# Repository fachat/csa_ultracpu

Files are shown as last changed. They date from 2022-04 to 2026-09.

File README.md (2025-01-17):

# Ultra-CPU

Note: this is a part of a larger set of repositories, with [upet_family](https://github.com/fachat/upet_family) as the main repository.

This is the CPU board for a re-incarnation of the Commodore PET or other computer(s) from the later 1970s.

It is build on a Eurocard board and has only parts that can still be obtained new in 2024.
It uses the [CS/A bus interface](http://www.6502.org/users/andre/csa/index.html) to use other I/O boards.

As the memory mapping is programmable using the FPGA on the board, multiple types of computers can
potentially re-created. I started with my favourite one, the Commodore PET.

The reason this board is called Ultra-CPU is because it can potentially be used to recreate not only the Commodore PET.
The downside compared to the Micro-PET is, that it needs a separate I/O board to re-create a Commodore PET.
This can be found [here on my CS/A page](http://www.6502.org/users/andre/csa/petio/index.html).

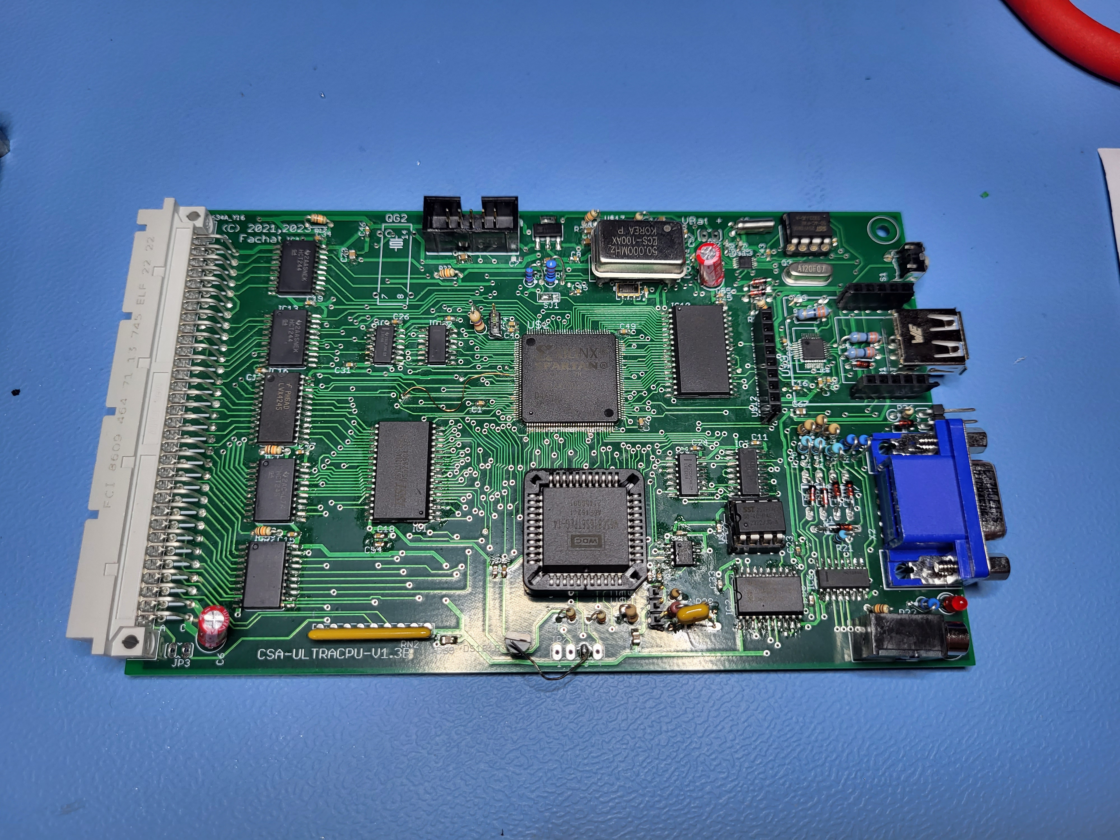
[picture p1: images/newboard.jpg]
The board


## Features

The board is built with a number of features:

- Commodore 3032 / 4032 / 8032 / 8296 with options menu to select at boot
  - Boot-menu to select different PET versions to run (BASIC 1, 2, 4)
  - 40 col character display
  - 80 col character display
- Improved system design:
  - 512k video RAM, plus 512k fast RAM, accessible using banks on the W65816 CPU
  - boot from an SPI Flash ROM
  - up to 17.5 MHz mode (via configuration register)
  - Write protection for the PET ROMs once copied to RAM
  - lower 32k RAM mappable from all of the 512k fast RAM
- Improved Video output:
  - VGA color video output (RGBI in 768x576 mode)
  - based on 720x576@60Hz VGA video timing (i.e. including borders at 40/80 columns)
  - modifyable character set
  - 40/80 column display switchable
  - 25/50 rows display switch
  - multiple video pages mappable to $8000 video mem address
  - Mulitple colour modes (Colour-PET, C128 VDC-compatible, Multicolour)
  - Colour Hires (VDC-compatible, Multicolour)
  - 16 colours out of a colour palette of 64 colours displayed simultaneously.
- DAC audio output
  - DMA engine to play audio samples on stereo sound output
- Built-in extra hardware:
  - USB host mode interface (for keyboard / mouse)
  - Real-Time-Clock (battery-buffered)
  - Ethernet/Wifi (via Breakout board)
  - SD-Card (via Breakout board)
- CS/A bus interface
  - multiple options to use bus devices, e.g. in I/O window
  - Together with [Ultra-Bus](https://github.com/fachat/csa_ultrabus) backplane Apple-II and RC2014 devices can be used

## Overview

The system architecture is actually rather simple, as you can see in the following graphics.

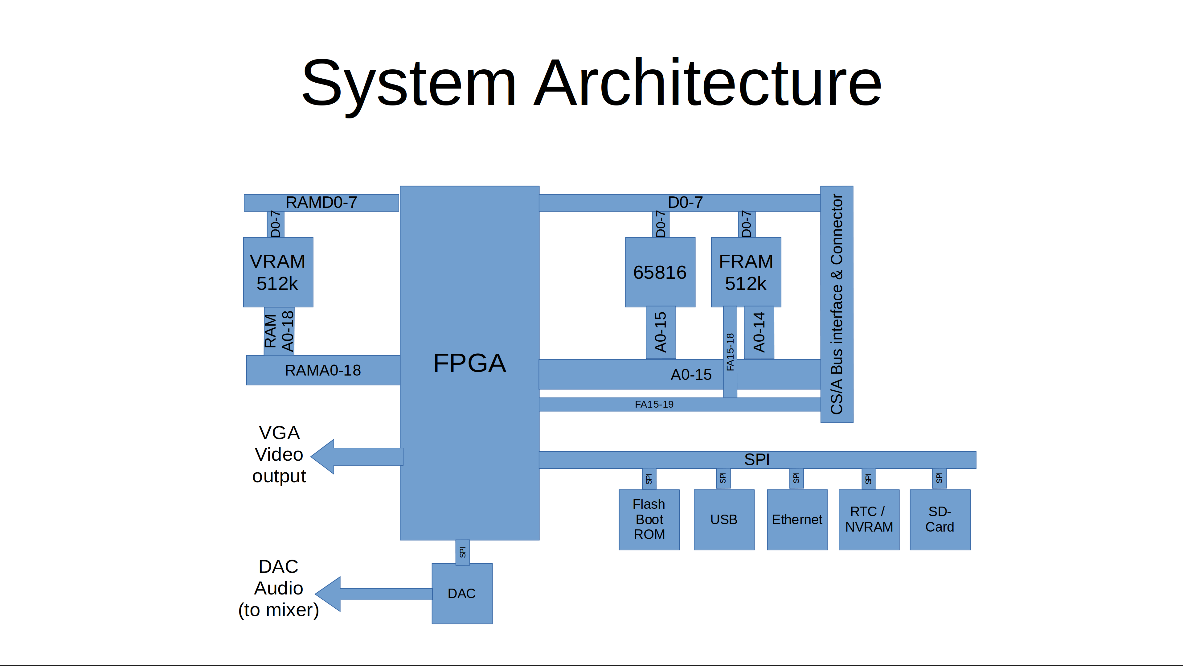
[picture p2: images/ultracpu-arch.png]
Ultra-CPU System Architecture


The main functionality is "hidden" inside the FPGA. It does:

1. clock generation and management
2. memory mapping
3. video generation.
4. SPI interface and boot

On the CPU side of the FPGA it is actually a rather almost normal 65816 computer, 
with the exception that the bank register (that catches and stores the address lines 
A16-23 from the CPU's data bus) is in the FPGA, and that there is no ROM. The ROM has been
replaced with some code in the FPGA that copies the initial program to the CPU accessible
RAM, taking it from the Flash Boot ROM via SPI. This actually simplifies the design,
as 

1. parallel ROMs are getting harder to come by and
2. they are typically not as fast as is needed, and
3. with the SPI boot they don't occupy valuable CPU address space.

The video generation is done using time-sharing access to the video RAM.
The VGA output is 720x576 at 50Hz. So there is a pixel clock of 27MHz.

The system runs at 13.5MHz, so a byte of pixel output (i.e. eight pixels) has four
memory accesses to VRAM. Two of them are reserved for video access, one for fetching the
character data (e.g. at $08xxx in the PET), and the second one to fetch the "character ROM"
data, i.e. the pixel data for a character. This is also stored in VRAM, and is being loaded
there from the Flash Boot ROM by the initial boot loader.

The FPGA reads the character data, stores it to fetch the character pixel data, and streams
that out using its internal video shift register.

For more detailled descriptions of the features and how to use them, pls see the 
[FPGA repository](https://github.com/fachat/upet_fpga),
as described in the next section.

## Version History

- [Revision 2.1A](https://github.com/fachat/csa_ultracpu/tree/r2.1a): Version using a Spartan 6 FPGA
- [Revision 1.3C](https://github.com/fachat/csa_ultracpu/tree/r1.3c): first working version using a Spartan 3E FPGA
- [Revision 1.2B](https://github.com/fachat/csa_ultracpu/tree/csa_ultracpu_1.2b): Version with CPLD and external colour generation.

## Known Issues

The following issues have been identified:

* Audio quality

Below are the fixes for these. Note, these are NOT yet in the BOM.

### Audio quality

The DAC audio output is not linear with the given schematics. This can be fixed by

* removing R30 and R32
* replace C3 and C10 with a 22uF  electrolytic cap. Orient minus pole to the output connector

## Building

Here are three subdirectories:

- [Board](Board/) That contains the board schematics and layout
- [Demo](Demo/) Some demo programs
- [tests](tests/) Some test programs

- [FPGA code](https://github.com/fachat/upet_fpga) This separate repository contains the VHDL code to program the FPGA logic chip used, and describes the configuration options - including the SPI and DAC usage and the Video feature and register description.
- [ROM](https://github.com/fachat/upet_roms) This separate repository contains the ROM contents to boot

### Board

To build the board, you have to find a provider that builds PCBs from Eagle .brd files.
Additionally, gerber files and a full Bill-of-material are provided in the Board subdirectory.

### FPGA

The FPGA is a Xilinx Spartan 6 programmable logic chip. It runs on 3.3V, 
so the bus interface has to convert between 3.3V and 5V. Compared to previous versions and the Micro-PET, also
the RAM and CPU on this board run on 3.3V now.
The FPGA logic here is programmed in VHDL.

The FPGA programming is actually stored in an SPI Flash Prom, so makes re-creating it even easier compared to 
the previous versions that used a CPLD - the CPLD required a separate programmer, now a (serial) Flash programmer suffices.

### ROM

The ROM image can be built using gcc, xa65, and make. Use your favourite EPROM programmer to burn it into the SPI Flash chip.

The ROM contains images of all required ROM images for BASIC 1, 2, and 4, and corresponding editor ROMs, including
some that have been extended with wedges and colour-PET functionality.

The updated editor ROMs are from [Steve's Editor ROM project](http://www.6502.org/users/sjgray/projects/editrom/index.html) and can handle C64 keyboards, has a DOS wedge included, and resets into the Micro-PET boot menu.

For more details see the [ROM repository](https://github.com/fachat/upet_roms)

## Gallery

### The system

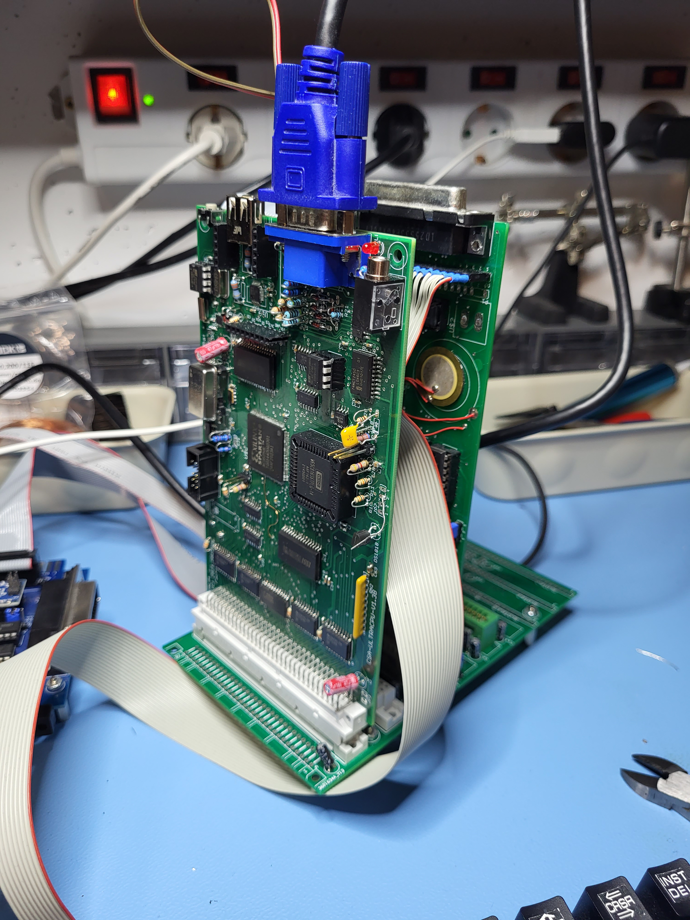
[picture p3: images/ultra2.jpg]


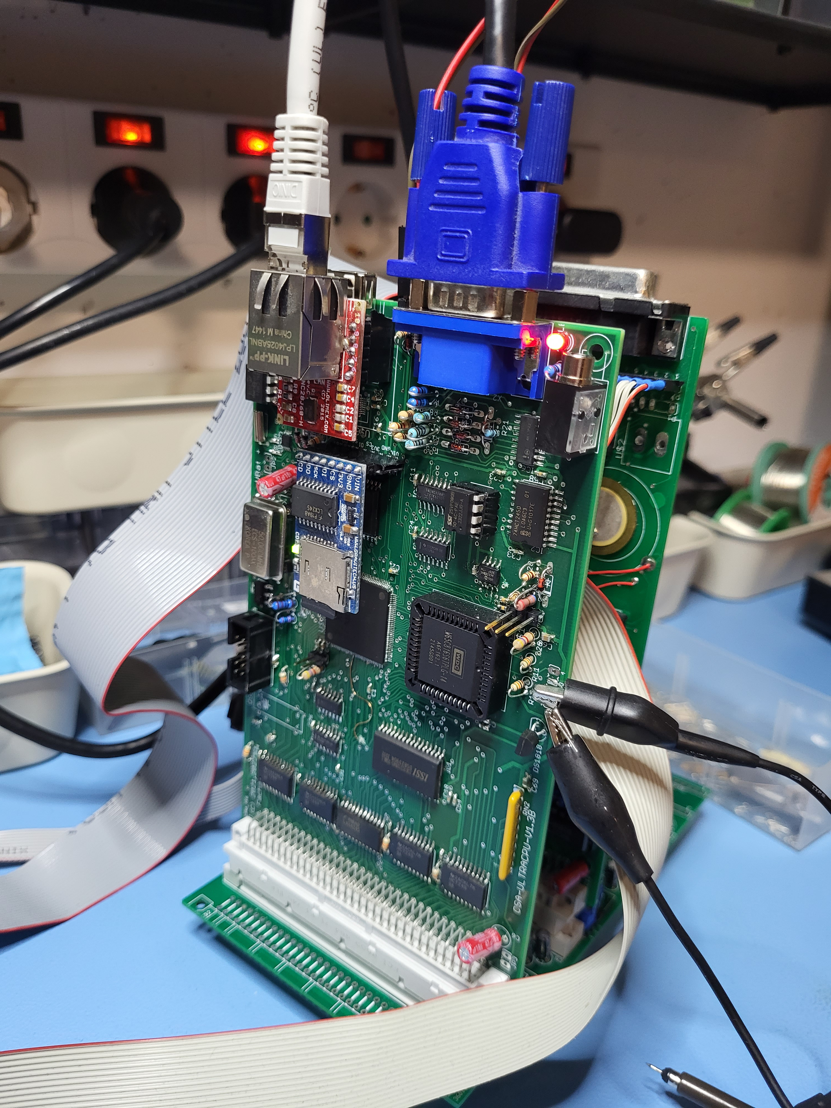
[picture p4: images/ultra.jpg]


### Graphics feature overview

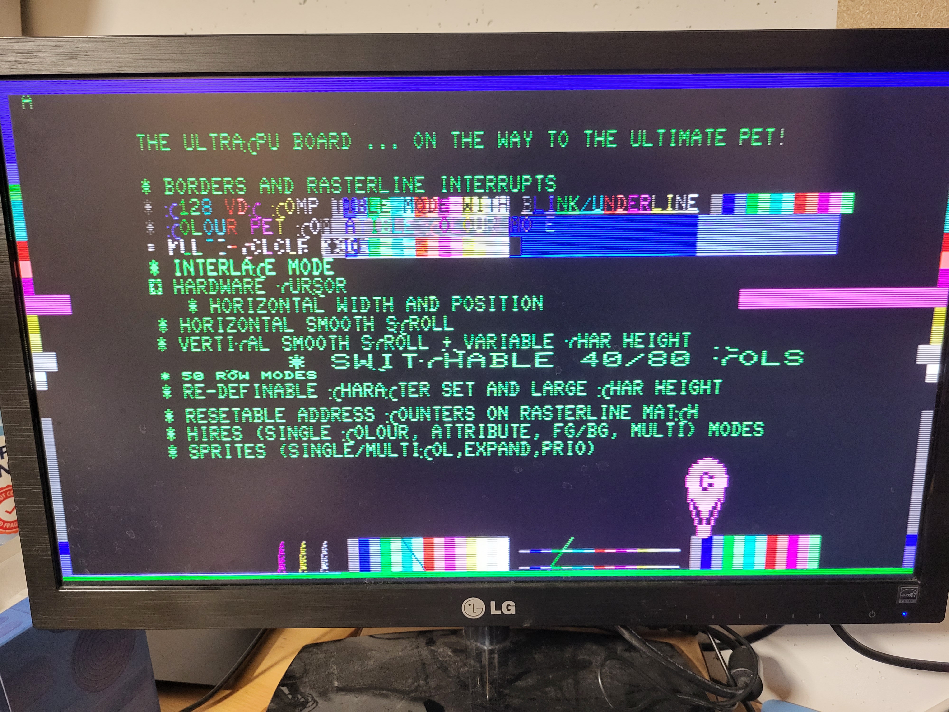
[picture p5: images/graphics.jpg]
Graphics feature overview


Note that this version is without the (optional) "Brown Fix" that is included in version 1.0B of the board.

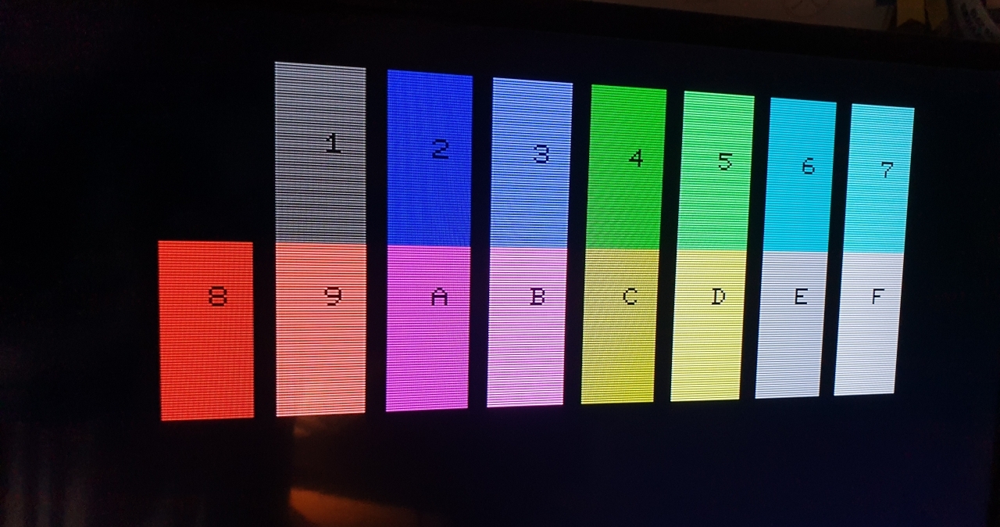
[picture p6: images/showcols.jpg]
Colour palette


### Board

The board

### Boot menu and OS boot screen

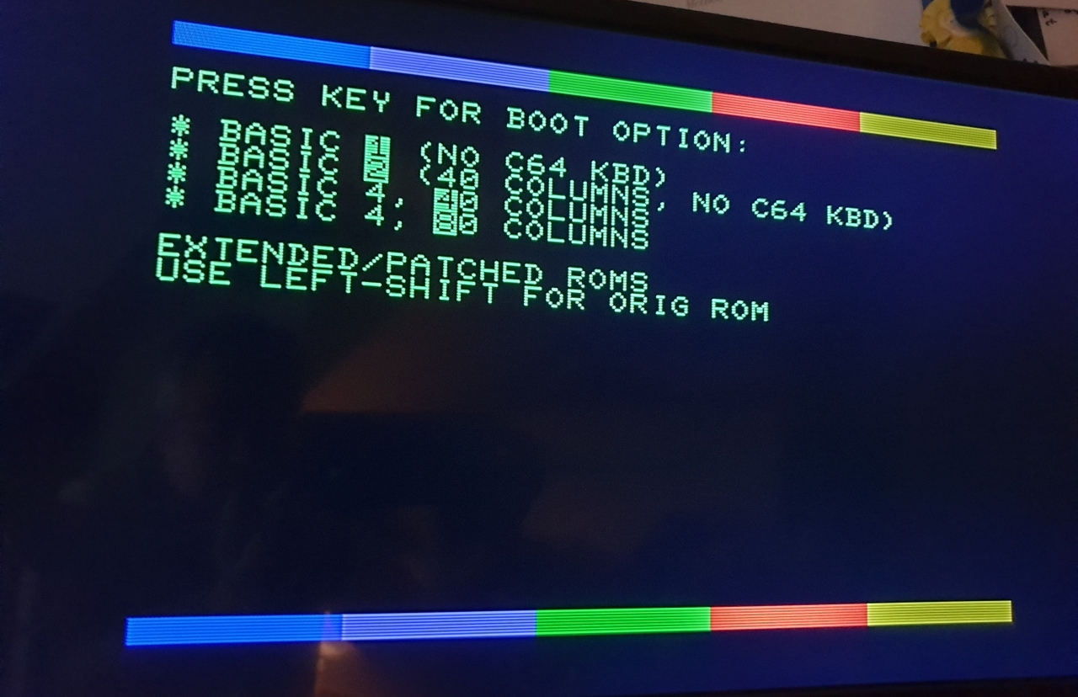
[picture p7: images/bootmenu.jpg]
Boot menu


OS Boot screen

### V1.2 system views

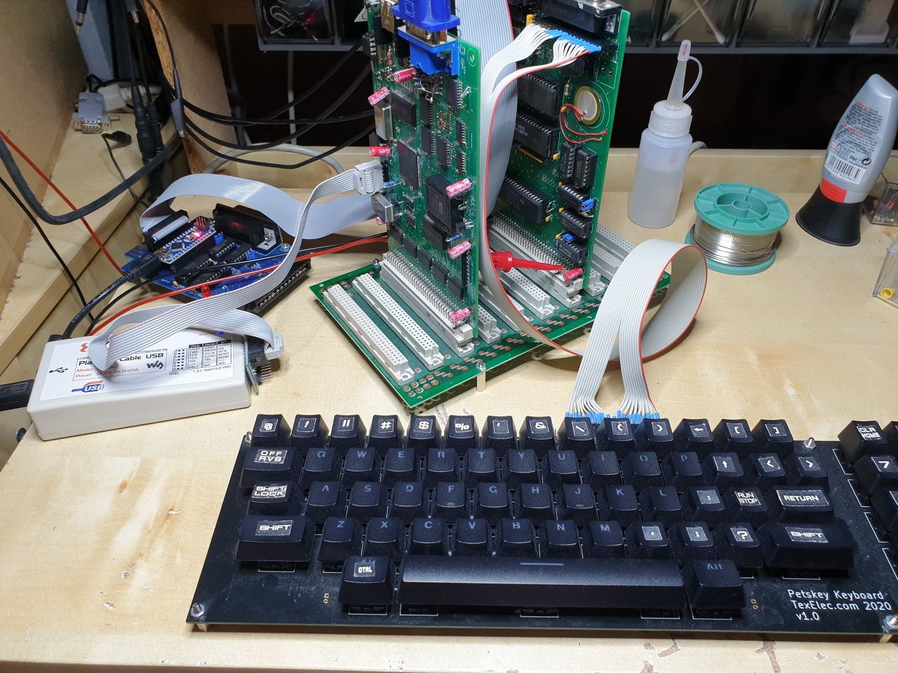
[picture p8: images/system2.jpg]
A full system with nano488 disk and keyboard


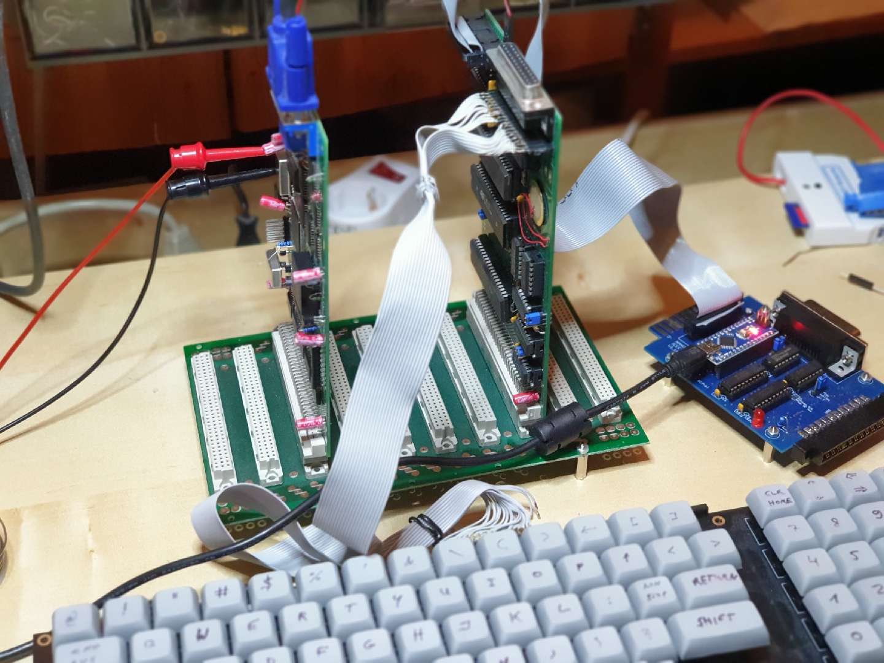
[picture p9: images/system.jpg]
Another view of a full system with nano488 disk and keyboard


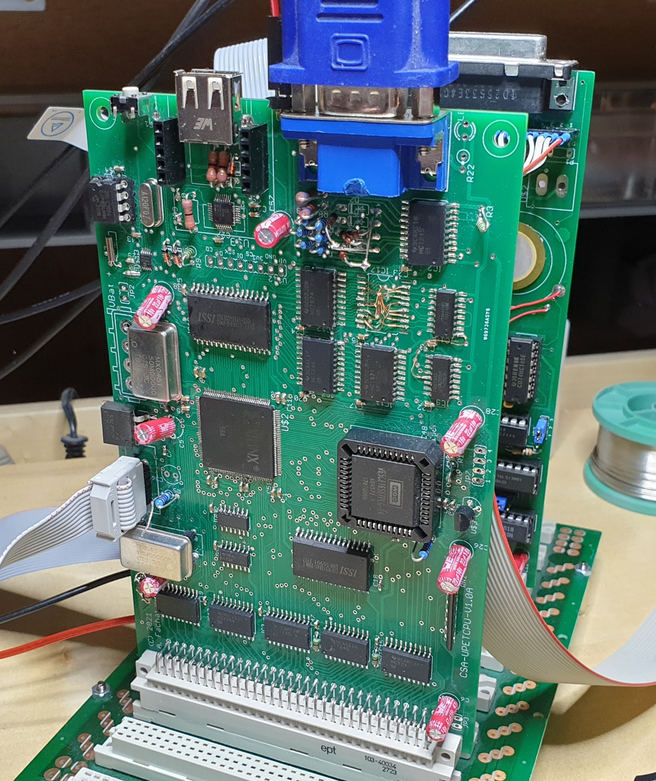
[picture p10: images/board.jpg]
Picture of an (V1.2) Ultra-CPU board


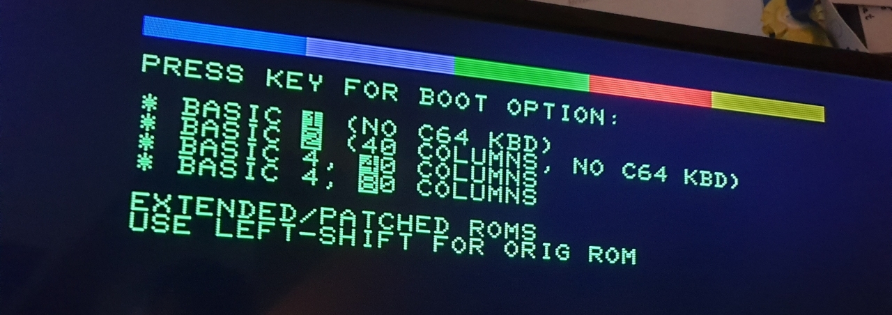
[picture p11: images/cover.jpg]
Picture of an (V1.2) Ultra-CPU board with PETIO board


### Debugging during development

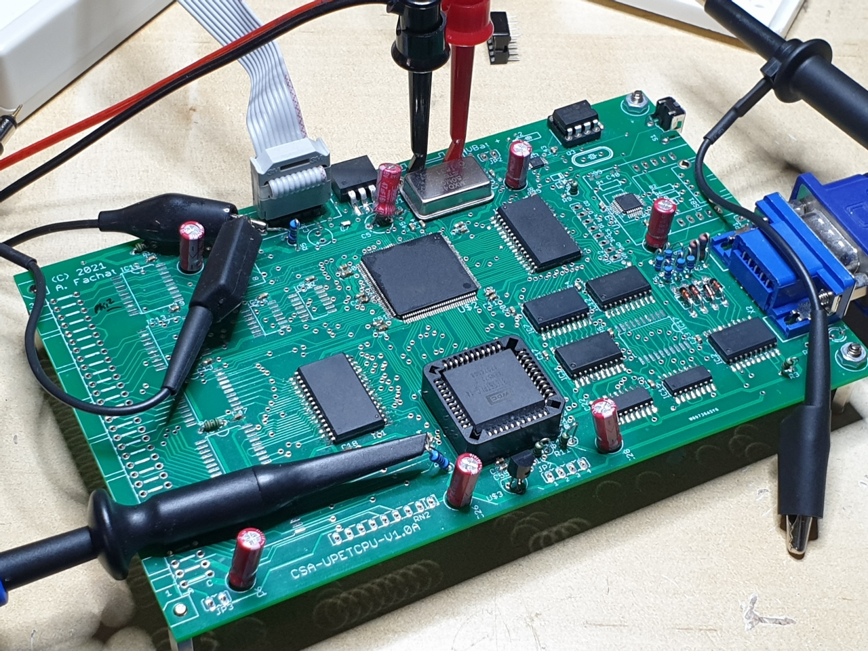
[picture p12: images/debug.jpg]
debug


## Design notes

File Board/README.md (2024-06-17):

# Board

The board is a two-layer Eurocard, i.e. 160mm x 100mm.

## Schematics & Layout

The schematics and layout have been created with Cadsoft Eagle.
So, here you can find the 

- [csa_ultracpu.sch](csa_ultracpu.sch) and
- [csa_ultracpu.brd](csa_ultracpu.brd) files

But, you can still have a look at the schematics and layout using the
PNG images created

- [csa_ultracpu_v2.0b-sch-1.png](csa_ultracpu_v2.0b-sch-1.png) Part 1 - CS/A Bus interface
- [csa_ultracpu_v2.0b-sch-2.png](csa_ultracpu_v2.0b-sch-2.png) Part 2 - CPLD, CPU, Fast RAM
- [csa_ultracpu_v2.0b-sch-3.png](csa_ultracpu_v2.0b-sch-3.png) Part 3 - Power
- [csa_ultracpu_v2.0b-sch-4.png](csa_ultracpu_v2.0b-sch-4.png) Part 4 - Video and Audio output
- [csa_ultracpu_v2.0b-sch-5.png](csa_ultracpu_v2.0b-sch-5.png) Part 5 - SPI devices (Eth, USB, RTCC, ...)
- [csa_ultracpu_v2.0b-sch-6.png](csa_ultracpu_v2.0b-sch-6.png) Part 6 - Video RAM, data fetch and shift register

- [csa_ultracpu_v2.0b-layout.png](csa_ultracpu_v2.0b-layout.png) layout of the chips
- [csa_ultracpu_v2.0b-brd.png](csa_ultracpu_v2.0b-brd.png) layout of the traces

## Bill of Material

The main chips are:

- 1x W65816S CPU
- 1x x Spartan 6 FPGA
- 2x 8x512k parallel SRAM with 25ns access time
- Several ICs for Video generation
- several ICs for the bus interface
- 1x DS1813 RESET controller

- 70 MHZ crystal oscillator
- 16 MHZ crystal oscillator (bus clock - may be optional)

- Voltage regulators

- bypass caps

- 1x LM2937-3.3V SOT
- div. resistors/caps to generate 3.3V output

More details can be found in the [Eagle parts list](csa_ultracpu.csv).

A full [BOM](csa_ultracpu_BOM.xlsx) with parts numbers from Mouser is now provided as well.

## Changelog

### V2.0B

This moves from the Spartan 3 to a Spartan 6, increases clock speed to 70 MHz for a 
higher resolutoin video output, and more.

### V1.3C

This is a technology change of the programmable logic from the CPLD to an FPGA.
The FPGA has the same footprint, but much more space for logic inside. 
This allowed to integrate proper colour support, bitmaps, sprites, and many more
graphics features. A DAC allows outputting digital sound. 

### V1.0B

This fixes couple of things I found in V1.0A:

- The order of the color/intensity signals was the wrong way around
- The A/B and G inputs of IC15 had been accidently swapped
- An optional second color buffer has been removed as timing was good enough for it not be needed
- An optional "brown fix" has been added.
- On the board, two bypass caps were placed under the CPU socket
- On the board, the JP1 connector has been turned 180 degrees to confirm existing boards

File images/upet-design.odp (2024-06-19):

## System Architecture

FA15-18

A0-15

D0-7

SPI

SPI

SPI

SPI

SPI

SPI

D0-7

RAM
A0-18

D0-7

CS/A Bus interface & Connector

A0-14

VRAM

512k

RAMD0-7

FPGA

D0-7

65816

FRAM

512k

RAMA0-18

VGA

Video

output

DAC

Audio

(to mixer)

A0-15

FA15-19

SPI

Flash
Boot
ROM

USB

Ethernet

RTC /
NVRAM

SD-
Card

DAC

## Memory Map (boot)

ipl

ipl

CPU address space (lower 1M)

64k
bank0

Banks 0 … 7

Banks 8 … 15

64k
bank0

64k 8296

Ext. bank

Banks 2 … 7

64k video
bank

Banks 9 … 15

512k FRAM

Physical address space

The CPLD can only write (the IPL code from Flash) to VRAM, so the initial

Mapping maps VRAM to banks 0-7 of the CPU

512k VRAM

## Memory Map

CPU address space (lower 1M)

0-32k

32-
64k

Banks 1 … 15

Any of 16

32k blocks

In FRAM

4k
V

Bank 0, or

8296 mem expansion

In bank 1

Any of four 2k positions in video bank

8k
Chr

rom

8k
Chr

64k
bank0

64k 8296

Ext. bank

Banks 2 … 7

64k video
bank

Banks 9 … 15

512k FRAM

Physical address space

512k VRAM

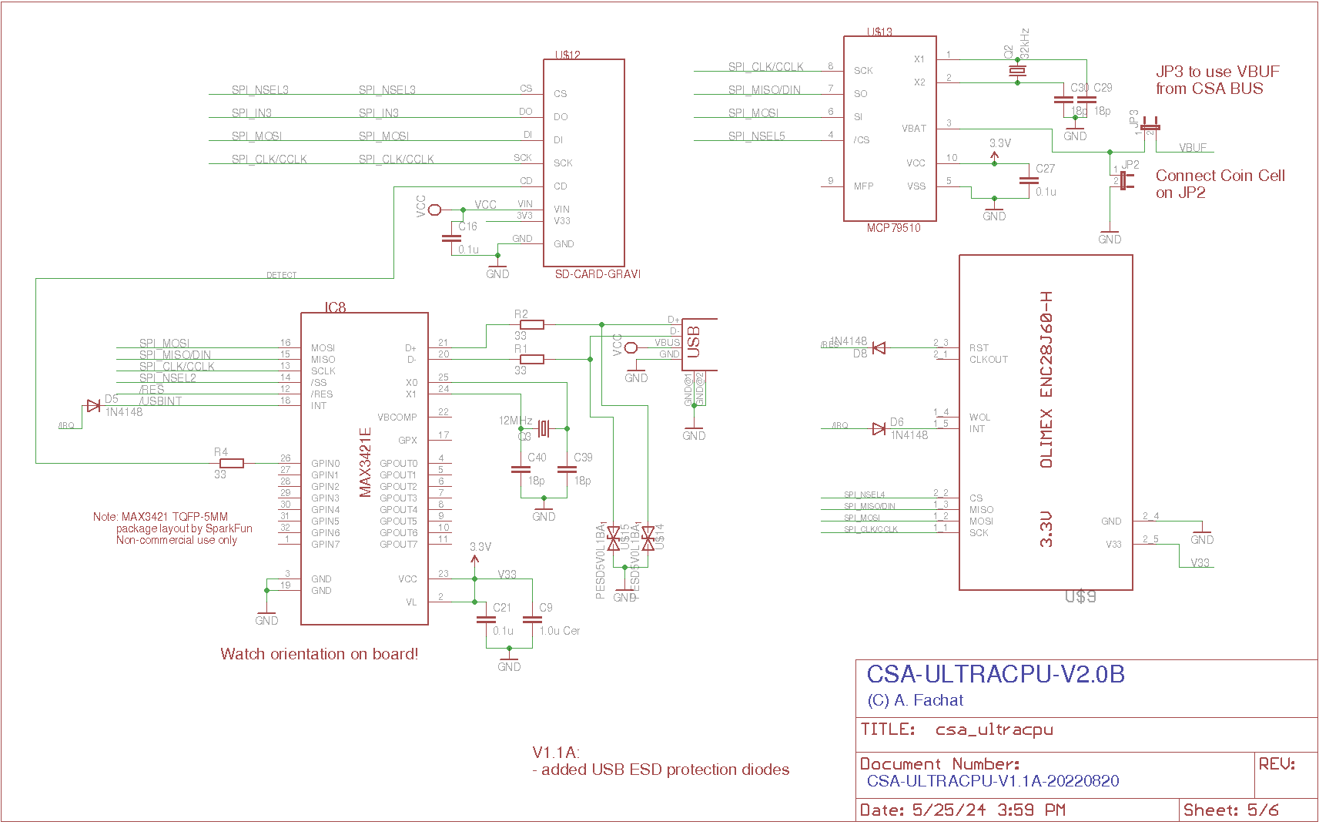
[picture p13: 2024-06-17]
Board/csa_ultracpu-v2.0b-sch-5.png

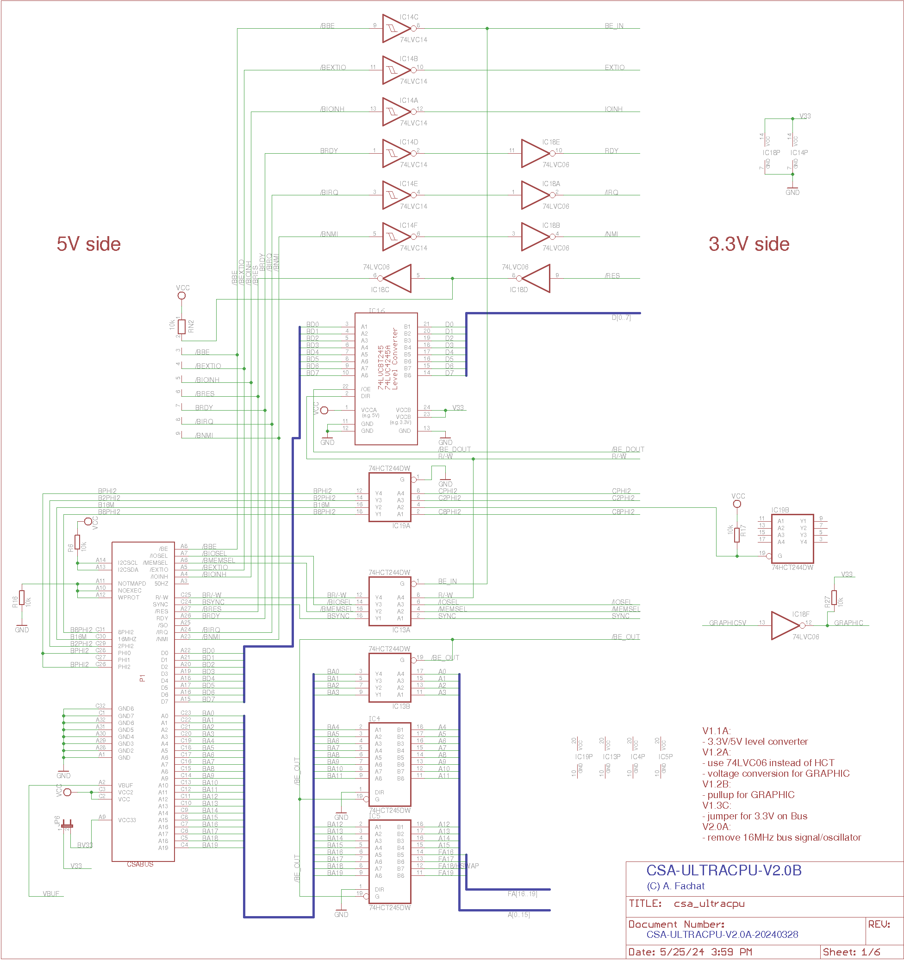
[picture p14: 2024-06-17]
Board/csa_ultracpu-v2.0b-sch-1.png

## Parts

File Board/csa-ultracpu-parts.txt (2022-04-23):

Partlist

Exported from csa_ultracpu.sch at 4/17/22 9:51 PM

EAGLE Version 6.4.0 Copyright (c) 1988-2013 CadSoft

Assembly variant: 

Part     Value              Device             Package          Library          Sheet

C1       0.1u               C-EUC0603          C0603            rcl              3
C2       0.1u               C-EUC0603          C0603            rcl              3
C3       0.1u               C-EUC0603          C0603            rcl              3
C4       0.1u               C-EUC0603          C0603            rcl              3
C5       47u                CPOL-EUE5-6        E5-6             rcl              3
C6       47u                CPOL-EUE2.5-6      E2,5-6           rcl              3
C7       100n               C-EUC0603          C0603            rcl              3
C8       100n               C-EUC0603          C0603            rcl              3
C9       1.0u Cer           C-EUC0603          C0603            rcl              5
C10      1u                 C-EUC0603          C0603            rcl              3
C11      1u                 C-EUC0603          C0603            rcl              3
C12      0.1u               C-EUC0603          C0603            rcl              3
C13      0.1u               C-EUC0603          C0603            rcl              3
C14      0.1u               C-EUC0603          C0603            rcl              3
C15      0.1u               C-EUC0603          C0603            rcl              3
C16      0.1u               C-EUC0603          C0603            rcl              5
C17      0.1u               C-EUC0603          C0603            rcl              3
C18      0.1u               C-EUC0603          C0603            rcl              3
C19      0.1u               C-EUC0603          C0603            rcl              3
C20      0.1u               C-EUC0603          C0603            rcl              3
C21      0.1u               C-EUC0603          C0603            rcl              5
C22      0.1u               C-EUC0603          C0603            rcl              3
C23      0.1u               C-EUC0603          C0603            rcl              3
C24      0.1u               C-EUC0603          C0603            rcl              3
C25      0.1u               C-EUC0603          C0603            rcl              3
C26      47u                CPOL-EUE2.5-6      E2,5-6           rcl              3
C27      0.1u               C-EUC0603          C0603            rcl              5
C28      22u                CPOL-EUE2.5-6      E2,5-6           rcl              3
C29      18p                C-EUC0603          C0603            rcl              5
C30      18p                C-EUC0603          C0603            rcl              5
C31      0.1u               C-EUC0603          C0603            rcl              3
C32      0.1u               C-EUC0603          C0603            rcl              3
C33      0.1u               C-EUC0603          C0603            rcl              3
C34      0.1u               C-EUC0603          C0603            rcl              3
C35      0.1u               C-EUC0603          C0603            rcl              3
C36      22u                CPOL-EUE2.5-6      E2,5-6           rcl              3
C37      22u                CPOL-EUE2.5-6      E2,5-6           rcl              3
C38      22u                CPOL-EUE2.5-6      E2,5-6           rcl              3
C39      18p                C-EUC0603          C0603            rcl              5
C40      18p                C-EUC0603          C0603            rcl              5
C41      0.1u               C-EUC0603          C0603            rcl              3
C42      0.1u               C-EUC0603          C0603            rcl              3
C43      0.1u               C-EUC0603          C0603            rcl              3
C44      0.1u               C-EUC0603          C0603            rcl              3
C45      0.1u               C-EUC0603          C0603            rcl              3
C46      0.1u               C-EUC0603          C0603            rcl              3
C47      0.1u               C-EUC0603          C0603            rcl              3
C48      0.1u               C-EUC0603          C0603            rcl              3
C49      1u                 C-EUC0603          C0603            rcl              3
C50      1u                 C-EUC0603          C0603            rcl              3
C51      1u                 C-EUC0603          C0603            rcl              3
C52      0.1u               C-EUC0603          C0603            rcl              3
C53      1u                 C-EUC0603          C0603            rcl              3
C54      1u                 C-EUC0603          C0603            rcl              3
C55      1u                 C-EUC0603          C0603            rcl              3
C56      1u                 C-EUC0603          C0603            rcl              3
C57      22u                CPOL-EUE2.5-6      E2,5-6           rcl              3
C58      0.1u               C-EUC0603          C0603            rcl              3
D1       1N4148DO35-7       1N4148DO35-7       DO35-7           diode            4
D2       1N4148DO35-7       1N4148DO35-7       DO35-7           diode            4
D3       1N4148DO35-7       1N4148DO35-7       DO35-7           diode            4
D4       1N4148DO35-7       1N4148DO35-7       DO35-7           diode            4
D5       1N4148             DIODE-D-5          D-5              diode            5
D6       1N4148             DIODE-D-5          D-5              diode            5
D7       1N4148DO35-7       1N4148DO35-7       DO35-7           diode            4
D8       1N4148             DIODE-D-5          D-5              diode            5
IC1      RAMSOCK32TO512KSOP RAMSOCK32TO512KSOP SOP32            csa              2
IC2      74LS245DW          74LS245DW          SO20W            74xx-eu          4
IC3      74LS245DW          74LS245DW          SO20W            74xx-eu          1
IC4      74LS245DW          74LS245DW          SO20W            74xx-eu          1
IC5      74LS245DW          74LS245DW          SO20W            74xx-eu          1
IC6      74ACT138D          74ACT138D          SO16             74xx-eu          4
IC7      74LS245DW          74LS245DW          SO20W            74xx-eu          6
IC8      MAX3421E           MAX3421E           TQFP32-5MM       csa              5
IC9      74LS166D           74LS166D           SO16             74xx-eu          6
IC10     RAMSOCK32TO512KSOP RAMSOCK32TO512KSOP SOP32            csa              6
IC11     74HCT574D          74HCT574D          SO20W            74xx-eu          6
IC12     74HCT574D          74HCT574D          SO20W            74xx-eu          6
IC13     74HCT244DW         74HCT244DW         SO20W            74xx-eu          1
IC14     74HCT14D           74HCT14D           SO14             74xx-eu          1
IC15     74HCT157D          74HCT157D          SO16             74xx-eu          6
IC18     74LS06D            74LS06D            SO14             74xx-eu          1
IC19     74HCT244DW         74HCT244DW         SO20W            74xx-eu          1
J1                          FLOPPY-4350211     350211           con-amp          3
JP1                         JP1E               JP1              jumper           2
JP2                         JP1E               JP1              jumper           5
JP3                         JP1E               JP1              jumper           5
JP7                         JP4E               JP4              jumper           2
LED1                        LED3MM             LED3MM           led              3
P1       CSABUS             CSABUS             CSABUS           csa              1
Q2       32kHz              CRYSTALTC26H       TC26H            crystal          5
Q3       12MHz              CRYSTALHC49S       HC49/S           crystal          5
QG1      50MHz              CRYSTAL_RES-SG51   SG51             crystal          2
QG2      16MHz              CRYSTAL_RES-SG51   SG51             crystal          1
R1       33                 R-EU_0204/7        0204/7           rcl              5
R2       33                 R-EU_0204/7        0204/7           rcl              5
R3       10k                R-EU_0204/2V       0204V            rcl              4
R4       33                 R-EU_0204/7        0204/7           rcl              5
R5       1k                 R-EU_0207/2V       0207/2V          rcl              2
R6       10k                R-EU_0204/5        0204/5           rcl              1
R7       68                 R-EU_0204/2V       0204V            rcl              4
R8       68                 R-EU_0204/2V       0204V            rcl              4
R9       10k                R-EU_0207/2V       0207/2V          rcl              2
R10      10k                R-EU_0207/2V       0207/2V          rcl              2
R11      10k                R-EU_0207/2V       0207/2V          rcl              2
R12      1k                 R-EU_0207/2V       0207/2V          rcl              2
R13      470                R-EU_0204/2V       0204V            rcl              4
R14      470                R-EU_0204/2V       0204V            rcl              4
R15      470                R-EU_0204/2V       0204V            rcl              4
R16      10k                R-EU_0204/5        0204/5           rcl              1
R17      10k                R-EU_0204/5        0204/5           rcl              1
R18      1k                 R-EU_0204/2V       0204V            rcl              4
R19      1k                 R-EU_0204/2V       0204V            rcl              4
R20      1k                 R-EU_0204/2V       0204V            rcl              4
R21      2k                 R-EU_0204/2V       0204V            rcl              4
R22      390                R-EU_0207/2V       0207/2V          rcl              3
RN2      10k                RN08               RN-9             resistor-net     1
S1                          31-XX              B3F-31XX         switch-omron     3
TO1      LM2937SOT-3.3V     LM2937SOT          SOT223           csa              3
U$1      W65C816SPLCC       W65C816SPLCC       PLCC44           csa              2
U$2      XC95288XLTQ144     XC95288XLTQ144     TQFP144          csa              2
U$3      DS1813             DS1813             TO92             csa              3
U$4      SPIFLASH           SPIFLASH           DIL08            csa              2
U$7      XILINXPROG         XILINXPROG         FLAT10BOX        csa              2
U$9      ETHOLIENC          ETHOLIENC          ETHOLIENC        csa              5
U$12     SD-CARD-GRAVI      SD-CARD-GRAVI      GRAVITECH-SDCARD csa              5
U$13     MCP79510           MCP79510           MSOP10           csa              5
USB1     USB-A-H            USB-A-H            USB-A-H          con-usb-2        5
X2       D-SUB15-HDR15RA    D-SUB15-HDR15RA    HDR15RA          con-thomas-betts 4

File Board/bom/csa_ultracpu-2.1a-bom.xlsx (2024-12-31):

Id | Designator | Footprint |  | Orig. Quantity | Designation | Supplier and ref | MOUSER | Manufac. Part | Alt. Mouser | Alt. Manufac. Part | JLCPCB Part #（optional）
 | SMD
 | C2, C7, C8, C11, C12, C13, C15, C16, C17, C18, C19, C20, C21, C22, C24, C25, C26, C27, C28, C31, C32, C33, C34, C35, C36, C37, C41, C42, C43, C44, C45, C46, C47, C48, C58, C101, C102, C103, C104, C105, C106, C107, C108, C109, C110, C111, C112, C113, C121 | C0603 | 49 |  | 0.1u |  | 581-06033G104ZAT2AM | 06033G104ZAT2AM |  |  | C14663
 | C1, C4, C9, C14, C49, C54, C55, C56, C57, C120, C123 | C0603 | 11 |  | 1u |  | 791-0603B105K6R3CT | 0603B105K6R3CT | 80-C0603X105J8R | C0603X105J8RACTU | C309479
 | C5, C38,C64, C65, C66, C67, C68, C69, C70, C71 | C0805 | 10 |  | 22u |  | 187-CL21A226MPQNNNE | CL21A226MPQNNNE |  |  | C5674
 | C29, C30, C39, C40 | C0603 | 4 |  | 18p |  | 80-C0603C180K4HACTU | C0603C180K4HACTU |  |  | C152921
 | R3, R5, R6, R9, R10, R11, R12, R16, R17, R24, R25, R26, R27 | R_0805_2012Metric_Pad1.20x1.40mm_HandSolder | 13 |  | 10k |  | 279-CRGH0603J10K | CRGH0603J10K |  |  | C17414
 | R1, R2, R4 | R_0805_2012Metric_Pad1.20x1.40mm_HandSolder | 3 |  | 33 |  | 660-RK73H2ATTD33R0F | RK73H2ATTD33R0F |  |  | C17634
 | U1, U2 | TSOP-II-44_10.16x18.41mm_P0.8mm | 2 |  | IS61C5128AL-10TLI |  | 913-AS7C34096A-10TIN | AS7C34096A-10TIN |  |  | C5554776
 | X3 | Oscillator_SMD_SeikoEpson_SG8002CE-4Pin_3.2x2.5mm | 1 |  | 54MHz Oscrillator |  | 710-830207670409 | 830207670409 |  |  | C1672093
38 | U$14,U$6,U$10,U$5,U$8,U$11,U$15 | SOD323 | 7 |  | ESDBIDIR |  | 771-PESD5V0L1BA-T/R | PESD5V0L1BA,115 |  |  | C2687118
93 | IC5,IC2,IC4 | SO20W@1 | 3 |  | 74245DW |  | 595-SN74HCT245DWR | SN74HCT245DWR |  |  | C132267
64 | IC19,IC13 | SO20W@1 | 2 |  | 74244DW |  | 595-SN74HCT244DWRG4 | SN74HCT244DWRG4 |  |  | C6776
72 | IC3 | SO14@1 | 1 |  | 74125D |  | 595-SN74LVC125AD | SN74LVC125AD |  |  | C6057
109 | IC6 | SOT-23-5 | 1 |  | 74LVC1G04 |  | 595-SN74LVC1G04DBVR | SN74LVC1G04DBVR |  |  | C7434171
107 | IC7 | SO16 | 1 |  | 74138D |  | 771-74LVC138AD-T | 74LVC138AD,118 |  |  | C6061
68 | IC8 | PQFP-32_5x5mm_P0.5mm | 1 |  | MAX3421E |  | 700-MAX3421EEHJT | MAX3421EEHJ+T |  |  | C2651881
152 | IC14 | SO14 | 1 |  | 7414D |  | 595-SN74LV14ADR | SN74LV14ADR |  |  | C133541
57 | IC18 | SO14 | 1 |  | 7406D |  | 595-SN74LVC06ADR | SN74LVC06ADR |  |  | C7658
86 | IC16 | SO24L | 1 |  | 74LVC8T245SO24 |  | 595-SN74LVC4245ADW | SN74LVC4245ADW |  |  | C2677625
59 | SN1 | SOIC8 | 1 |  | MCP48X2 |  | 579-MCP4802-E/SN | MCP4802-E/SN |  |  | C144363
81 | U$2 | TQFP144 | 1 |  | XC6SLX9-TQG144 |  | 217-XC6SLX9-2TQG144C | XC6SLX9-2TQG144C |  |  | C415799
116 | U$3 | SOT223 | 2 |  | LDI1117 |  | 637-LDI1117-3.3H | LDI1117-3.3H |  |  | C6186
148 | U$13 | MSOP10 | 1 |  | MCP79510 |  | 579-MCP79510-I/MS | MCP79510-I/MS |  |  | C636437
3 | U$16 | PSOP-8-FIXED | 1 |  | AP2132BB |  | 621-AP2132BMP1.2TRG1 | AP2132BMP-1.2TRG1 |  |  | C338874
 | Pins and Jumper
11 | JP1, JP2, JP3, JP4, JP6, JP12, JP13 | JP1 | 0 | 7 | JP1E
26 | JP5 | JP2 | 0 | 1 | JP2E
35 | JP8, JP9, JP10, JP11 | PinHeader_1x01_P2.54mm_Vertical | 0 | 4 | Conn_01x01_Pin
112 | JP7 | JP4 | 0 | 1 | JP4E
 |  |  | 2 |  | pin strip straight 20 pin |  | 538-22-28-4204 | 22-28-4204 | 649-1012937892001BLF | 10129378-920001BLF
 | ICs
141 | U$1 | PLCC44 | 1 |  | W65C816SPLCC |  | 955-W65C816S6PLG-14 | W65C816S6PLG-14
43 | U$4,U$18 | DIL08 | 2 |  | SPIFLASH |  | 804-25VF080B5CPAE | SST25VF080B-50-4C-PAE
138 | DS1818 | TO92 | 1 |  | DS1813 |  | 700-DS1818-10T&R | DS1818-10+T&R
 | Capacitors
 | C3, C10 | C_Disc_D5.0mm_W2.5mm_P5.00mm | 2 |  | 1u MLCC |  | 810-FG28X5R1H105KRT0 | FG28X5R1H105KRT00
 | C6 | E2,5-6 | 1 |  | 47u |  | 710-860010372004 | 860010372004
 | Resistors
 | R7, R8 | 0204V | 2 |  | 68 |  | 660-MF1/4LCT52R680G | MF1/4LCT52R680G
 | R28, R31 | 0204V | 2 |  | 100 |  | 603-MFR-12FTF52-100R | MFR-12FTF52-100R
 | R29 | 0207_2V | 1 |  | 330 |  | 603-MFR-12FTF52-330R | MFR-12FTF52-330R
 | R22 | 0207_2V | 1 |  | 390 |  | 756-MFR3-390RFC | MFR3-390RFC | 603-MFR-25FBF52-390R | MFR-25FBF52-390R
 | R13, R14, R15 | 0204_7 | 3 |  | 470 |  | 708-RNF14FTD470R | RNF14FTD470R
 | R30, R32 | 0207_2V | 2 |  | 680 |  | 603-MFR-12FTF52-680R | MFR-12FTF52-680R
 | R18, R19, R20 | 0207_10 | 3 |  | 1k |  | 603-MFR-12FRF521K | MFR-12FRF52-1K | 603-MFR-12FTF52-1K | MFR-12FTF52-1K
54 | RN2 | RN-9 | 1 |  | 10k |  | 652-4609X-1LF-10K | 4609X-101-103LF
 | Diodes
 | D1, D2, D3, D4, D5,D6,D7,D8,D9, D10 | DO35-7 | 10 |  | 1N4148DO35-7 |  | 78-1N4148 | 1N4148TR | 512-1N4148 | 1N4148
23 | LED1 | LED3MM | 2 |  | LED3MM (Green – power) |  | 696-SSL-LX305F4GD | SSL-LX305F4GD
 | Connectors
98 | X1 | 1503_09 | 1 |  | 1503_09 |  | 490-SJ1-3515 | SJ1-3515 | 490-SJ1-3515N | SJ1-3515N
115 | X2 | HDR15RA | 1 |  | D-SUB15-HDR15RA |  | 523-7HDE15SD1CH4FVGA | L77HDE15SD1CH4FVGA
151 | U$7 | FLAT10BOX | 1 |  | XILINXPROG (optional) |  | 710-61201021621 | 61201021621
122 | U$9 | ETHOLIENC | 1 |  | ETHOLIENC (optional) |  | 909-ENC28J60-H | ENC28J60-H
 |  |  | 2 |  | Sockel |  | 200-SSW10501TS | SSW-105-01-T-S | 200-BCS105LSTE | BCS-105-L-S-TE
~~89~~ | ~~U$12~~ | ~~GRAVITECH-SDCARD~~ | 1 | ~~1~~ | ~~SD-CARD-GRAVI~~ |  | ~~992-MICROSD-ADP ~~ | ~~MICROSD-ADP ~~
 |  |  | 1 |  | Sockel |  | 200-BCS108LSTE | BCS-108-L-S-TE
99 | USB1 | USB-A-H | 1 |  | USB-A-H |  | 710-614004190021 | 614004190021
156 | P1 | CSABUS | 1 |  | CSABUS |  | 649-869464713745ELF | 86094647113745ELF |  |  | 649-869464713H45ELF | 86094647113H45ELF
 | Quartz
69 | Q2 | TC26H | 1 |  | 32kHz |  | 520-ECS-32-12.5-13X | ECS-.320-12.5-13X | 710-830002995B | 830002995B
136 | Q3 | HC49_S | 1 |  | 12MHz |  | 549-CYS6Q31C-12MHZ | CYS6Q31C-12.000MHZ
 | Switches
27 | S1 | B3F-31XX | 1 |  | 31-XX |  | 653-B3F-3122 | B3F-3122
 | Sockets
 |  |  | 2 |  | Socker 8 pin |  | 571-1-2199298-2 | 1-2199298-2
 |  |  | 1 |  | Socket 44 pin PLCC |  | 517-8444-11B1-RK-TP | 8444-11B1-RK-TP | 737-PLCC-44-AT | PLCC-44-AT
 | Extras

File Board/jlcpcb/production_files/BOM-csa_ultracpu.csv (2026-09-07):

Comment | Designator | Footprint | LCSC | Quantity
0.1u | C101,C102,C103,C104,C105,C106,C107,C108,C109,C11,C110,C111,C112,C113,C12,C121,C13,C15,C16,C17,C18,C19,C2,C20,C21,C22,C24,C25,C26,C27,C28,C31,C32,C34,C35,C36,C37,C41,C42,C43,C44,C45,C46,C47,C48,C58 | C0603 | C14663 | 46
100 | R28,R31 | R_0603_1608Metric_Pad0.98x0.95mm_HandSolder | C22775 | 2
100n | C50,C51,C52,C53,C59,C60,C61,C62,C63,C7,C72,C73,C8 | C_0603_1608Metric_Pad1.08x0.95mm_HandSolder | C14663 | 13
10k | R10,R11,R12,R16,R17,R18,R24,R26,R27,R3,R5,R6,R9 | R_0805_2012Metric_Pad1.20x1.40mm_HandSolder | C17414 | 13
10k | RN2 | RN-9 | C8692 | 1
12MHz | Q3 | HC49_S | C16369 | 1
18p | C29,C30,C39,C40 | C0603 | C1647 | 4
1N4148 | D5,D6,D8 | D-5 | C402212 | 3
1N4448 | D9 | D_SOD-123 | C2128 | 1
1k | R13,R14,R7,R8 | R_0603_1608Metric_Pad0.98x0.95mm_HandSolder | C21190 | 4
1u | C1,C10,C120,C123,C14,C3,C4,C49,C54,C55,C56,C57,C9 | C0603 | C15849 | 13
22u | C38,C5,C64,C65,C66,C67,C68,C69,C70,C71,C74 | C0805 | C45783 | 11
31-XX | S1 | B3F-31XX | C231320 | 1
32kHz | Q2 | TC26H | C3013591 | 1
33 | R1,R2,R4 | R_0805_2012Metric_Pad1.20x1.40mm_HandSolder | C17634 | 3
330 | R15 | C_0603_1608Metric_Pad1.08x0.95mm_HandSolder | C23138 | 1
390 | R22 | R_0603_1608Metric_Pad0.98x0.95mm_HandSolder | C23151 | 1
47u | C23,C33,C6 | C_0805_2012Metric_Pad1.18x1.45mm_HandSolder | C16780 | 3
680 | R30,R32 | R_0603_1608Metric_Pad0.98x0.95mm_HandSolder | C23228 | 2
741G04DBV | IC6 | SOT23-5 | C434067 | 1
74244DW | IC13,IC19 | SO20W | C6776 | 2
74HCT245DW | IC4,IC5 | SO20W | C132267 | 2
74LVC06 | IC18 | SO14 | C7658 | 1
74LVC125 | IC1,U2 | SO14 | C6057 | 2
74LVC14 | IC14 | SO14 | C133541 | 1
74LVC8T245SO24 | IC16 | SO24L | C2677625 | 1
AP2132B-1.2 | U$16 | PSOP-8-FIXED | C338874 | 1
Battery_Cell | BT1 | Kinghelm CR2032 Holder | C5365915 | 1
CSABUS | P1 | CSABUS | C5173362 | 1
DS1818 | DS1818 | SOT-23 | C143298 | 1
HDMI_A | J1 | HDMI_A_Molex_208658-1001_Horizontal | C138388 | 1
IS61WV51216EDALL | U1,U5 | TSOP-II-44_10.16x18.41mm_P0.8mm | C57407 | 2
JP1E | JP12,JP13,JP2,JP3,JP6 | JP1 | C234182 | 5
JP1E | JP1 | PinHeader_1x02_P2.54mm_Horizontal | C54570432 | 1
JP2E | JP15,JP5 | JP2 | C587036 | 2
JP4E | JP7 | JP4 | C587039 | 1
LDI1117 | U$3 | SOT223 | C6186 | 1
LED3MM | LED1 | LED3MM | C85161 | 1
MAX3421E | IC8 | VQFN-32-1EP_5x5mm_P0.5mm_EP3.15x3.15mm | C1870151 | 1
MCP48X2 | SN1 | SOIC8 | C144363 | 1
MCP79510 | U$13 | MSOP10 | C627708 | 1
Micro_SD_Card_Det2 | J2 | microSD_HC_Molex_104031-0811 | C585350 | 1
PESD5V0L1BA | U$14,U$15 | SOD323 | C2687118 | 2
SD-CARD-GRAVI | U$12 | GRAVITECH-SDCARD | C27438 | 1
SG-8002CE | X3 | Oscillator_SMD_SeikoEpson_SG8002CE-4Pin_3.2x2.5mm | C2831398 | 1
SJ1-3513N | X1 | 1503_09 | C145814 | 1
SPIFLASH | U$18,U$4 | DIL08 | C72124 | 2
USB-A-H | USB1 | USB-A-H | C456018 | 1
W65C816SPLCC | U$1 | PLCC44 | C72279 | 1
XC6SLX25-CSG324 | U4 | Xilinx_CSG324 | C169795 | 1
XILINXPROG | U$2 | FLAT10BOX | C5665 | 1
~ | U3 | Diodes_ZL32_TQFN-32-1EP_3x6mm_P0.4mm_EP1.25x3.5mm | C2674182 | 1

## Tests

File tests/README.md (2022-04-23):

# Unit tests

## virtpet (TODO)

This little test program shows the mapping features for the lower 32k, as well as the video memory window (where the
$8xxx area in CPU address space is mapped to video memory). 
It installs itself as a terminate-and-stay-resident (TSR), and checks when both SHIFT keys are pressed at the same time.
It then switches to the next of a total of four "virtual" PETs.

## low32k / map (TODO)

These tests check the functionality to re-map the low 32k in bank 0 CPU address space into one of 16 32k-banks
in the 512k RAM chip.

### low32k  (TODO)

This writes a signature into (almost) every block in each bank, and checks in a second pass if none of the
signatures have been overwritten.

Note that it will mangle the system font, as it writes the RAM signature there as well.

### map (TODO)

This are (will be) small routines that can be used from the machine language monitor to fill / exchange 
data from other banks.

## ROM tests (TODO)

### readflash

Reads the flash memory from BASIC

### romtest (TODO)

- romtest01(a).a65: This test program fills bank 1 continuously with an increasing value. This can be used to check the hires mode. The output o
f its build has to be copied into the top 4k of the ROM to boot/run
- romtest02(a).a65: This test program copies an 8k character ROM image from start of the ROM to start of bank 7, where the video code takes its 
character information. Then fills the character screen, and continuously increase the value in the character screen at $008000. This tests the c
haracter display output. The output of its build has to be copied into the top 4k of the ROM to boot/run

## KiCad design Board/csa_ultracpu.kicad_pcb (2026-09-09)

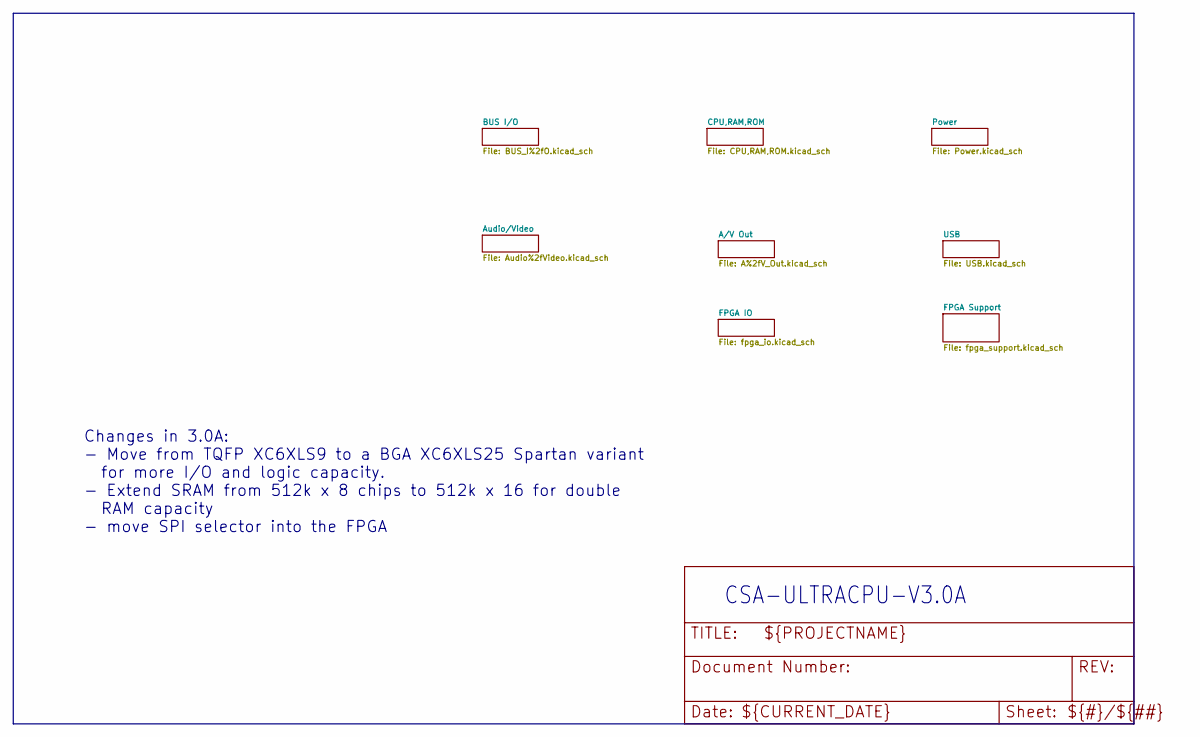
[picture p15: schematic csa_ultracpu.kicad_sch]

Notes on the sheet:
Changes in 3.0A: - Move from TQFP XC6XLS9 to a BGA XC6XLS25 Spartan variant for more I/O and logic capacity. - Extend SRAM from 512k x 8 chips to 512k x 16 for double RAM capacity - move SPI selector into the FPGA
CSA-ULTRACPU-V3.0A

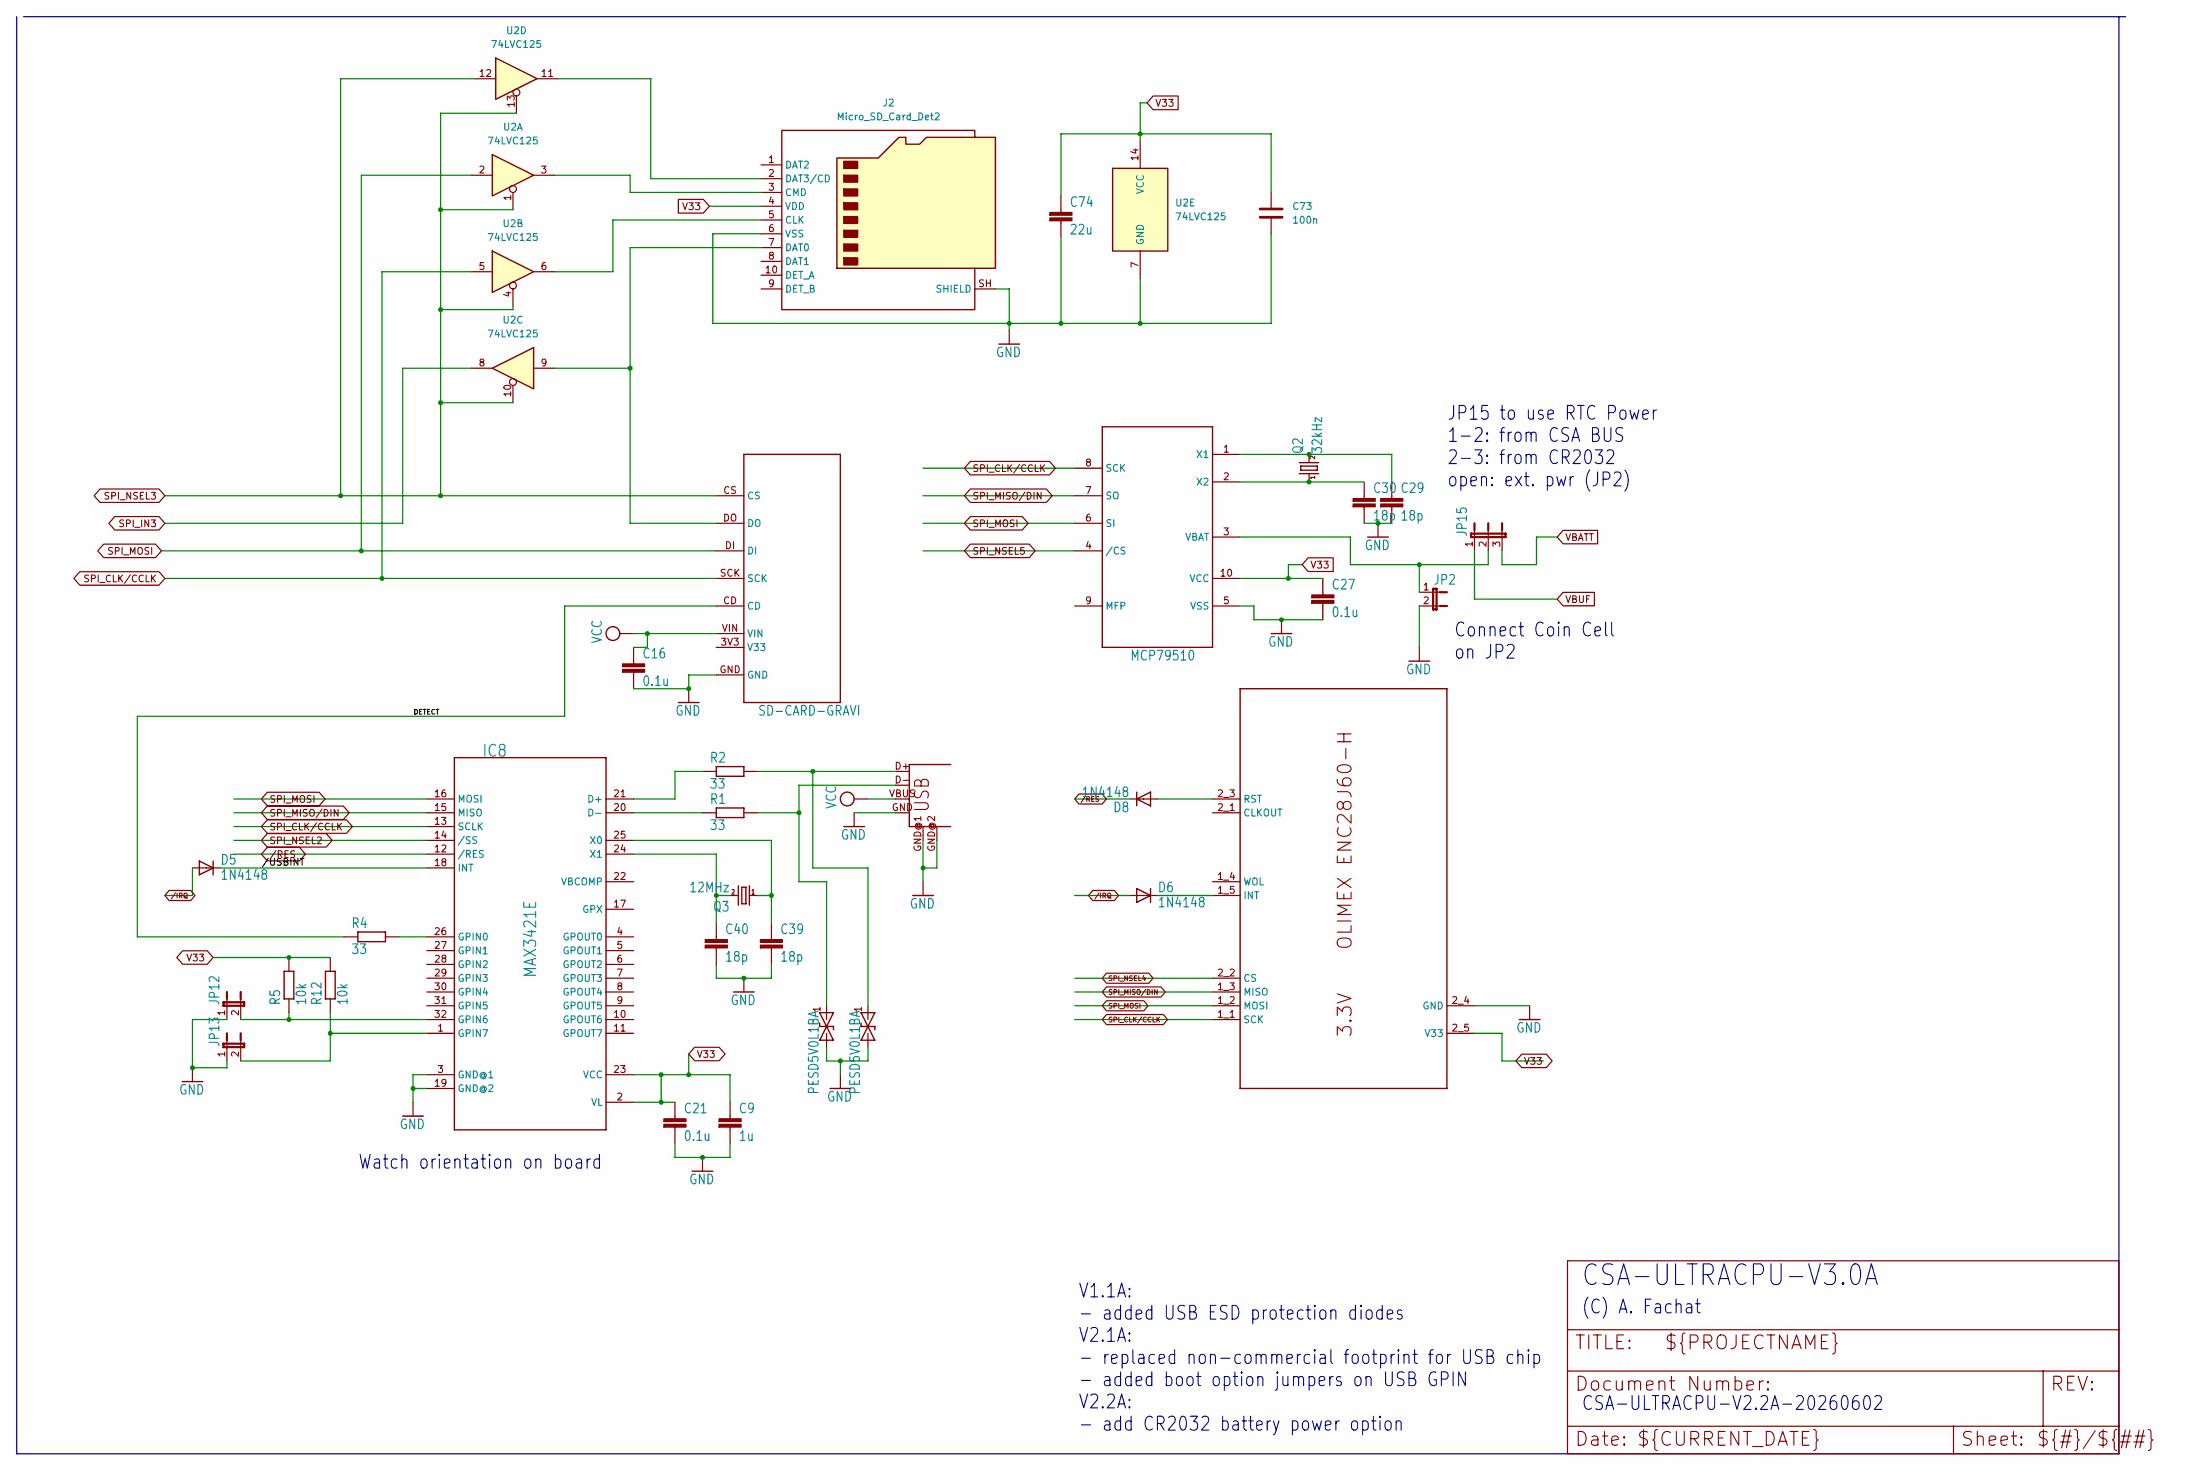
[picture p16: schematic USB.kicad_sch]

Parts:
C9: 1u; C0603; LCSC C15849
C16, C21, C27: 0.1u; C0603; LCSC C14663
C29, C30, C39, C40: 18p; C0603; LCSC C1647
C73: 100n; C_0603_1608Metric_Pad1.08x0.95mm_HandSolder; LCSC C14663
C74: 22u; C0805; LCSC C45783
D5, D6, D8: 1N4148; D-5; LCSC C402212
IC8: MAX3421E; VQFN-32-1EP_5x5mm_P0.5mm_EP3.15x3.15mm; LCSC C1870151
J2: Micro_SD_Card_Det2; microSD_HC_Molex_104031-0811; LCSC C585350
JP2, JP12, JP13: JP1E; JP1; LCSC C234182
JP15: JP2E; JP2; LCSC C587036
Q2: 32kHz; TC26H; LCSC C3013591
Q3: 12MHz; HC49_S; LCSC C16369
R1, R2, R4: 33; R_0805_2012Metric_Pad1.20x1.40mm_HandSolder; LCSC C17634
R5, R12: 10k; R_0805_2012Metric_Pad1.20x1.40mm_HandSolder; LCSC C17414
U2: 74LVC125; SO-14_3.9x8.65mm_P1.27mm; LCSC C6057
U$9: ETHOLIENC
U$12: SD-CARD-GRAVI; GRAVITECH-SDCARD; LCSC C27438
U$13: MCP79510; MSOP10; LCSC C627708
U$14, U$15: PESD5V0L1BA; SOD323; LCSC C2687118
USB1: USB-A-H; LCSC C456018

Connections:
/USB/DETECT: R4.1, U$12.CD
/USB//USBINT: D5.C, IC8.18 (INT)
GND: C9.2, C16.2, C21.2, C27.2, C29.2, C30.2, C39.2, C40.2, C73.2, C74.2, IC8.3 (GND@1), IC8.19 (GND@2), J2.6 (VSS), J2.SH (SHIELD), JP2.2, JP12.1, JP13.1, U2.7 (GND), U$9.2_4 (GND), U$12.GND, U$13.5 (VSS), U$14.1 (2), U$15.1 (2), USB1.GND, USB1.GND@1, USB1.GND@2; also elsewhere on the board
unnamed: IC8.21 (D+), R2.1
unnamed: IC8.20 (D-), R1.1
unnamed: IC8.26 (GPIN0), R4.2
unnamed: IC8.32 (GPIN6), JP12.2, R5.1
unnamed: IC8.1 (GPIN7), JP13.2, R12.1
unnamed: C39.1, IC8.25 (X0), Q3.1
unnamed: C40.1, IC8.24 (X1), Q3.2
unnamed: J2.5 (CLK), U2.6
unnamed: J2.3 (CMD), U2.3
unnamed: J2.7 (DAT0), U2.9, U$12.DO
unnamed: J2.2 (DAT3/CD), U2.11
unnamed: D6.C, U$9.1_5 (INT)
unnamed: D8.A, U$9.2_3 (RST)
unnamed: JP2.1, JP15.2, U$13.3 (VBAT)
unnamed: C29.1, Q2.2, U$13.1 (X1)
unnamed: C30.1, Q2.1, U$13.2 (X2)
unnamed: R2.2, U$14.2 (1), USB1.D+
unnamed: R1.2, U$15.2 (1), USB1.D-
SPI_CLK/CCLK: IC8.13 (SCLK), U2.5, U$9.1_1 (SCK), U$12.SCK, U$13.8 (SCK); also elsewhere on the board
SPI_IN3: U2.8; also elsewhere on the board
SPI_MISO/DIN: IC8.15 (MISO), U$9.1_3 (MISO), U$13.7 (SO); also elsewhere on the board
SPI_MOSI: IC8.16 (MOSI), U2.2, U$9.1_2 (MOSI), U$12.DI, U$13.6 (SI); also elsewhere on the board
SPI_NSEL2: IC8.14 (/SS); also elsewhere on the board
SPI_NSEL3: U2.1, U2.4, U2.10, U2.12, U2.13, U$12.CS; also elsewhere on the board
SPI_NSEL4: U$9.2_2 (CS); also elsewhere on the board
SPI_NSEL5: U$13.4 (/CS); also elsewhere on the board
V33: C9.1, C21.1, C27.1, C73.1, C74.1, IC8.2 (VL), IC8.23 (VCC), J2.4 (VDD), R5.2, R12.2, U2.14 (VCC), U$9.2_5 (V33), U$13.10 (VCC); also elsewhere on the board
VBATT: JP15.3; also elsewhere on the board
VBUF: JP15.1; also elsewhere on the board
VCC: C16.1, U$12.VIN, USB1.VBUS; also elsewhere on the board
/IRQ: D5.A, D6.A; also elsewhere on the board
/RES: D8.C, IC8.12 (/RES); also elsewhere on the board

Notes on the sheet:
CSA-ULTRACPU-V3.0A
V1.1A: - added USB ESD protection diodes V2.1A: - replaced non-commercial footprint for USB chip - added boot option jumpers on USB GPIN V2.2A: - add CR2032 battery power option
CSA-ULTRACPU-V2.2A-20260602
(C) A. Fachat
Connect Coin Cell on JP2
Watch orientation on board~{}
JP15 to use RTC Power 1-2: from CSA BUS 2-3: from CR2032 open: ext. pwr (JP2)

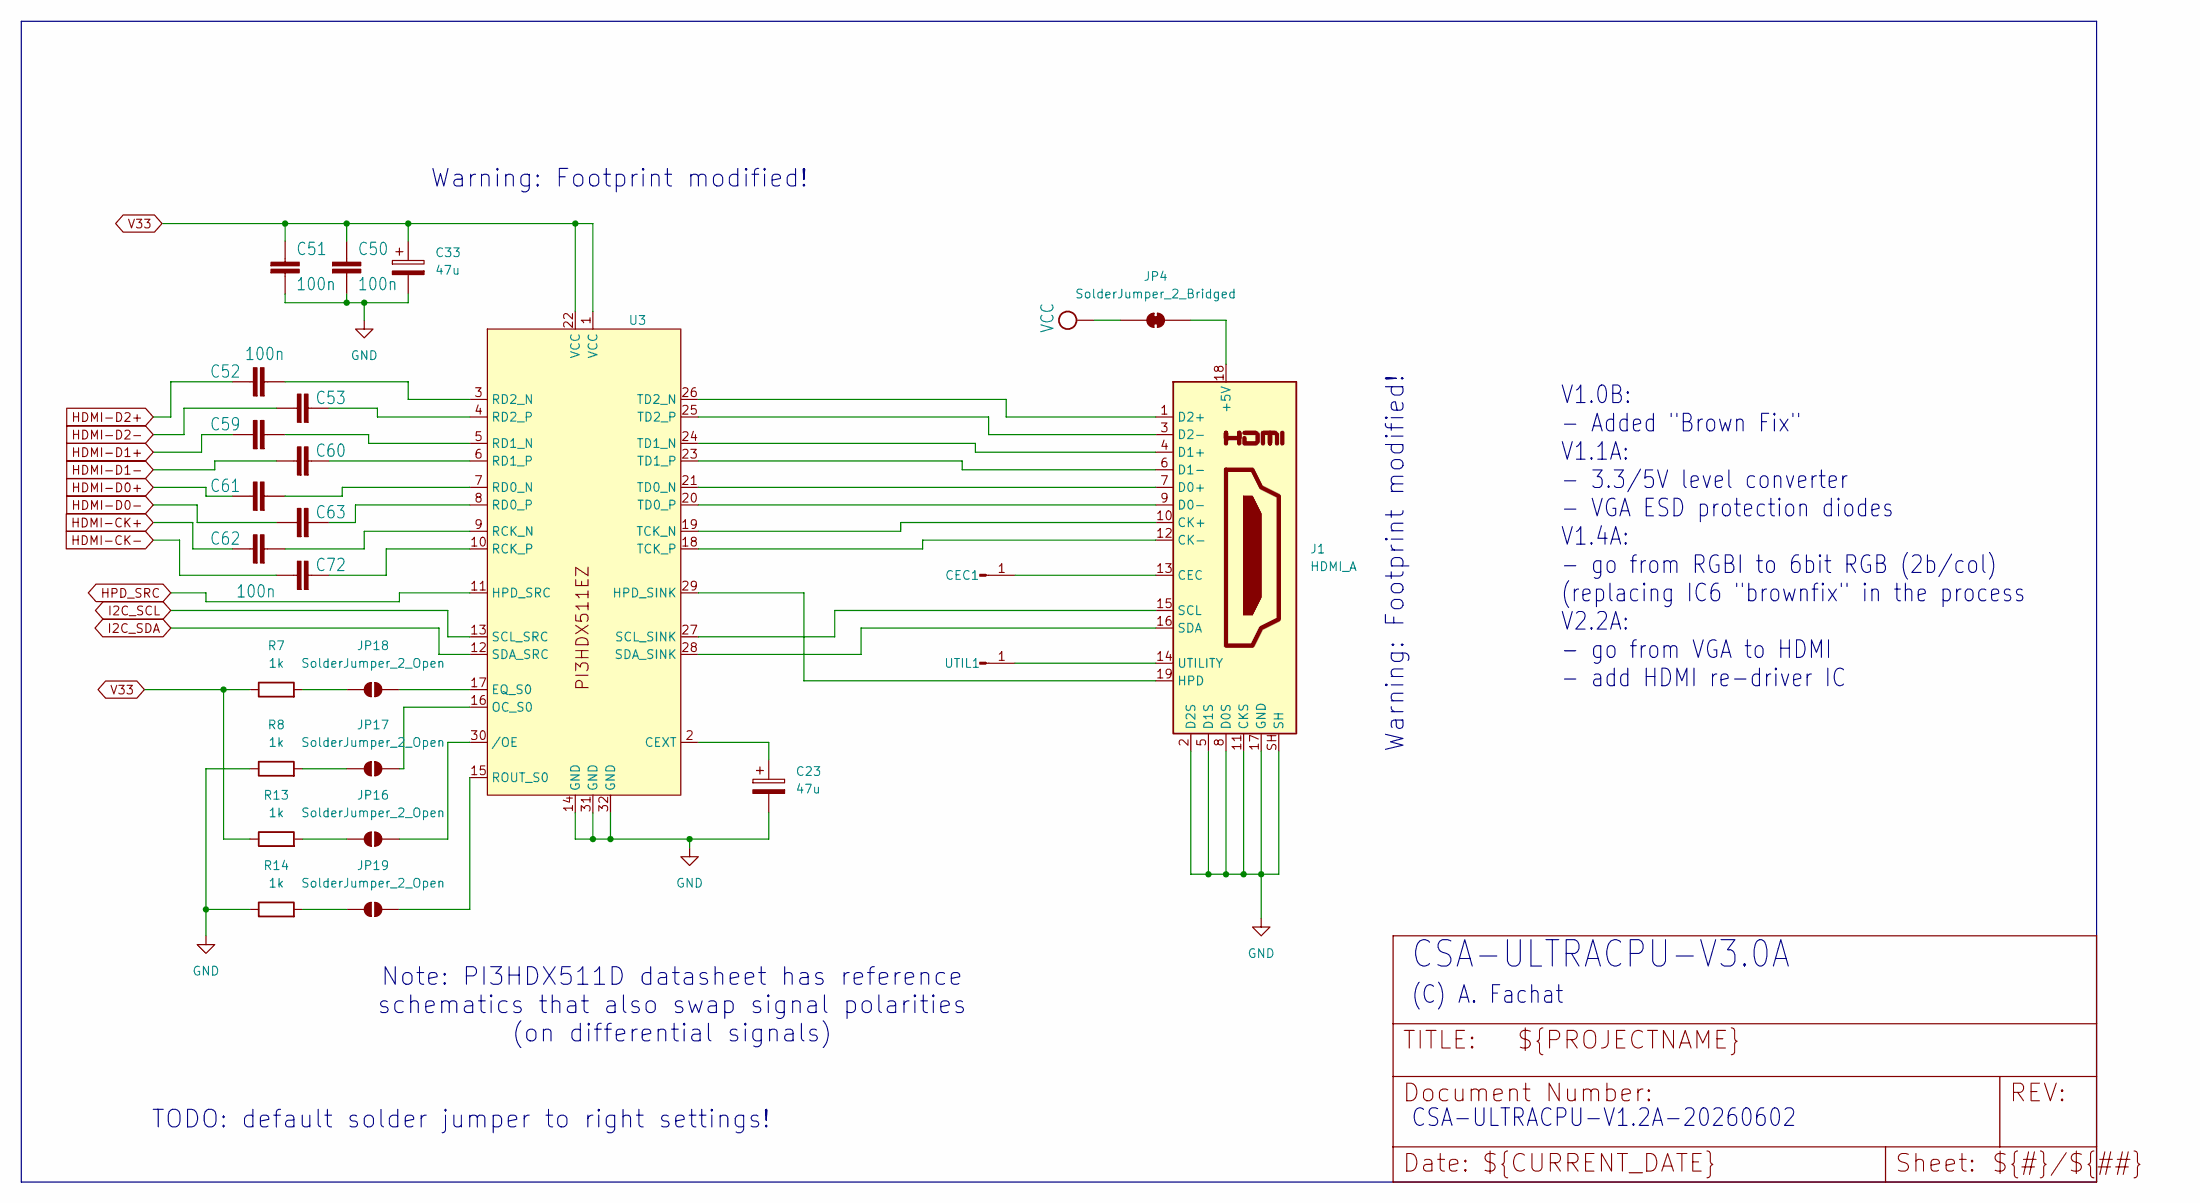
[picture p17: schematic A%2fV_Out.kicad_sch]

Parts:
C23, C33: 47u; C_0805_2012Metric_Pad1.18x1.45mm_HandSolder; LCSC C16780
C50, C51, C52, C53, C59, C60, C61, C62, C63, C72: 100n; C_0603_1608Metric_Pad1.08x0.95mm_HandSolder; LCSC C14663
CEC1: Conn_01x01_Pin; PinHeader_1x01_P1.00mm_Vertical
J1: HDMI_A; HDMI_A_Molex_208658-1001_Horizontal; LCSC C138388
JP4: SolderJumper_2_Bridged; SolderJumper-2_P1.3mm_Bridged_RoundedPad1.0x1.5mm
JP16, JP17, JP18, JP19: SolderJumper_2_Open; SolderJumper-2_P1.3mm_Open_RoundedPad1.0x1.5mm
R7, R8, R13, R14: 1k; R_0603_1608Metric_Pad0.98x0.95mm_HandSolder; LCSC C21190
U3: Diodes_ZL32_TQFN-32-1EP_3x6mm_P0.4mm_EP1.25x3.5mm; LCSC C2674182
UTIL1: Conn_01x01_Pin; PinHeader_1x01_P1.00mm_Vertical

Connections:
GND: C23.2, C33.2, C50.2, C51.2, J1.2 (D2S), J1.5 (D1S), J1.8 (D0S), J1.11 (CKS), J1.17 (GND), J1.SH, R8.1, R14.1, U3.14 (GND), U3.31 (GND), U3.32 (GND); also elsewhere on the board
HDMI-CK+: C62.1; also elsewhere on the board
HDMI-CK-: C72.1; also elsewhere on the board
HDMI-D0+: C61.1; also elsewhere on the board
HDMI-D0-: C63.1; also elsewhere on the board
HDMI-D1+: C59.1; also elsewhere on the board
HDMI-D1-: C60.1; also elsewhere on the board
HDMI-D2+: C52.1; also elsewhere on the board
HDMI-D2-: C53.1; also elsewhere on the board
HPD_SRC: U3.11 (HPD_SRC); also elsewhere on the board
I2C_SCL: U3.13 (SCL_SRC); also elsewhere on the board
I2C_SDA: U3.12 (SDA_SRC); also elsewhere on the board
unnamed: CEC1.1 (Pin_1_1), J1.13 (CEC)
unnamed: J1.18 (+5V), JP4.2 (B)
unnamed: J1.10 (CK+), U3.19 (TCK_N)
unnamed: J1.12 (CK-), U3.18 (TCK_P)
unnamed: J1.7 (D0+), U3.21 (TD0_N)
unnamed: J1.9 (D0-), U3.20 (TD0_P)
unnamed: J1.4 (D1+), U3.24 (TD1_N)
unnamed: J1.6 (D1-), U3.23 (TD1_P)
unnamed: J1.1 (D2+), U3.26 (TD2_N)
unnamed: J1.3 (D2-), U3.25 (TD2_P)
unnamed: J1.19 (HPD), U3.29 (HPD_SINK)
unnamed: J1.15 (SCL), U3.27 (SCL_SINK)
unnamed: J1.16 (SDA), U3.28 (SDA_SINK)
unnamed: J1.14 (UTILITY), UTIL1.1 (Pin_1_1)
unnamed: JP16.1 (A), R13.2
unnamed: JP16.2 (B), U3.30 (/OE)
unnamed: JP17.1 (A), R8.2
unnamed: JP17.2 (B), U3.16 (OC_S0)
unnamed: JP18.1 (A), R7.2
unnamed: JP18.2 (B), U3.17 (EQ_S0)
unnamed: JP19.1 (A), R14.2
unnamed: JP19.2 (B), U3.15 (ROUT_S0)
unnamed: C23.1, U3.2 (CEXT)
unnamed: C62.2, U3.9 (RCK_N)
unnamed: C72.2, U3.10 (RCK_P)
unnamed: C61.2, U3.7 (RD0_N)
unnamed: C63.2, U3.8 (RD0_P)
unnamed: C59.2, U3.5 (RD1_N)
unnamed: C60.2, U3.6 (RD1_P)
unnamed: C52.2, U3.3 (RD2_N)
unnamed: C53.2, U3.4 (RD2_P)
V33: C33.1, C50.1, C51.1, R7.1, R13.1, U3.1 (VCC), U3.22 (VCC); also elsewhere on the board
VCC: JP4.1 (A); also elsewhere on the board

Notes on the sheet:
Warning: Footprint modified!
(C) A. Fachat
CSA-ULTRACPU-V1.2A-20260602
Note: PI3HDX511D datasheet has reference schematics that also swap signal polarities (on differential signals)
V1.0B: - Added "Brown Fix" V1.1A: - 3.3/5V level converter - VGA ESD protection diodes V1.4A: - go from RGBI to 6bit RGB (2b/col) (replacing IC6 "brownfix" in the process V2.2A: - go from VGA to HDMI - add HDMI re-driver IC
CSA-ULTRACPU-V3.0A
TODO: default solder jumper to right settings!

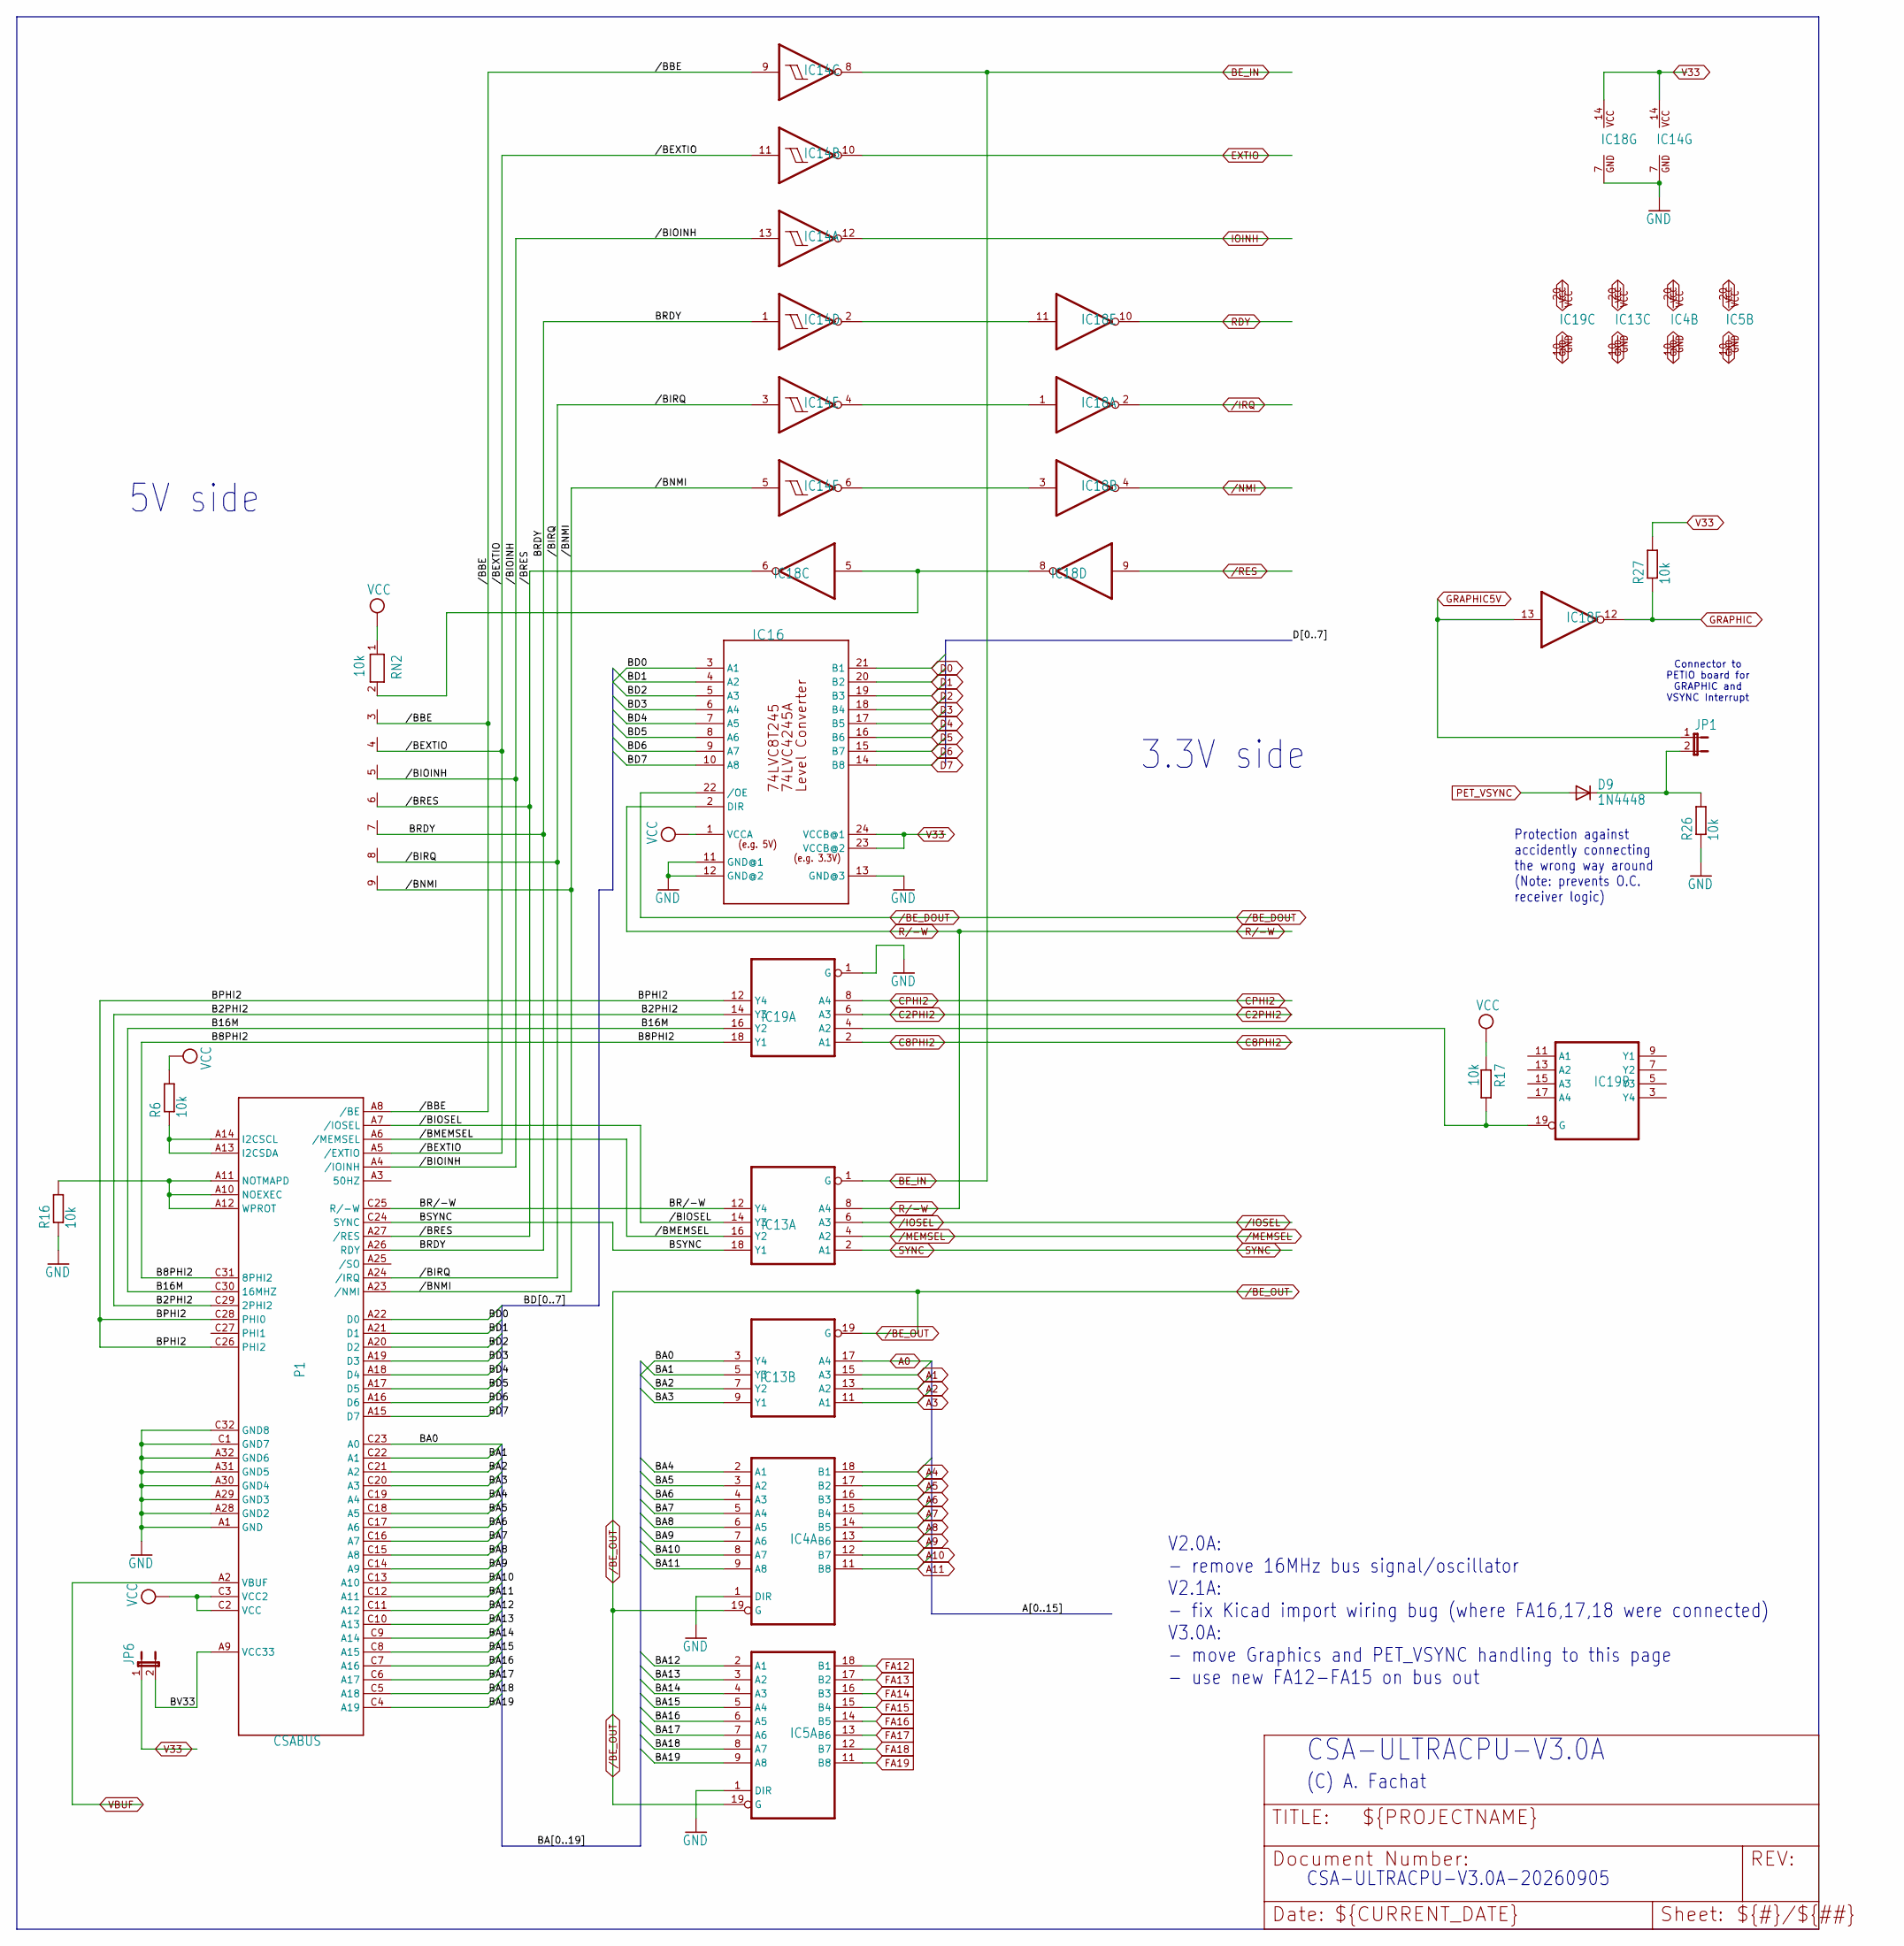
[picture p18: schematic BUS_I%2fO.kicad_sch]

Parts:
D9: 1N4448; D_SOD-123; LCSC C81598
IC4, IC5: 74HCT245DW; SO20W; LCSC C132267
IC13, IC19: 74244DW; SO20W; LCSC C6776
IC14: 74LVC14; SO14; LCSC C133541
IC16: 74LVC8T245SO24; SO24L; LCSC C2677625
IC18: 74LVC06; SO14; LCSC C7658
JP1: JP1E; PinHeader_1x02_P2.54mm_Horizontal; LCSC C54570432
JP6: JP1E; JP1; LCSC C234182
P1: CSABUS; LCSC C5173362
R6, R16, R17, R26, R27: 10k; R_0805_2012Metric_Pad1.20x1.40mm_HandSolder; LCSC C17414
RN2: 10k; RN-9; LCSC C8692

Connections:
/BUS I/O/B2PHI2: IC19.14 (Y3), P1.C29 (2PHI2)
/BUS I/O/B8PHI2: IC19.18 (Y1), P1.C31 (8PHI2)
/BUS I/O/B16M: IC19.16 (Y2), P1.C30 (16MHZ)
/BUS I/O/BA0: IC13.3 (Y4), P1.C23 (A0)
/BUS I/O/BA1: IC13.5 (Y3), P1.C22 (A1)
/BUS I/O/BA2: IC13.7 (Y2), P1.C21 (A2)
/BUS I/O/BA3: IC13.9 (Y1), P1.C20 (A3)
/BUS I/O/BA4: IC4.2 (A1), P1.C19 (A4)
/BUS I/O/BA5: IC4.3 (A2), P1.C18 (A5)
/BUS I/O/BA6: IC4.4 (A3), P1.C17 (A6)
/BUS I/O/BA7: IC4.5 (A4), P1.C16 (A7)
/BUS I/O/BA8: IC4.6 (A5), P1.C15 (A8)
/BUS I/O/BA9: IC4.7 (A6), P1.C14 (A9)
/BUS I/O/BA10: IC4.8 (A7), P1.C13 (A10)
/BUS I/O/BA11: IC4.9 (A8), P1.C12 (A11)
/BUS I/O/BA12: IC5.2 (A1), P1.C11 (A12)
/BUS I/O/BA13: IC5.3 (A2), P1.C10 (A13)
/BUS I/O/BA14: IC5.4 (A3), P1.C9 (A14)
/BUS I/O/BA15: IC5.5 (A4), P1.C8 (A15)
/BUS I/O/BA16: IC5.6 (A5), P1.C7 (A16)
/BUS I/O/BA17: IC5.7 (A6), P1.C6 (A17)
/BUS I/O/BA18: IC5.8 (A7), P1.C5 (A18)
/BUS I/O/BA19: IC5.9 (A8), P1.C4 (A19)
/BUS I/O/BD0: IC16.3 (A1), P1.A22 (D0)
/BUS I/O/BD1: IC16.4 (A2), P1.A21 (D1)
/BUS I/O/BD2: IC16.5 (A3), P1.A20 (D2)
/BUS I/O/BD3: IC16.6 (A4), P1.A19 (D3)
/BUS I/O/BD4: IC16.7 (A5), P1.A18 (D4)
/BUS I/O/BD5: IC16.8 (A6), P1.A17 (D5)
/BUS I/O/BD6: IC16.9 (A7), P1.A16 (D6)
/BUS I/O/BD7: IC16.10 (A8), P1.A15 (D7)
/BUS I/O/BPHI2: IC19.12 (Y4), P1.C26 (PHI2), P1.C28 (PHI0)
/BUS I/O/BRDY: IC14.1 (I), P1.A26 (RDY), RN2.7
/BUS I/O/BR/-W: IC13.12 (Y4), P1.C25 (R/-W)
/BUS I/O/BSYNC: IC13.18 (Y1), P1.C24 (SYNC)
/BUS I/O/BV33: JP6.2, P1.A9 (VCC33)
/BUS I/O//BBE: IC14.9 (I), P1.A8 (/BE), RN2.3
/BUS I/O//BEXTIO: IC14.11 (I), P1.A5 (/EXTIO), RN2.4
/BUS I/O//BIOINH: IC14.13 (I), P1.A4 (/IOINH), RN2.5
/BUS I/O//BIOSEL: IC13.14 (Y3), P1.A7 (/IOSEL)
/BUS I/O//BIRQ: IC14.3 (I), P1.A24 (/IRQ), RN2.8
/BUS I/O//BMEMSEL: IC13.16 (Y2), P1.A6 (/MEMSEL)
/BUS I/O//BNMI: IC14.5 (I), P1.A23 (/NMI), RN2.9
/BUS I/O//BRES: IC18.6 (O), P1.A27 (/RES), RN2.6
A0: IC13.17 (A4); also elsewhere on the board
A1: IC13.15 (A3); also elsewhere on the board
A2: IC13.13 (A2); also elsewhere on the board
A3: IC13.11 (A1); also elsewhere on the board
A4: IC4.18 (B1); also elsewhere on the board
A5: IC4.17 (B2); also elsewhere on the board
A6: IC4.16 (B3); also elsewhere on the board
A7: IC4.15 (B4); also elsewhere on the board
A8: IC4.14 (B5); also elsewhere on the board
A9: IC4.13 (B6); also elsewhere on the board
A10: IC4.12 (B7); also elsewhere on the board
A11: IC4.11 (B8); also elsewhere on the board
BE_IN: IC13.1 (G), IC14.8 (O); also elsewhere on the board
C2PHI2: IC19.6 (A3); also elsewhere on the board
C8PHI2: IC19.2 (A1); also elsewhere on the board
CPHI2: IC19.8 (A4); also elsewhere on the board
D0: IC16.21 (B1); also elsewhere on the board
D1: IC16.20 (B2); also elsewhere on the board
D2: IC16.19 (B3); also elsewhere on the board
D3: IC16.18 (B4); also elsewhere on the board
D4: IC16.17 (B5); also elsewhere on the board
D5: IC16.16 (B6); also elsewhere on the board
D6: IC16.15 (B7); also elsewhere on the board
D7: IC16.14 (B8); also elsewhere on the board
EXTIO: IC14.10 (O); also elsewhere on the board
FA12: IC5.18 (B1); also elsewhere on the board
FA13: IC5.17 (B2); also elsewhere on the board
FA14: IC5.16 (B3); also elsewhere on the board
FA15: IC5.15 (B4); also elsewhere on the board
FA16: IC5.14 (B5); also elsewhere on the board
FA17: IC5.13 (B6); also elsewhere on the board
FA18: IC5.12 (B7); also elsewhere on the board
FA19: IC5.11 (B8); also elsewhere on the board
GND: IC4.1 (DIR), IC4.10 (GND), IC5.1 (DIR), IC5.10 (GND), IC13.10 (GND), IC14.7 (GND), IC16.11 (GND@1), IC16.12 (GND@2), IC16.13 (GND@3), IC18.7 (GND), IC19.1 (G), IC19.10 (GND), P1.A1 (GND), P1.A28 (GND2), P1.A29 (GND3), P1.A30 (GND4), P1.A31 (GND5), P1.A32 (GND6), P1.C1 (GND7), P1.C32 (GND8), R16.1, R26.1; also elsewhere on the board
GRAPHIC: IC18.12 (O), R27.1; also elsewhere on the board
GRAPHIC5V: IC18.13 (I), JP1.1
IOINH: IC14.12 (O); also elsewhere on the board
unnamed: D9.1 (C), JP1.2, R26.2
unnamed: IC14.2 (O), IC18.11 (I)
unnamed: IC14.4 (O), IC18.1 (I)
unnamed: IC14.6 (O), IC18.3 (I)
unnamed: IC18.5 (I), IC18.8 (O), RN2.2
unnamed: IC19.4 (A2), IC19.19 (G), R17.2
unnamed: P1.A13 (I2CSDA), P1.A14 (I2CSCL), R6.1
unnamed: P1.A10 (NOEXEC), P1.A11 (NOTMAPD), P1.A12 (WPROT), R16.2
PET_VSYNC: D9.2 (A); also elsewhere on the board
RDY: IC18.10 (O); also elsewhere on the board
SYNC: IC13.2 (A1); also elsewhere on the board
V33: IC14.14 (VCC), IC16.23 (VCCB@2), IC16.24 (VCCB@1), IC18.14 (VCC), JP6.1, R27.2; also elsewhere on the board
VBUF: P1.A2 (VBUF); also elsewhere on the board
VCC: IC4.20 (VCC), IC5.20 (VCC), IC13.20 (VCC), IC16.1 (VCCA), IC19.20 (VCC), P1.C2 (VCC), P1.C3 (VCC2), R6.2, R17.1, RN2.1; also elsewhere on the board
/BE_DOUT: IC16.22 (/OE); also elsewhere on the board
/BE_OUT: IC4.19 (G), IC5.19 (G), IC13.19 (G); also elsewhere on the board
/IOSEL: IC13.6 (A3); also elsewhere on the board
/IRQ: IC18.2 (O); also elsewhere on the board
/MEMSEL: IC13.4 (A2); also elsewhere on the board
/RES: IC18.9 (I); also elsewhere on the board

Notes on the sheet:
5V side
Connector to PETIO board for GRAPHIC and VSYNC Interrupt
V2.0A: - remove 16MHz bus signal/oscillator V2.1A: - fix Kicad import wiring bug (where FA16,17,18 were connected) V3.0A: - move Graphics and PET_VSYNC handling to this page - use new FA12-FA15 on bus out
CSA-ULTRACPU-V3.0A
(C) A. Fachat
3.3V side
CSA-ULTRACPU-V3.0A-20260905
Protection against accidently connecting the wrong way around (Note: prevents O.C. receiver logic)

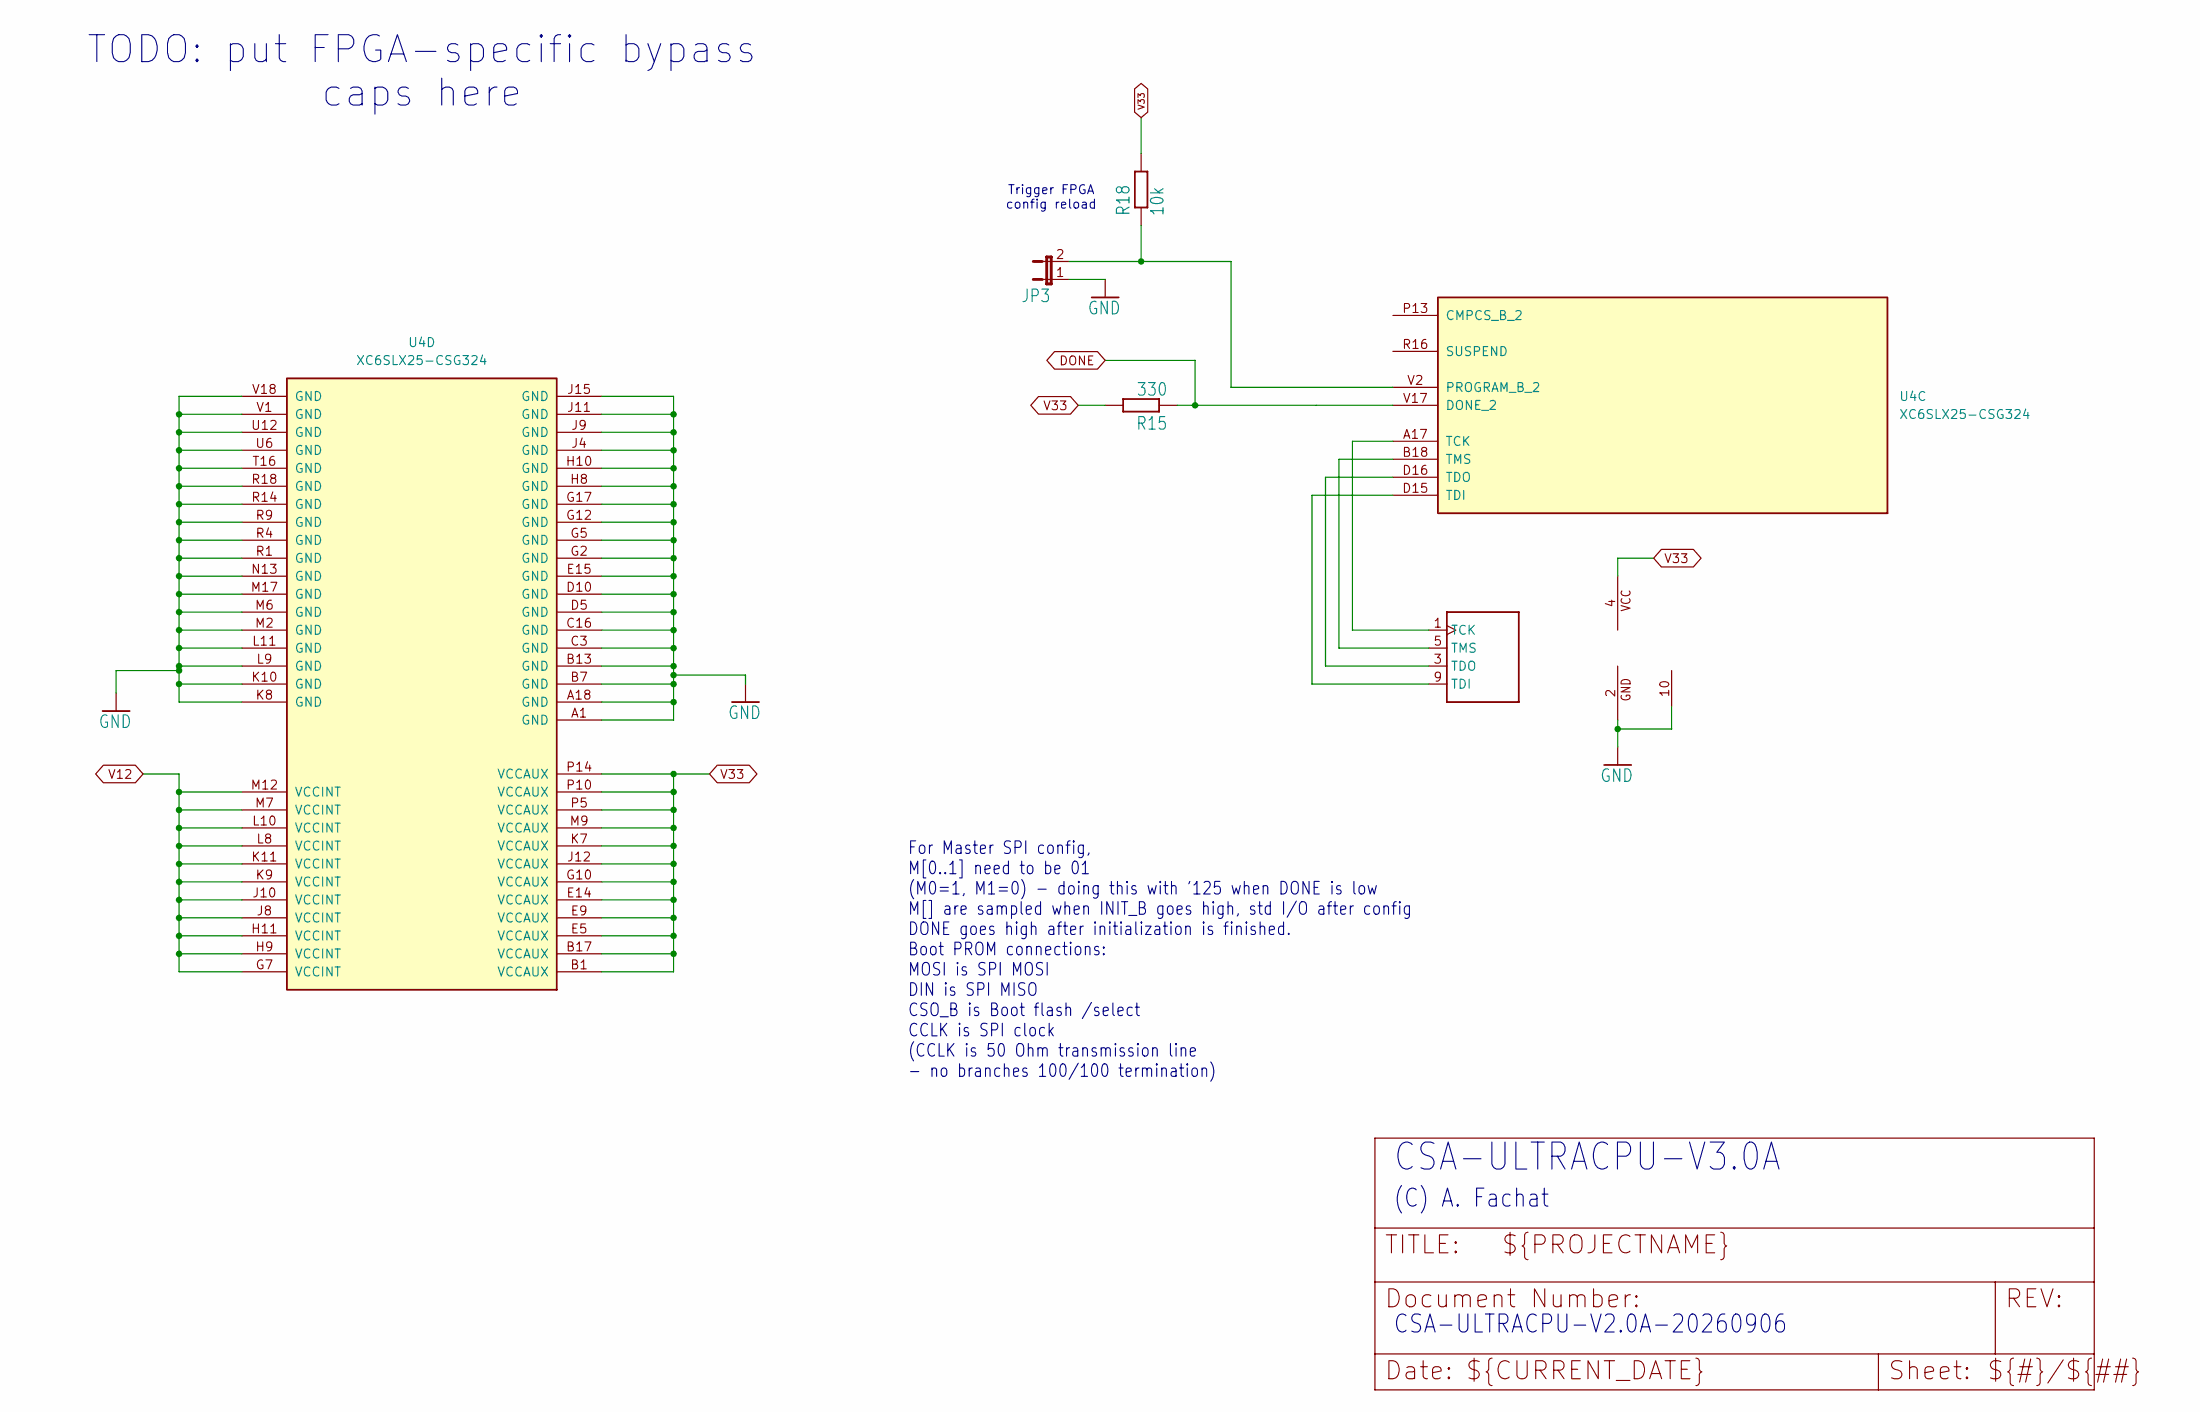
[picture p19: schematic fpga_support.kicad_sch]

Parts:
JP3: JP1E; JP1; LCSC C234182
R15: 330; C_0603_1608Metric_Pad1.08x0.95mm_HandSolder; LCSC C23138
R18: 10k; R_0805_2012Metric_Pad1.20x1.40mm_HandSolder; LCSC C17414
U4: XC6SLX25-CSG324; Xilinx_CSG324; LCSC C169795
U$2: XILINXPROG; FLAT10BOX; LCSC C5665

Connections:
DONE: R15.1, U4.V17 (DONE_2); also elsewhere on the board
GND: JP3.1, U4.A1 (GND), U4.A18 (GND), U4.B7 (GND), U4.B13 (GND), U4.C3 (GND), U4.C16 (GND), U4.D5 (GND), U4.D10 (GND), U4.E15 (GND), U4.G2 (GND), U4.G5 (GND), U4.G12 (GND), U4.G17 (GND), U4.H8 (GND), U4.H10 (GND), U4.J4 (GND), U4.J9 (GND), U4.J11 (GND), U4.J15 (GND), U4.K8 (GND), U4.K10 (GND), U4.L9 (GND), U4.L11 (GND), U4.M2 (GND), U4.M6 (GND), U4.M17 (GND), U4.N13 (GND), U4.R1 (GND), U4.R4 (GND), U4.R9 (GND), U4.R14 (GND), U4.R18 (GND), U4.T16 (GND), U4.U6 (GND), U4.U12 (GND), U4.V1 (GND), U4.V18 (GND), U$2.2 (GND), U$2.10; also elsewhere on the board
unnamed: JP3.2, R18.1, U4.V2 (PROGRAM_B_2)
unnamed: U4.A17 (TCK), U$2.1 (TCK)
unnamed: U4.D15 (TDI), U$2.9 (TDI)
unnamed: U4.D16 (TDO), U$2.3 (TDO)
unnamed: U4.B18 (TMS), U$2.5 (TMS)
V12: U4.G7 (VCCINT), U4.H9 (VCCINT), U4.H11 (VCCINT), U4.J8 (VCCINT), U4.J10 (VCCINT), U4.K9 (VCCINT), U4.K11 (VCCINT), U4.L8 (VCCINT), U4.L10 (VCCINT), U4.M7 (VCCINT), U4.M12 (VCCINT); also elsewhere on the board
V33: R15.2, R18.2, U4.B1 (VCCAUX), U4.B17 (VCCAUX), U4.E5 (VCCAUX), U4.E9 (VCCAUX), U4.E14 (VCCAUX), U4.G10 (VCCAUX), U4.J12 (VCCAUX), U4.K7 (VCCAUX), U4.M9 (VCCAUX), U4.P5 (VCCAUX), U4.P10 (VCCAUX), U4.P14 (VCCAUX), U$2.4 (VCC); also elsewhere on the board

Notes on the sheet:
For Master SPI config, M[0..1] need to be 01 (M0=1, M1=0) - doing this with '125 when DONE is low M[] are sampled when INIT_B goes high, std I/O after config DONE goes high after initialization is finished. Boot PROM connections: MOSI is SPI MOSI DIN is SPI MISO CSO_B is Boot flash /select CCLK is 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
CSA-ULTRACPU-V3.0A
TODO: put FPGA-specific bypass caps here
Trigger FPGA config reload
CSA-ULTRACPU-V2.0A-20260906
(C) A. Fachat

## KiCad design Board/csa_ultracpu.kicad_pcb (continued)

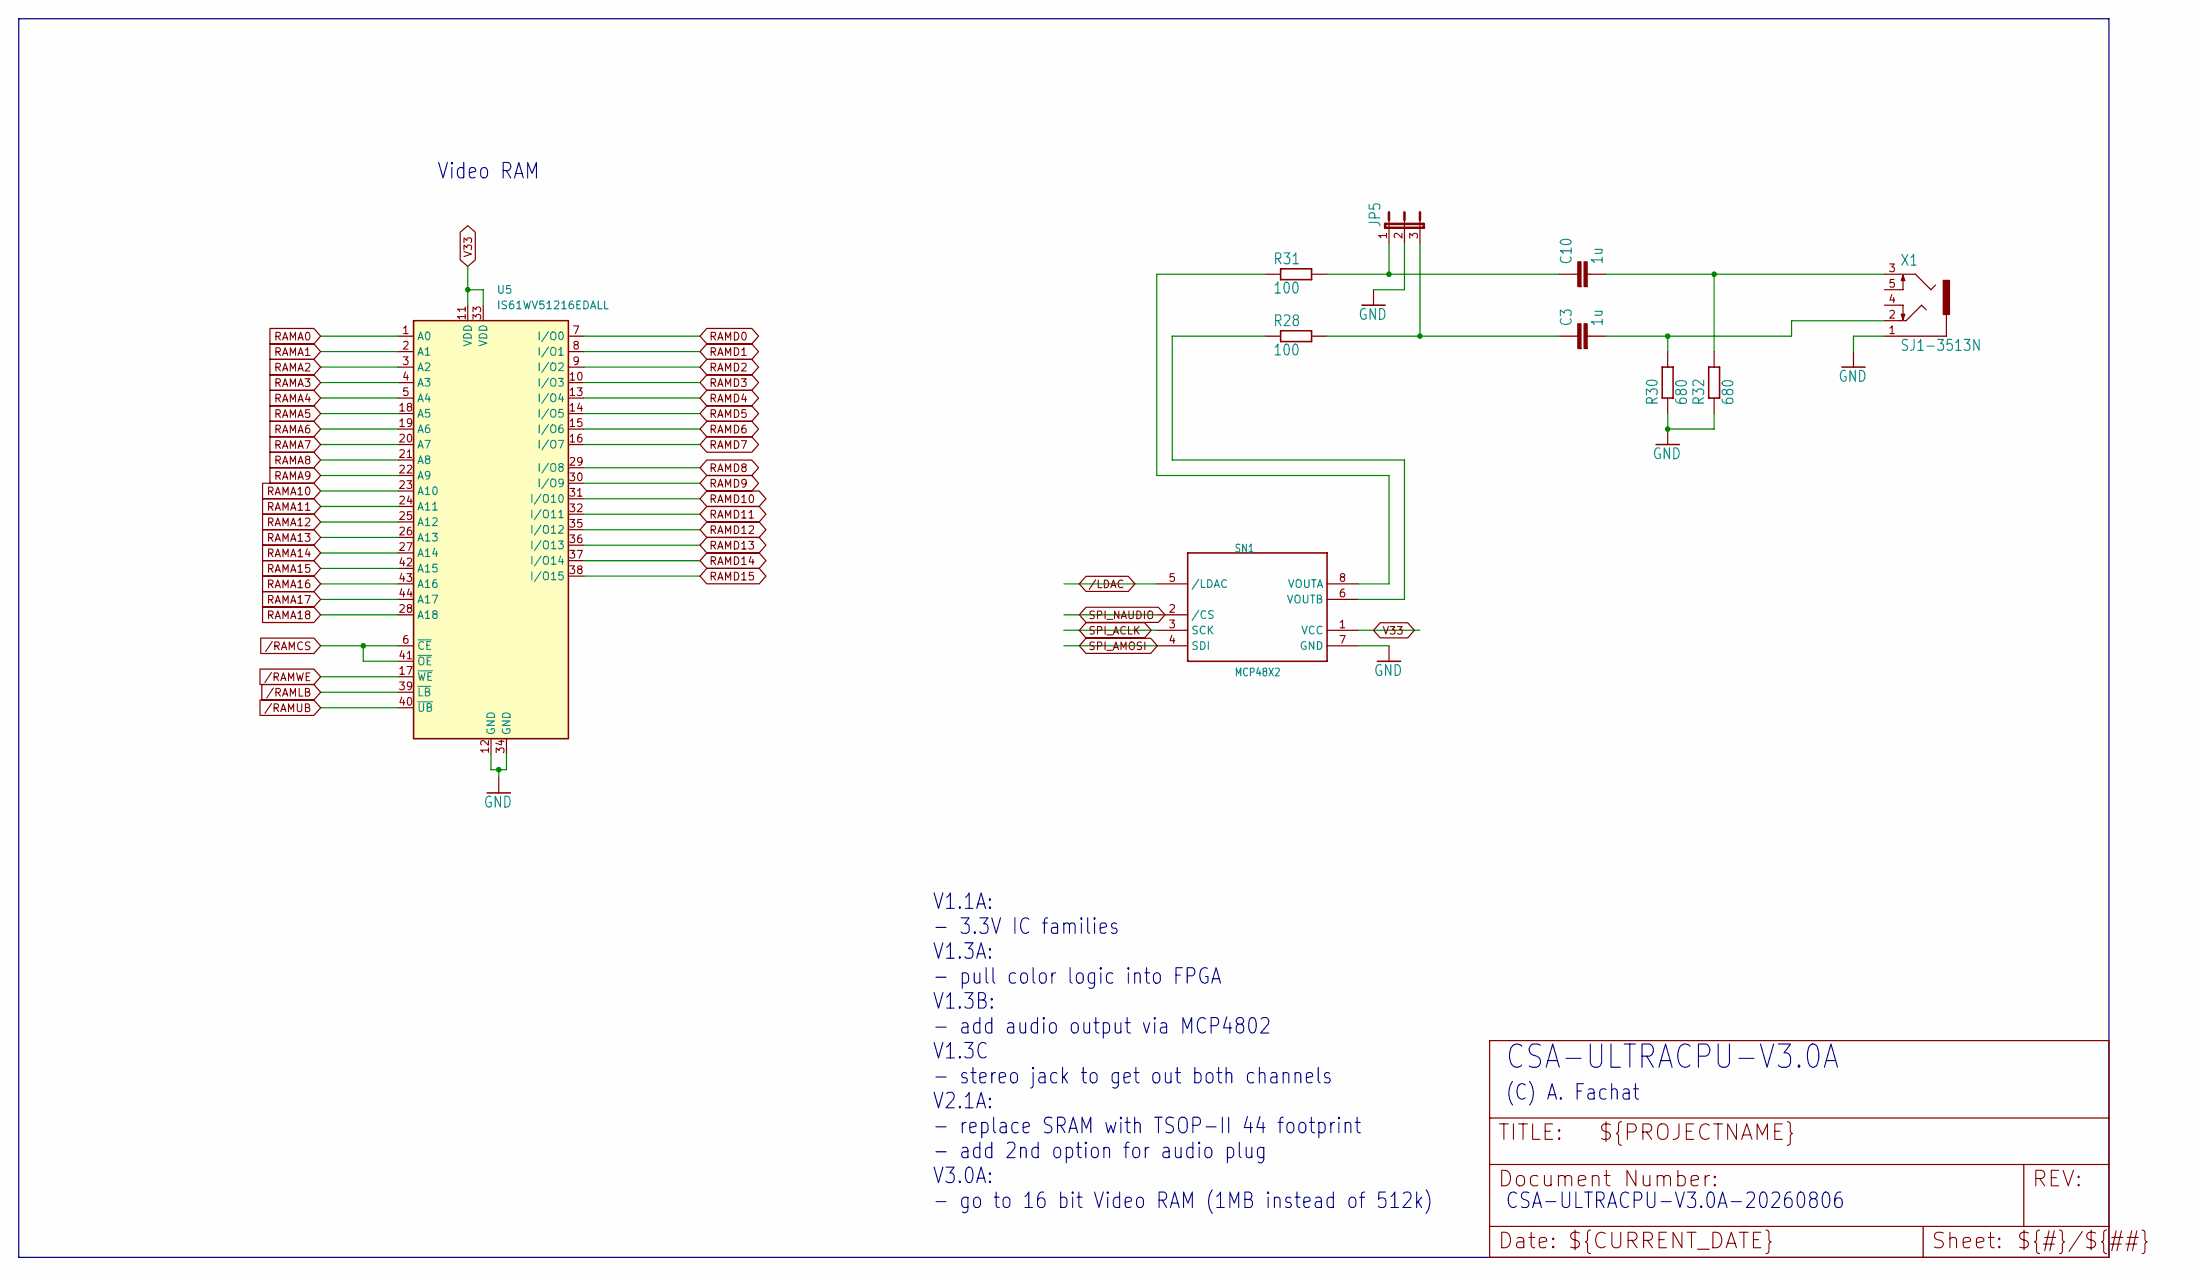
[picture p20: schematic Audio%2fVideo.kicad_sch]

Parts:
C3, C10: 1u; C_0603_1608Metric; LCSC C15849
JP5: JP2E; JP2; LCSC C587036
R28, R31: 100; R_0603_1608Metric_Pad0.98x0.95mm_HandSolder; LCSC C22775
R30, R32: 680; R_0603_1608Metric_Pad0.98x0.95mm_HandSolder; LCSC C23228
SN1: MCP48X2; SOIC8; LCSC C144363
U5: IS61WV51216EDALL; TSOP-II-44_10.16x18.41mm_P0.8mm; LCSC C57407
X1: SJ1-3513N; 1503_09; LCSC C145814

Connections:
GND: JP5.2, R30.1, R32.1, SN1.7 (GND), U5.12 (GND), U5.34 (GND), X1.1; also elsewhere on the board
unnamed: C3.1, JP5.3, R28.2
unnamed: C3.2, R30.2, X1.2
unnamed: C10.1, JP5.1, R31.2
unnamed: C10.2, R32.2, X1.3
unnamed: R31.1, SN1.8 (VOUTA)
unnamed: R28.1, SN1.6 (VOUTB)
RAMA0: U5.1 (A0); also elsewhere on the board
RAMA1: U5.2 (A1); also elsewhere on the board
RAMA2: U5.3 (A2); also elsewhere on the board
RAMA3: U5.4 (A3); also elsewhere on the board
RAMA4: U5.5 (A4); also elsewhere on the board
RAMA5: U5.18 (A5); also elsewhere on the board
RAMA6: U5.19 (A6); also elsewhere on the board
RAMA7: U5.20 (A7); also elsewhere on the board
RAMA8: U5.21 (A8); also elsewhere on the board
RAMA9: U5.22 (A9); also elsewhere on the board
RAMA10: U5.23 (A10); also elsewhere on the board
RAMA11: U5.24 (A11); also elsewhere on the board
RAMA12: U5.25 (A12); also elsewhere on the board
RAMA13: U5.26 (A13); also elsewhere on the board
RAMA14: U5.27 (A14); also elsewhere on the board
RAMA15: U5.42 (A15); also elsewhere on the board
RAMA16: U5.43 (A16); also elsewhere on the board
RAMA17: U5.44 (A17); also elsewhere on the board
RAMA18: U5.28 (A18); also elsewhere on the board
RAMD0: U5.7 (I/O0); also elsewhere on the board
RAMD1: U5.8 (I/O1); also elsewhere on the board
RAMD2: U5.9 (I/O2); also elsewhere on the board
RAMD3: U5.10 (I/O3); also elsewhere on the board
RAMD4: U5.13 (I/O4); also elsewhere on the board
RAMD5: U5.14 (I/O5); also elsewhere on the board
RAMD6: U5.15 (I/O6); also elsewhere on the board
RAMD7: U5.16 (I/O7); also elsewhere on the board
RAMD8: U5.29 (I/O8); also elsewhere on the board
RAMD9: U5.30 (I/O9); also elsewhere on the board
RAMD10: U5.31 (I/O10); also elsewhere on the board
RAMD11: U5.32 (I/O11); also elsewhere on the board
RAMD12: U5.35 (I/O12); also elsewhere on the board
RAMD13: U5.36 (I/O13); also elsewhere on the board
RAMD14: U5.37 (I/O14); also elsewhere on the board
RAMD15: U5.38 (I/O15); also elsewhere on the board
SPI_ACLK: SN1.3 (SCK); also elsewhere on the board
SPI_AMOSI: SN1.4 (SDI); also elsewhere on the board
SPI_NAUDIO: SN1.2 (/CS); also elsewhere on the board
V33: SN1.1 (VCC), U5.11 (VDD), U5.33 (VDD); also elsewhere on the board
/LDAC: SN1.5 (/LDAC); also elsewhere on the board
/RAMLB: U5.39 (~LB); also elsewhere on the board
/RAMUB: U5.40 (~UB); also elsewhere on the board

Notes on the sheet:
(C) A. Fachat
CSA-ULTRACPU-V3.0A-20260806
V1.1A: - 3.3V IC families V1.3A: - pull color logic into FPGA V1.3B: - add audio output via MCP4802 V1.3C - stereo jack to get out both channels V2.1A: - replace SRAM with TSOP-II 44 footprint - add 2nd option for audio plug V3.0A: - go to 16 bit Video RAM (1MB instead of 512k)
Video RAM
CSA-ULTRACPU-V3.0A

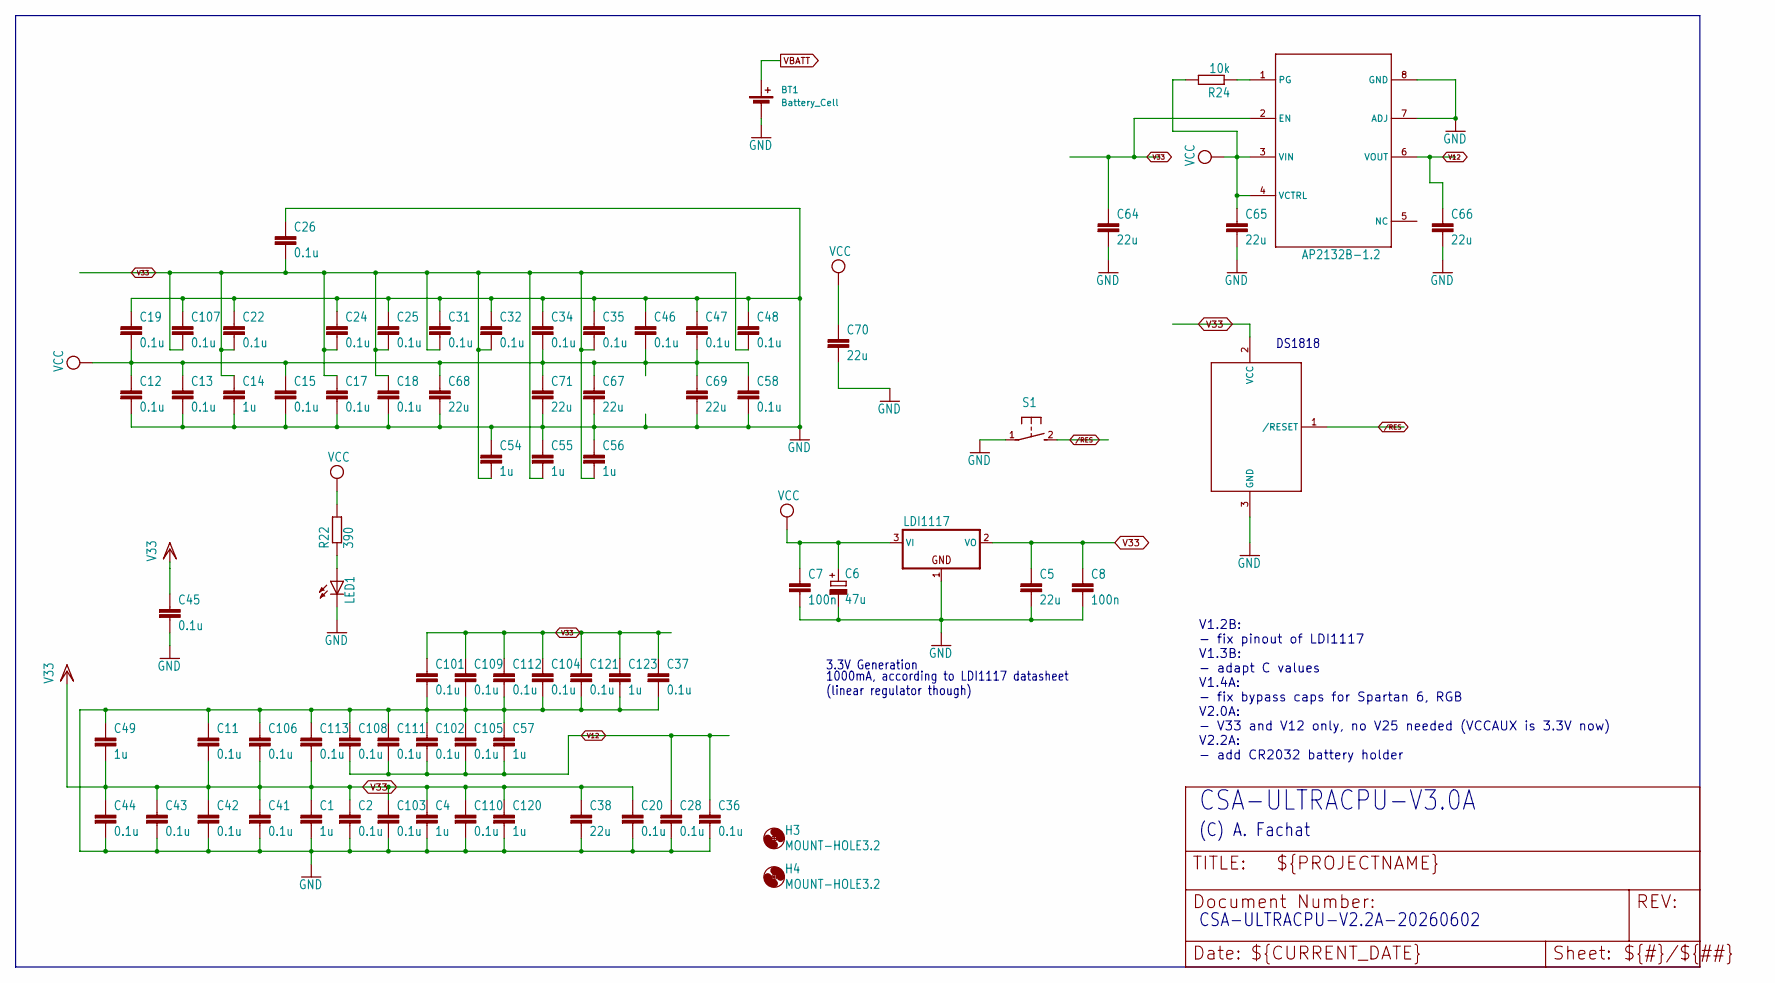
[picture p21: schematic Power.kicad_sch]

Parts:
BT1: Battery_Cell; Kinghelm CR2032 Holder; LCSC C5365915
C1, C4, C14, C49, C54, C55, C56, C57, C120, C123: 1u; C0603; LCSC C15849
C2, C11, C12, C13, C15, C17, C18, C19, C20, C22, C24, C25, C26, C28, C31, C32, C34, C35, C36, C37, C41, C42, C43, C44, C45, C46, C47, C48, C58, C101, C102, C103, C104, C105, C106, C107, C108, C109, C110, C111, C112, C113, C121: 0.1u; C0603; LCSC C14663
C5, C38, C64, C65, C66, C67, C68, C69, C70, C71: 22u; C0805; LCSC C45783
C6: 47u; C_0805_2012Metric_Pad1.18x1.45mm_HandSolder; LCSC C16780
C7, C8: 100n; C0603; LCSC C14663
DS1818: DS1818; SOT-23; LCSC C143298
H3, H4: MOUNT-HOLE3.2; 3,2
LED1: LED3MM; LCSC C85161
R22: 390; R_0603_1608Metric_Pad0.98x0.95mm_HandSolder; LCSC C23151
R24: 10k; R_0805_2012Metric_Pad1.20x1.40mm_HandSolder; LCSC C17414
S1: 31-XX; B3F-31XX; LCSC C231320
U$3: LDI1117; SOT223; LCSC C6186
U$16: AP2132B-1.2; PSOP-8-FIXED; LCSC C338874

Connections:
GND: BT1.2 (-), C1.2, C2.2, C4.2, C5.2, C6.2 (-), C7.2, C8.2, C11.1, C12.2, C13.2, C14.2, C15.2, C17.2, C18.2, C19.1, C20.2, C22.1, C24.1, C25.1, C26.1, C28.2, C31.1, C32.1, C34.1, C35.1, C36.2, C37.2, C38.2, C41.2, C42.2, C43.2, C44.2, C45.2, C46.1, C47.1, C48.1, C49.1, C54.1, C55.1, C56.1, C57.1, C58.2, C64.2, C65.2, C66.2, C67.2, C68.2, C69.2, C70.2, C71.2, C101.2, C102.1, C103.2, C104.2, C105.1, C106.1, C107.1, C108.1, C109.2, C110.2, C111.1, C112.2, C113.1, C120.2, C121.2, C123.2, DS1818.3 (GND), LED1.K (C), S1.1, U$3.1 (GND), U$16.7 (ADJ), U$16.8 (GND); also elsewhere on the board
unnamed: LED1.A, R22.1
unnamed: R24.1, U$16.1 (PG)
V12: C28.1, C36.1, C57.2, C66.1, C102.2, C105.2, C108.2, C111.2, U$16.6 (VOUT); also elsewhere on the board
V33: C1.1, C2.1, C4.1, C5.1, C8.1, C11.2, C14.1, C17.1, C18.1, C20.1, C22.2, C24.2, C25.2, C26.2, C31.2, C32.2, C35.2, C37.1, C38.1, C41.1, C42.1, C43.1, C44.1, C45.1, C48.2, C49.2, C54.2, C55.2, C56.2, C64.1, C101.1, C103.1, C104.1, C106.2, C107.2, C109.1, C110.1, C112.1, C113.2, C120.1, C121.1, C123.1, DS1818.2 (VCC), U$3.2 (VO), U$16.2 (EN); also elsewhere on the board
VBATT: BT1.1 (+); also elsewhere on the board
VCC: C6.1 (+), C7.1, C12.1, C13.1, C15.1, C19.2, C34.2, C46.2, C47.2, C58.1, C65.1, C67.1, C68.1, C69.1, C70.1, C71.1, R22.2, R24.2, U$3.3 (VI), U$16.3 (VIN), U$16.4 (VCTRL); also elsewhere on the board
/RES: DS1818.1 (/RESET), S1.2 (S); also elsewhere on the board

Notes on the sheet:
DS1818
(C) A. Fachat
CSA-ULTRACPU-V3.0A
1000mA, according to LDI1117 datasheet (linear regulator though)
CSA-ULTRACPU-V2.2A-20260602
3.3V Generation
V1.2B: - fix pinout of LDI1117 V1.3B: - adapt C values V1.4A: - fix bypass caps for Spartan 6, RGB V2.0A: - V33 and V12 only, no V25 needed (VCCAUX is 3.3V now) V2.2A: - add CR2032 battery holder

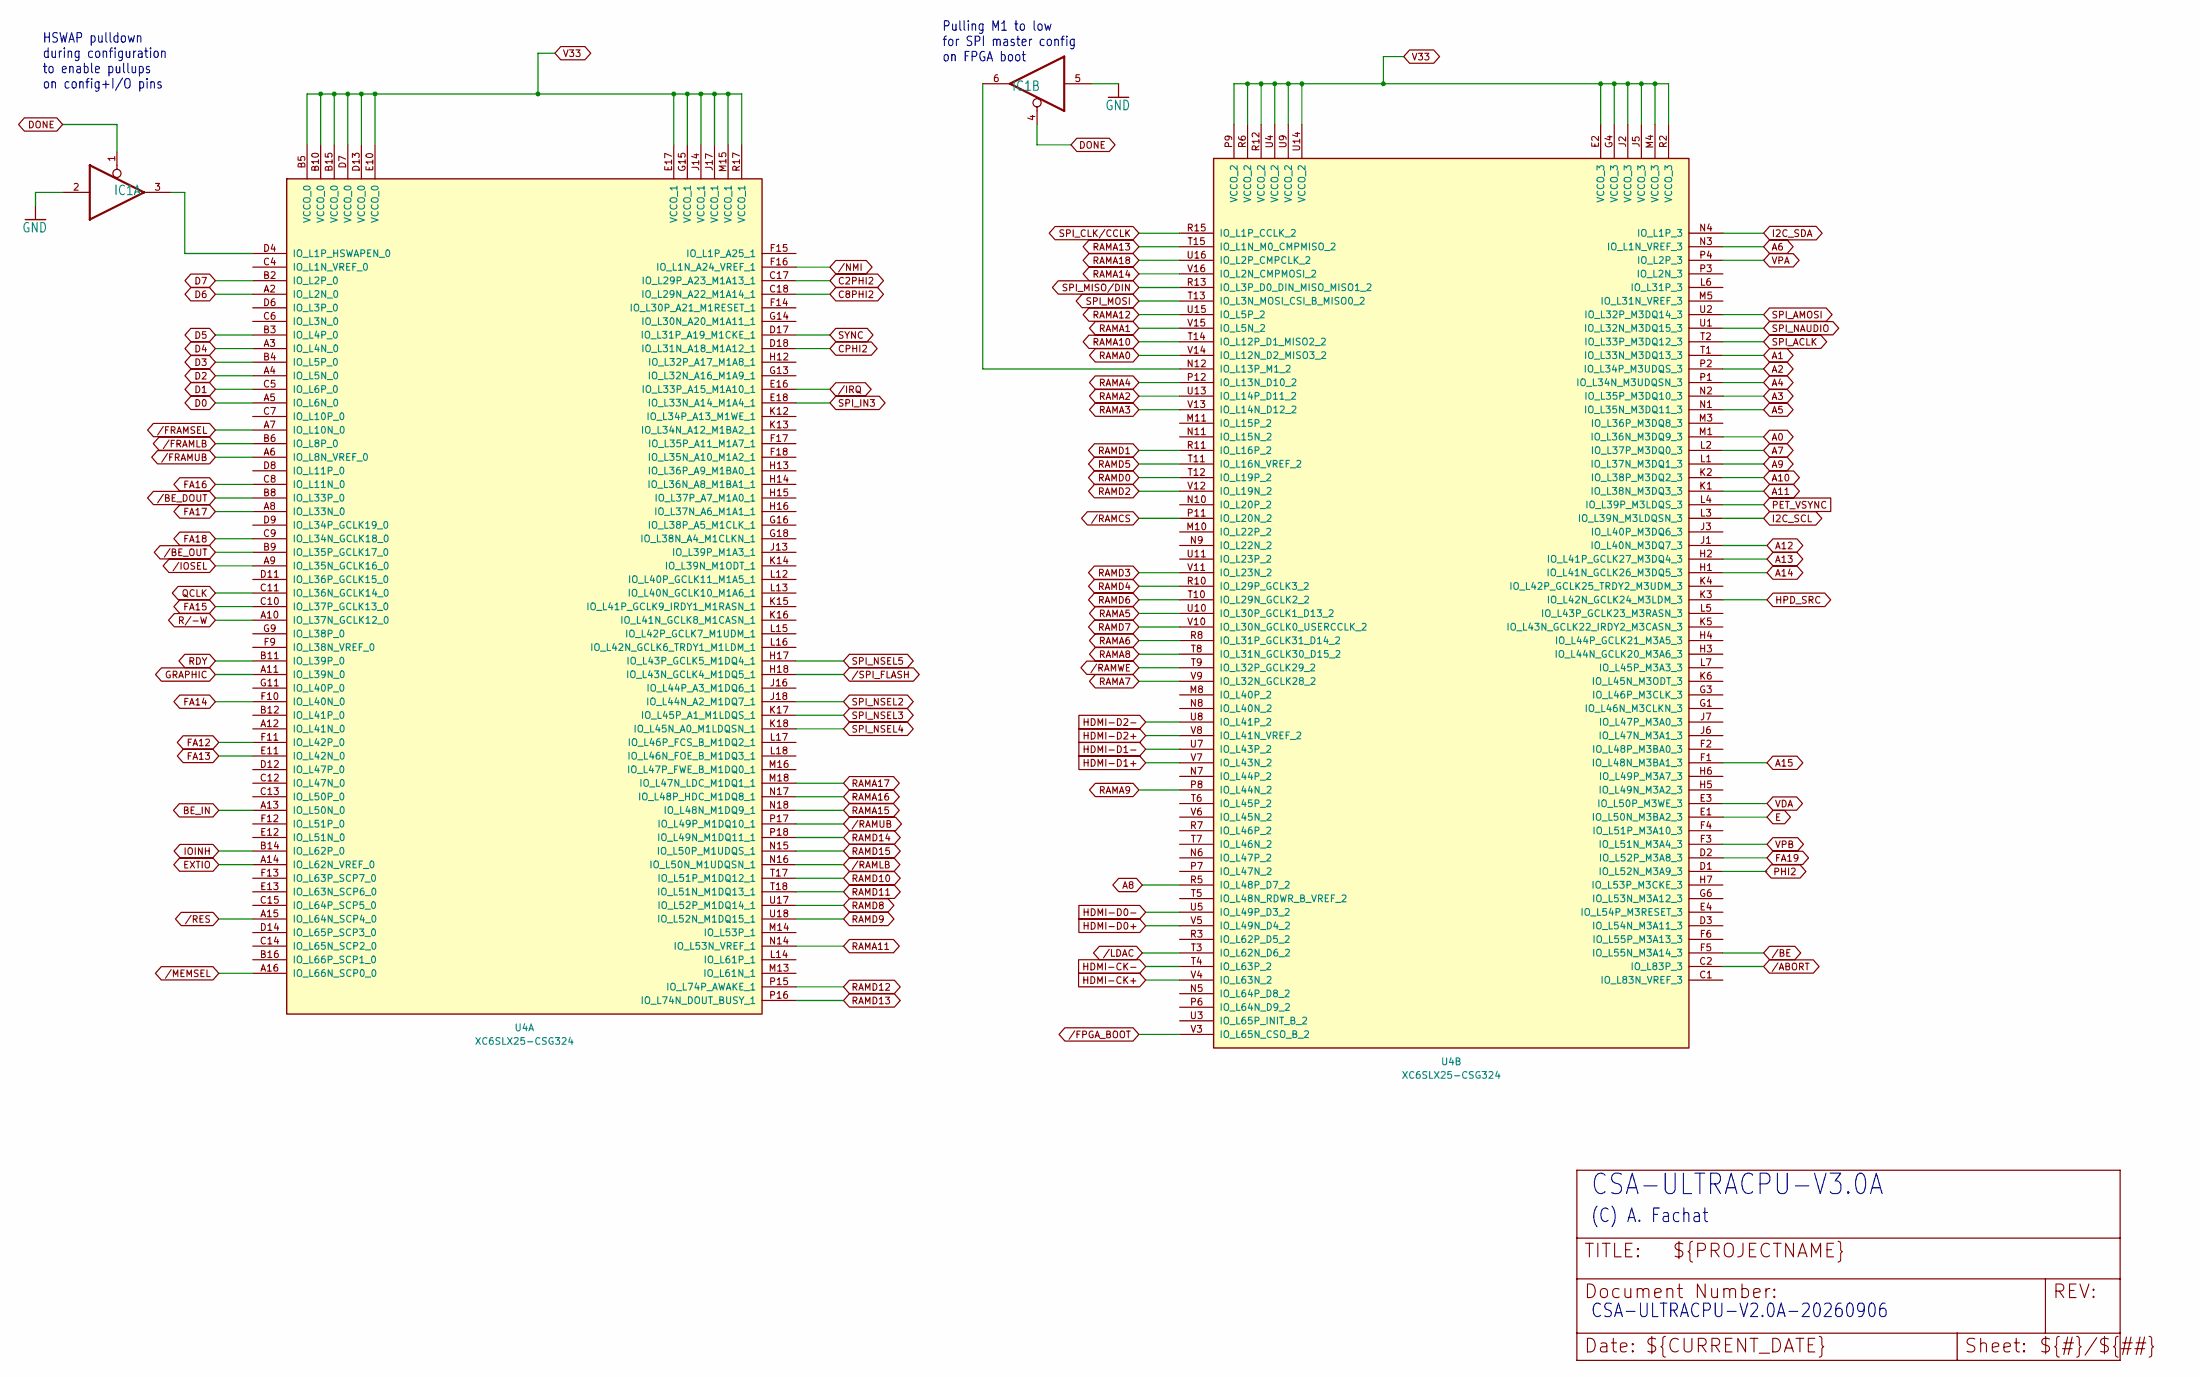
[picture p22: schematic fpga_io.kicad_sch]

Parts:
IC1: 74LVC125; SO14; LCSC C6057
U4: XC6SLX25-CSG324; Xilinx_CSG324; LCSC C169795

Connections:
A0: U4.M1 (IO_L36N_M3DQ9_3); also elsewhere on the board
A1: U4.T1 (IO_L33N_M3DQ13_3); also elsewhere on the board
A2: U4.P2 (IO_L34P_M3UDQS_3); also elsewhere on the board
A3: U4.N2 (IO_L35P_M3DQ10_3); also elsewhere on the board
A4: U4.P1 (IO_L34N_M3UDQSN_3); also elsewhere on the board
A5: U4.N1 (IO_L35N_M3DQ11_3); also elsewhere on the board
A6: U4.N3 (IO_L1N_VREF_3); also elsewhere on the board
A7: U4.L2 (IO_L37P_M3DQ0_3); also elsewhere on the board
A8: U4.R5 (IO_L48P_D7_2); also elsewhere on the board
A9: U4.L1 (IO_L37N_M3DQ1_3); also elsewhere on the board
A10: U4.K2 (IO_L38P_M3DQ2_3); also elsewhere on the board
A11: U4.K1 (IO_L38N_M3DQ3_3); also elsewhere on the board
A12: U4.J1 (IO_L40N_M3DQ7_3); also elsewhere on the board
A13: U4.H2 (IO_L41P_GCLK27_M3DQ4_3); also elsewhere on the board
A14: U4.H1 (IO_L41N_GCLK26_M3DQ5_3); also elsewhere on the board
A15: U4.F1 (IO_L48N_M3BA1_3); also elsewhere on the board
BE_IN: U4.A13 (IO_L50N_0); also elsewhere on the board
C2PHI2: U4.C17 (IO_L29P_A23_M1A13_1); also elsewhere on the board
C8PHI2: U4.C18 (IO_L29N_A22_M1A14_1); also elsewhere on the board
CPHI2: U4.D18 (IO_L31N_A18_M1A12_1); also elsewhere on the board
D0: U4.A5 (IO_L6N_0); also elsewhere on the board
D1: U4.C5 (IO_L6P_0); also elsewhere on the board
D2: U4.A4 (IO_L5N_0); also elsewhere on the board
D3: U4.B4 (IO_L5P_0); also elsewhere on the board
D4: U4.A3 (IO_L4N_0); also elsewhere on the board
D5: U4.B3 (IO_L4P_0); also elsewhere on the board
D6: U4.A2 (IO_L2N_0); also elsewhere on the board
D7: U4.B2 (IO_L2P_0); also elsewhere on the board
DONE: IC1.1 (OE), IC1.4 (OE); also elsewhere on the board
E: U4.E1 (IO_L50N_M3BA2_3); also elsewhere on the board
EXTIO: U4.A14 (IO_L62N_VREF_0); also elsewhere on the board
FA12: U4.F11 (IO_L42P_0); also elsewhere on the board
FA13: U4.E11 (IO_L42N_0); also elsewhere on the board
FA14: U4.F10 (IO_L40N_0); also elsewhere on the board
FA15: U4.C10 (IO_L37P_GCLK13_0); also elsewhere on the board
FA16: U4.C8 (IO_L11N_0); also elsewhere on the board
FA17: U4.A8 (IO_L33N_0); also elsewhere on the board
FA18: U4.C9 (IO_L34N_GCLK18_0); also elsewhere on the board
FA19: U4.D2 (IO_L52P_M3A8_3); also elsewhere on the board
GND: IC1.2 (I), IC1.5 (I); also elsewhere on the board
GRAPHIC: U4.A11 (IO_L39N_0); also elsewhere on the board
HDMI-CK+: U4.V4 (IO_L63N_2); also elsewhere on the board
HDMI-CK-: U4.T4 (IO_L63P_2); also elsewhere on the board
HDMI-D0+: U4.V5 (IO_L49N_D4_2); also elsewhere on the board
HDMI-D0-: U4.U5 (IO_L49P_D3_2); also elsewhere on the board
HDMI-D1+: U4.V7 (IO_L43N_2); also elsewhere on the board
HDMI-D1-: U4.U7 (IO_L43P_2); also elsewhere on the board
HDMI-D2+: U4.V8 (IO_L41N_VREF_2); also elsewhere on the board
HDMI-D2-: U4.U8 (IO_L41P_2); also elsewhere on the board
HPD_SRC: U4.K3 (IO_L42N_GCLK24_M3LDM_3); also elsewhere on the board
I2C_SCL: U4.L3 (IO_L39N_M3LDQSN_3); also elsewhere on the board
I2C_SDA: U4.N4 (IO_L1P_3); also elsewhere on the board
IOINH: U4.B14 (IO_L62P_0); also elsewhere on the board
unnamed: IC1.3 (O), U4.D4 (IO_L1P_HSWAPEN_0)
unnamed: IC1.6 (O), U4.N12 (IO_L13P_M1_2)
PET_VSYNC: U4.L4 (IO_L39P_M3LDQS_3); also elsewhere on the board
PHI2: U4.D1 (IO_L52N_M3A9_3); also elsewhere on the board
QCLK: U4.C11 (IO_L36N_GCLK14_0); also elsewhere on the board
RAMA0: U4.V14 (IO_L12N_D2_MISO3_2); also elsewhere on the board
RAMA1: U4.V15 (IO_L5N_2); also elsewhere on the board
RAMA2: U4.U13 (IO_L14P_D11_2); also elsewhere on the board
RAMA3: U4.V13 (IO_L14N_D12_2); also elsewhere on the board
RAMA4: U4.P12 (IO_L13N_D10_2); also elsewhere on the board
RAMA5: U4.U10 (IO_L30P_GCLK1_D13_2); also elsewhere on the board
RAMA6: U4.R8 (IO_L31P_GCLK31_D14_2); also elsewhere on the board
RAMA7: U4.V9 (IO_L32N_GCLK28_2); also elsewhere on the board
RAMA8: U4.T8 (IO_L31N_GCLK30_D15_2); also elsewhere on the board
RAMA9: U4.P8 (IO_L44N_2); also elsewhere on the board
RAMA10: U4.T14 (IO_L12P_D1_MISO2_2); also elsewhere on the board
RAMA11: U4.N14 (IO_L53N_VREF_1); also elsewhere on the board
RAMA12: U4.U15 (IO_L5P_2); also elsewhere on the board
RAMA13: U4.T15 (IO_L1N_M0_CMPMISO_2); also elsewhere on the board
RAMA14: U4.V16 (IO_L2N_CMPMOSI_2); also elsewhere on the board
RAMA15: U4.N18 (IO_L48N_M1DQ9_1); also elsewhere on the board
RAMA16: U4.N17 (IO_L48P_HDC_M1DQ8_1); also elsewhere on the board
RAMA17: U4.M18 (IO_L47N_LDC_M1DQ1_1); also elsewhere on the board
RAMA18: U4.U16 (IO_L2P_CMPCLK_2); also elsewhere on the board
RAMD0: U4.T12 (IO_L19P_2); also elsewhere on the board
RAMD1: U4.R11 (IO_L16P_2); also elsewhere on the board
RAMD2: U4.V12 (IO_L19N_2); also elsewhere on the board
RAMD3: U4.V11 (IO_L23N_2); also elsewhere on the board
RAMD4: U4.R10 (IO_L29P_GCLK3_2); also elsewhere on the board
RAMD5: U4.T11 (IO_L16N_VREF_2); also elsewhere on the board
RAMD6: U4.T10 (IO_L29N_GCLK2_2); also elsewhere on the board
RAMD7: U4.V10 (IO_L30N_GCLK0_USERCCLK_2); also elsewhere on the board
RAMD8: U4.U17 (IO_L52P_M1DQ14_1); also elsewhere on the board
RAMD9: U4.U18 (IO_L52N_M1DQ15_1); also elsewhere on the board
RAMD10: U4.T17 (IO_L51P_M1DQ12_1); also elsewhere on the board
RAMD11: U4.T18 (IO_L51N_M1DQ13_1); also elsewhere on the board
RAMD12: U4.P15 (IO_L74P_AWAKE_1); also elsewhere on the board
RAMD13: U4.P16 (IO_L74N_DOUT_BUSY_1); also elsewhere on the board
RAMD14: U4.P18 (IO_L49N_M1DQ11_1); also elsewhere on the board
RAMD15: U4.N15 (IO_L50P_M1UDQS_1); also elsewhere on the board
RDY: U4.B11 (IO_L39P_0); also elsewhere on the board
SPI_ACLK: U4.T2 (IO_L33P_M3DQ12_3); also elsewhere on the board
SPI_AMOSI: U4.U2 (IO_L32P_M3DQ14_3); also elsewhere on the board
SPI_CLK/CCLK: U4.R15 (IO_L1P_CCLK_2); also elsewhere on the board
SPI_IN3: U4.E18 (IO_L33N_A14_M1A4_1); also elsewhere on the board
SPI_MISO/DIN: U4.R13 (IO_L3P_D0_DIN_MISO_MISO1_2); also elsewhere on the board
SPI_MOSI: U4.T13 (IO_L3N_MOSI_CSI_B_MISO0_2); also elsewhere on the board
SPI_NAUDIO: U4.U1 (IO_L32N_M3DQ15_3); also elsewhere on the board
SPI_NSEL2: U4.J18 (IO_L44N_A2_M1DQ7_1); also elsewhere on the board
SPI_NSEL3: U4.K17 (IO_L45P_A1_M1LDQS_1); also elsewhere on the board
SPI_NSEL4: U4.K18 (IO_L45N_A0_M1LDQSN_1); also elsewhere on the board
SPI_NSEL5: U4.H17 (IO_L43P_GCLK5_M1DQ4_1); also elsewhere on the board
SYNC: U4.D17 (IO_L31P_A19_M1CKE_1); also elsewhere on the board
V33: U4.B5 (VCCO_0), U4.B10 (VCCO_0), U4.B15 (VCCO_0), U4.D7 (VCCO_0), U4.D13 (VCCO_0), U4.E2 (VCCO_3), U4.E10 (VCCO_0), U4.E17 (VCCO_1), U4.G4 (VCCO_3), U4.G15 (VCCO_1), U4.J2 (VCCO_3), U4.J5 (VCCO_3), U4.J14 (VCCO_1), U4.J17 (VCCO_1), U4.M4 (VCCO_3), U4.M15 (VCCO_1), U4.P9 (VCCO_2), U4.R2 (VCCO_3), U4.R6 (VCCO_2), U4.R12 (VCCO_2), U4.R17 (VCCO_1), U4.U4 (VCCO_2), U4.U9 (VCCO_2), U4.U14 (VCCO_2); also elsewhere on the board
VDA: U4.E3 (IO_L50P_M3WE_3); also elsewhere on the board
VPA: U4.P4 (IO_L2P_3); also elsewhere on the board
VPB: U4.F3 (IO_L51N_M3A4_3); also elsewhere on the board
/ABORT: U4.C2 (IO_L83P_3); also elsewhere on the board
/BE: U4.F5 (IO_L55N_M3A14_3); also elsewhere on the board
/BE_DOUT: U4.B8 (IO_L33P_0); also elsewhere on the board
/BE_OUT: U4.B9 (IO_L35P_GCLK17_0); also elsewhere on the board
/FPGA_BOOT: U4.V3 (IO_L65N_CSO_B_2); also elsewhere on the board
/FRAMLB: U4.B6 (IO_L8P_0); also elsewhere on the board
/FRAMSEL: U4.A7 (IO_L10N_0); also elsewhere on the board
/FRAMUB: U4.A6 (IO_L8N_VREF_0); also elsewhere on the board
/IOSEL: U4.A9 (IO_L35N_GCLK16_0); also elsewhere on the board
/IRQ: U4.E16 (IO_L33P_A15_M1A10_1); also elsewhere on the board
/LDAC: U4.T3 (IO_L62N_D6_2); also elsewhere on the board
/MEMSEL: U4.A16 (IO_L66N_SCP0_0); also elsewhere on the board
/RAMLB: U4.N16 (IO_L50N_M1UDQSN_1); also elsewhere on the board
/RAMUB: U4.P17 (IO_L49P_M1DQ10_1); also elsewhere on the board
/RES: U4.A15 (IO_L64N_SCP4_0); also elsewhere on the board
/SPI_FLASH: U4.H18 (IO_L43N_GCLK4_M1DQ5_1); also elsewhere on the board

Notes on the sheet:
HSWAP pulldown during configuration to enable pullups on config+I/O pins
CSA-ULTRACPU-V2.0A-20260906
Pulling M1 to low for SPI master config on FPGA boot
CSA-ULTRACPU-V3.0A
(C) A. Fachat

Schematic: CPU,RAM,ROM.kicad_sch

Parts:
IC1: 74LVC125; SO14; LCSC C6057
IC6: 741G04DBV; SOT23-5; LCSC C434067
JP7: JP4E; JP4; LCSC C587039
JP8, JP9, JP10, JP11: PIN
R3, R9, R10, R11: 10k; R_0805_2012Metric_Pad1.20x1.40mm_HandSolder; LCSC C17414
U1: IS61WV51216EDALL; TSOP-II-44_10.16x18.41mm_P0.8mm; LCSC C57407
U$1: W65C816SPLCC; PLCC44; LCSC C72279
U$4, U$18: SPIFLASH; DIL08; LCSC C72124
X3: SG-8002CE; Oscillator_SMD_SeikoEpson_SG8002CE-4Pin_3.2x2.5mm; LCSC C2831398

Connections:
/CPU,RAM,ROM/BE: IC6.4 (O), U$1.40 (BE)
/CPU,RAM,ROM/MLB: U$1.6 (MLB)
/CPU,RAM,ROM/M/X: U$1.42 (M/X)
A0: U1.25 (A12), U$1.10 (A0); also elsewhere on the board
A1: U1.26 (A13), U$1.11 (A1); also elsewhere on the board
A2: U1.27 (A14), U$1.13 (A2); also elsewhere on the board
A3: U1.28 (A18), U$1.14 (A3); also elsewhere on the board
A4: U1.5 (A4), U$1.15 (A4); also elsewhere on the board
A5: U1.18 (A5), U$1.16 (A5); also elsewhere on the board
A6: U1.19 (A6), U$1.17 (A6); also elsewhere on the board
A7: U1.20 (A7), U$1.18 (A7); also elsewhere on the board
A8: U1.21 (A8), U$1.19 (A8); also elsewhere on the board
A9: U1.22 (A9), U$1.20 (A9); also elsewhere on the board
A10: U1.23 (A10), U$1.21 (A10); also elsewhere on the board
A11: U1.24 (A11), U$1.22 (A11); also elsewhere on the board
A12: U$1.25 (A12); also elsewhere on the board
A13: U$1.26 (A13); also elsewhere on the board
A14: U$1.27 (A14); also elsewhere on the board
A15: U$1.28 (A15); also elsewhere on the board
D0: U1.7 (I/O0), U1.38 (I/O15), U$1.36 (D0/BA0); also elsewhere on the board
D1: U1.8 (I/O1), U1.37 (I/O14), U$1.35 (D1/BA1); also elsewhere on the board
D2: U1.9 (I/O2), U1.36 (I/O13), U$1.34 (D2/BA2); also elsewhere on the board
D3: U1.10 (I/O3), U1.35 (I/O12), U$1.33 (D3/BA3); also elsewhere on the board
D4: U1.13 (I/O4), U1.32 (I/O11), U$1.32 (D4/BA4); also elsewhere on the board
D5: U1.14 (I/O5), U1.31 (I/O10), U$1.31 (D5/BA5); also elsewhere on the board
D6: U1.15 (I/O6), U1.30 (I/O9), U$1.30 (D6/BA6); also elsewhere on the board
D7: U1.16 (I/O7), U1.29 (I/O8), U$1.29 (D7/BA7); also elsewhere on the board
DONE: IC1.10 (OE); also elsewhere on the board
E: U$1.39 (E); also elsewhere on the board
FA12: U1.1 (A0); also elsewhere on the board
FA13: U1.2 (A1); also elsewhere on the board
FA14: U1.3 (A2); also elsewhere on the board
FA15: U1.4 (A3); also elsewhere on the board
FA16: U1.43 (A16); also elsewhere on the board
FA17: U1.44 (A17); also elsewhere on the board
FA18: U1.42 (A15); also elsewhere on the board
GND: IC1.7 (GND), IC1.9 (I), IC6.3 (GND), JP7.3, U1.12 (GND), U1.34 (GND), U$1.1, U$1.23 (VSS), U$1.24 (GND), U$4.4 (GND), U$18.4 (GND), X3.2 (GND); also elsewhere on the board
unnamed: R3.2, X3.1 (OE)
PHI2: JP9.1 (1_1), U$1.41 (PH2-IN); also elsewhere on the board
QCLK: X3.3 (OUT); also elsewhere on the board
RDY: U$1.3 (RDY); also elsewhere on the board
SPI_CLK/CCLK: U$4.6 (SCK), U$18.6 (SCK); also elsewhere on the board
SPI_MISO/DIN: U$4.2 (SO), U$18.2 (SO); also elsewhere on the board
SPI_MOSI: U$4.5 (SI), U$18.5 (SI); also elsewhere on the board
V33: IC1.14 (VCC), IC6.5 (VCC), R3.1, R9.1, R10.1, R11.1, U1.11 (VDD), U1.33 (VDD), U$1.9 (VCC), U$1.37 (VDD), U$4.7 (/HOLD), U$4.8 (VCC), U$18.7 (/HOLD), U$18.8 (VCC), X3.4 (Vcc); also elsewhere on the board
VDA: U$1.43 (VDA); also elsewhere on the board
VPA: U$1.8 (VPA); also elsewhere on the board
VPB: JP8.1 (1_1), U$1.2 (VPB); also elsewhere on the board
/ABORT: JP7.2, R10.2, U$1.4 (ABORTB); also elsewhere on the board
/BE: IC6.2 (I); also elsewhere on the board
/FPGA_BOOT: U$18.1 (/CS); also elsewhere on the board
/FRAMLB: U1.39 (~LB); also elsewhere on the board
/FRAMSEL: U1.6 (~CE), U1.41 (~OE); also elsewhere on the board
/FRAMUB: U1.40 (~UB); also elsewhere on the board
/IRQ: JP11.1 (1_1), R9.2, U$1.5 (IRQB); also elsewhere on the board
/RES: IC1.8 (O), JP7.1, U$1.44 (RESB); also elsewhere on the board
/SPI_FLASH: JP10.1 (1_1), U$4.1 (/CS); also elsewhere on the board

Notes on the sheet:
PHI2 test point
/NFLASH (boot) test point
Address line ordering to facilitate better PCB routing: FPGA only Ax on "upper" half of chip.
CSA-ULTRACPU-V3.0A-20260905
CSA-UTRACPU-V3.0A
Fast RAM
V2.0A: - use CCLK for all SPI clocks - add switchable CPU BE input - VCCAUX is 3.3V now - Added test points V2.0B: - IC6 power supply to 3.3V instead of 5V - Pulldown /RES as long as DONE is low V2.1A: - use TSOP-II 44 pin package for SRAM - use 3225 package for 54MHz SMD oscillator V3.0A: - go fro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
VPB test point
(C) A. Fachat

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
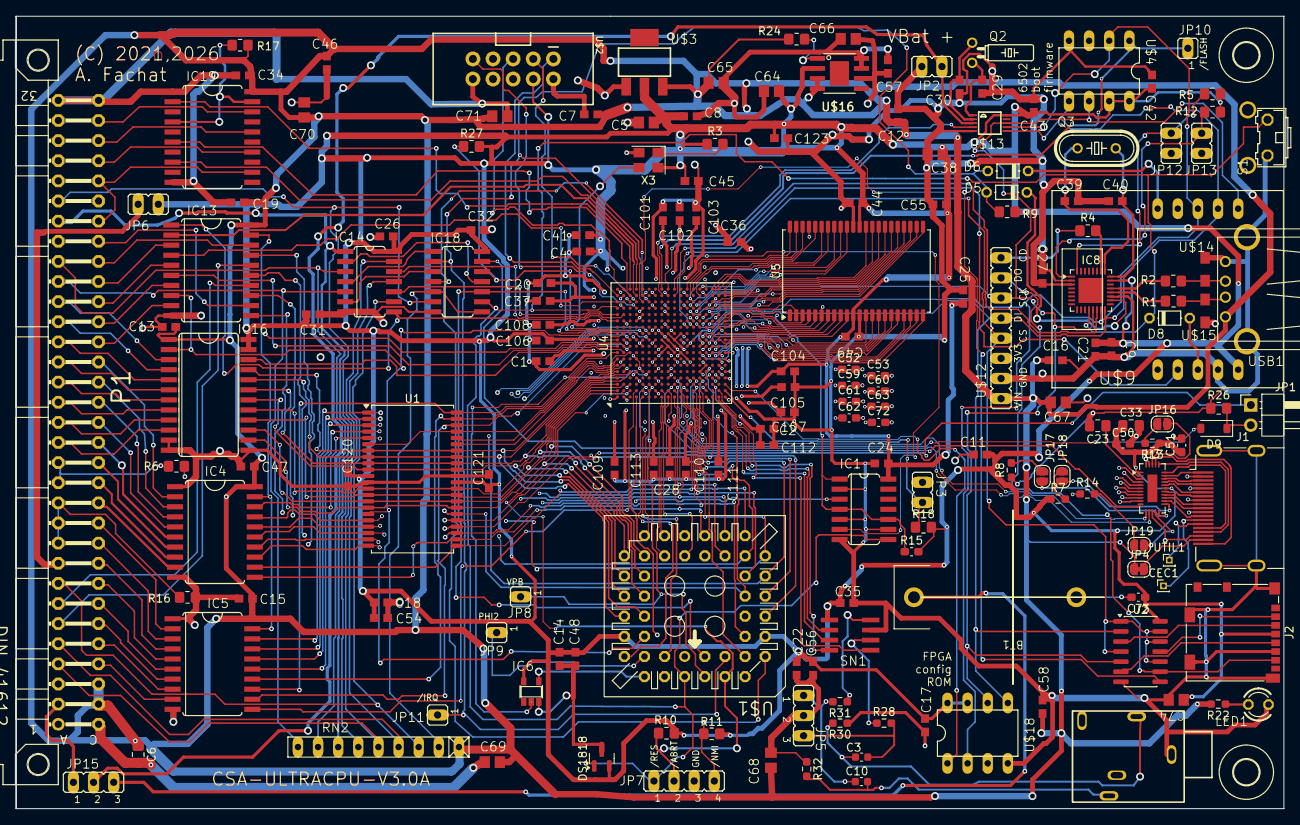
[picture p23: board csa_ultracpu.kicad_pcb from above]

Board: 4 copper layers, 160.0 x 100.0 mm, 182 parts (0 on the bottom side), 253 nets.

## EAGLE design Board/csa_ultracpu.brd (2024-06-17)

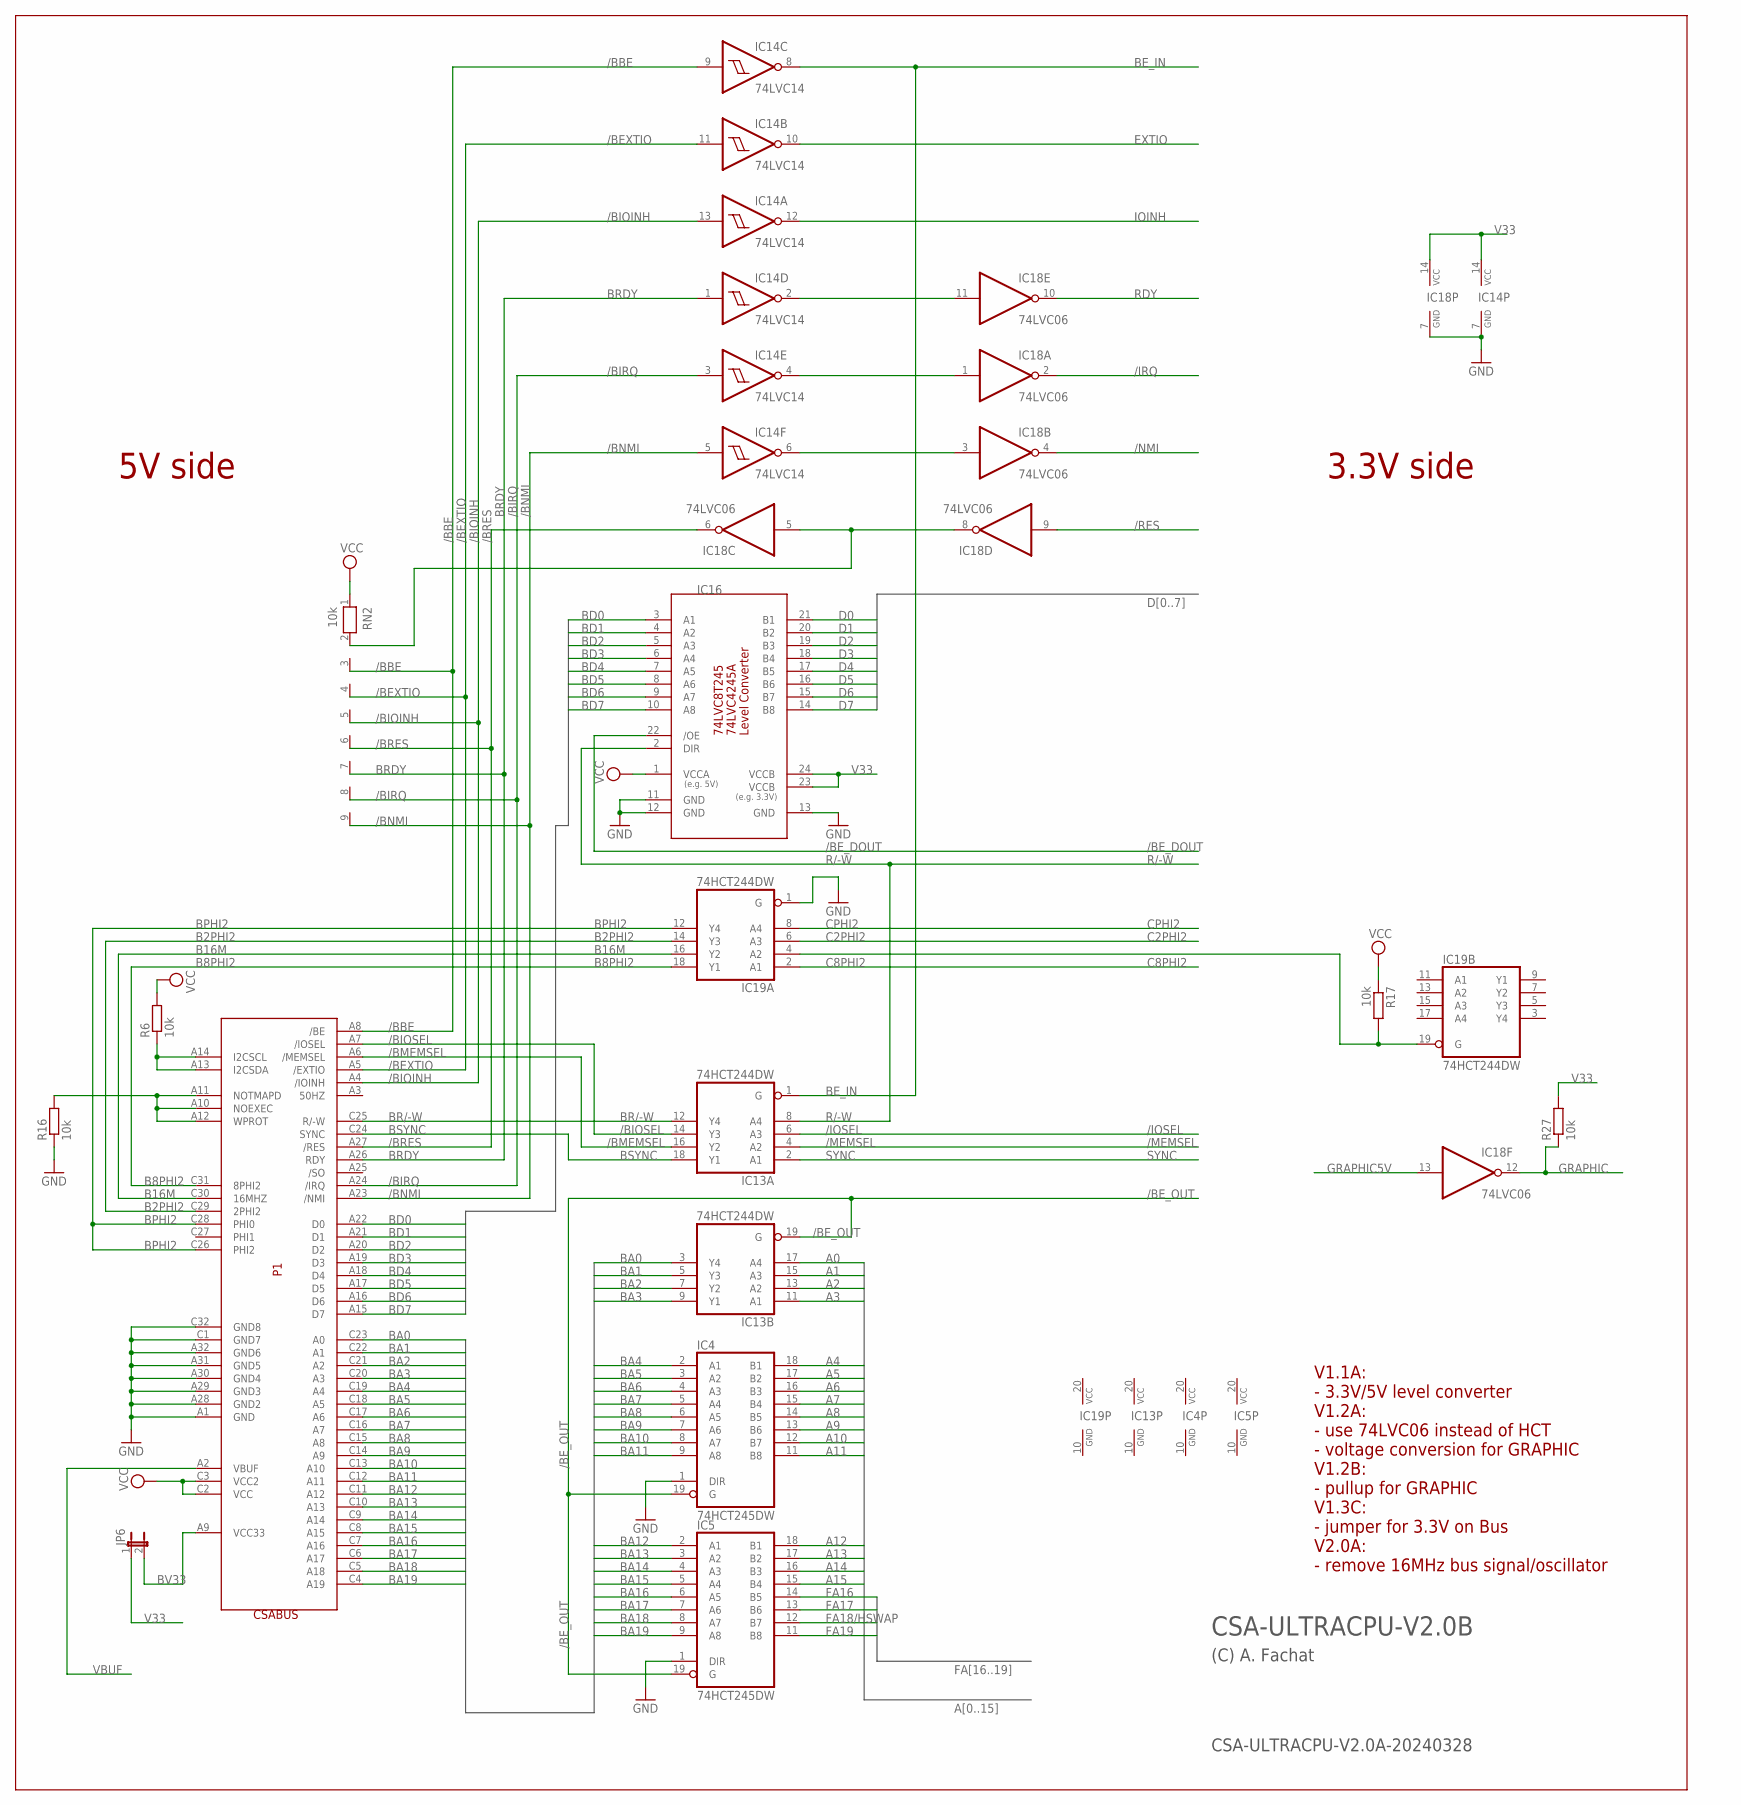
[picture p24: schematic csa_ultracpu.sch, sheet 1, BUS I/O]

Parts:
IC4, IC5: 74HCT245DW; SO20W
IC13, IC19: 74HCT244DW; SO20W
IC14: 74LVC14; SO14
IC16: 74LVC8T245SO24; SO24L
IC18: 74LVC06; SO14
JP6: JP1E; JP1
P1: CSABUS
R6, R16, R17, R27: 10k; 0204/5
RN2: 10k; RN-9

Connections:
/BBE: IC14.9 (I), P1.A8 (/BE), RN2.3
/BEXTIO: IC14.11 (I), P1.A5 (/EXTIO), RN2.4
/BE_DOUT: IC16.22 (/OE); also elsewhere on the board
/BE_OUT: IC4.19 (G), IC5.19 (G), IC13.19 (G); also elsewhere on the board
/BIOINH: IC14.13 (I), P1.A4 (/IOINH), RN2.5
/BIOSEL: IC13.14 (Y3), P1.A7 (/IOSEL)
/BIRQ: IC14.3 (I), P1.A24 (/IRQ), RN2.8
/BMEMSEL: IC13.16 (Y2), P1.A6 (/MEMSEL)
/BNMI: IC14.5 (I), P1.A23 (/NMI), RN2.9
/BRES: IC18.6 (O), P1.A27 (/RES), RN2.6
/IOSEL: IC13.6 (A3); also elsewhere on the board
/IRQ: IC18.2 (O); also elsewhere on the board
/MEMSEL: IC13.4 (A2); also elsewhere on the board
/NMI: IC18.4 (O); also elsewhere on the board
/RES: IC18.9 (I); also elsewhere on the board
A0: IC13.17 (A4); also elsewhere on the board
A1: IC13.15 (A3); also elsewhere on the board
A2: IC13.13 (A2); also elsewhere on the board
A3: IC13.11 (A1); also elsewhere on the board
A4: IC4.18 (B1); also elsewhere on the board
A5: IC4.17 (B2); also elsewhere on the board
A6: IC4.16 (B3); also elsewhere on the board
A7: IC4.15 (B4); also elsewhere on the board
A8: IC4.14 (B5); also elsewhere on the board
A9: IC4.13 (B6); also elsewhere on the board
A10: IC4.12 (B7); also elsewhere on the board
A11: IC4.11 (B8); also elsewhere on the board
A12: IC5.18 (B1); also elsewhere on the board
A13: IC5.17 (B2); also elsewhere on the board
A14: IC5.16 (B3); also elsewhere on the board
A15: IC5.15 (B4); also elsewhere on the board
B2PHI2: IC19.14 (Y3), P1.C29 (2PHI2)
B8PHI2: IC19.18 (Y1), P1.C31 (8PHI2)
B16M: IC19.16 (Y2), P1.C30 (16MHZ)
BA0: IC13.3 (Y4), P1.C23 (A0)
BA1: IC13.5 (Y3), P1.C22 (A1)
BA2: IC13.7 (Y2), P1.C21 (A2)
BA3: IC13.9 (Y1), P1.C20 (A3)
BA4: IC4.2 (A1), P1.C19 (A4)
BA5: IC4.3 (A2), P1.C18 (A5)
BA6: IC4.4 (A3), P1.C17 (A6)
BA7: IC4.5 (A4), P1.C16 (A7)
BA8: IC4.6 (A5), P1.C15 (A8)
BA9: IC4.7 (A6), P1.C14 (A9)
BA10: IC4.8 (A7), P1.C13 (A10)
BA11: IC4.9 (A8), P1.C12 (A11)
BA12: IC5.2 (A1), P1.C11 (A12)
BA13: IC5.3 (A2), P1.C10 (A13)
BA14: IC5.4 (A3), P1.C9 (A14)
BA15: IC5.5 (A4), P1.C8 (A15)
BA16: IC5.6 (A5), P1.C7 (A16)
BA17: IC5.7 (A6), P1.C6 (A17)
BA18: IC5.8 (A7), P1.C5 (A18)
BA19: IC5.9 (A8), P1.C4 (A19)
BD0: IC16.3 (A1), P1.A22 (D0)
BD1: IC16.4 (A2), P1.A21 (D1)
BD2: IC16.5 (A3), P1.A20 (D2)
BD3: IC16.6 (A4), P1.A19 (D3)
BD4: IC16.7 (A5), P1.A18 (D4)
BD5: IC16.8 (A6), P1.A17 (D5)
BD6: IC16.9 (A7), P1.A16 (D6)
BD7: IC16.10 (A8), P1.A15 (D7)
BE_IN: IC13.1 (G), IC14.8 (O); also elsewhere on the board
BPHI2: IC19.12 (Y4), P1.C26 (PHI2), P1.C28 (PHI0)
BR/-W: IC13.12 (Y4), P1.C25 (R/-W)
BRDY: IC14.1 (I), P1.A26 (RDY), RN2.7
BSYNC: IC13.18 (Y1), P1.C24 (SYNC)
BV33: JP6.2, P1.A9 (VCC33)
C2PHI2: IC19.6 (A3); also elsewhere on the board
C8PHI2: IC19.2 (A1); also elsewhere on the board
CPHI2: IC19.8 (A4); also elsewhere on the board
D0: IC16.21 (B1); also elsewhere on the board
D1: IC16.20 (B2); also elsewhere on the board
D2: IC16.19 (B3); also elsewhere on the board
D3: IC16.18 (B4); also elsewhere on the board
D4: IC16.17 (B5); also elsewhere on the board
D5: IC16.16 (B6); also elsewhere on the board
D6: IC16.15 (B7); also elsewhere on the board
D7: IC16.14 (B8); also elsewhere on the board
EXTIO: IC14.10 (O); also elsewhere on the board
FA16: IC5.14 (B5); also elsewhere on the board
FA17: IC5.13 (B6); also elsewhere on the board
FA18/HSWAP: IC5.12 (B7); also elsewhere on the board
FA19: IC5.11 (B8); also elsewhere on the board
GND: IC4.1 (DIR), IC4.10 (GND), IC5.1 (DIR), IC5.10 (GND), IC13.10 (GND), IC14.7 (GND), IC16.11 (GND), IC16.12 (GND), IC16.13 (GND), IC18.7 (GND), IC19.1 (G), IC19.10 (GND), P1.A1 (GND), P1.A28 (GND2), P1.A29 (GND3), P1.A30 (GND4), P1.A31 (GND5), P1.A32 (GND6), P1.C1 (GND7), P1.C32 (GND8), R16.1; also elsewhere on the board
GRAPHIC: IC18.12 (O), R27.1; also elsewhere on the board
GRAPHIC5V: IC18.13 (I); also elsewhere on the board
IOINH: IC14.12 (O); also elsewhere on the board
unnamed: IC14.4 (O), IC18.1 (I)
unnamed: IC14.6 (O), IC18.3 (I)
unnamed: IC18.5 (I), IC18.8 (O), RN2.2
unnamed: IC14.2 (O), IC18.11 (I)
unnamed: IC19.4 (A2), IC19.19 (G), R17.2
unnamed: P1.A10 (NOEXEC), P1.A11 (NOTMAPD), P1.A12 (WPROT), R16.2
unnamed: P1.A13 (I2CSDA), P1.A14 (I2CSCL), R6.1
R/-W: IC13.8 (A4), IC16.2 (DIR); also elsewhere on the board
RDY: IC18.10 (O); also elsewhere on the board
SYNC: IC13.2 (A1); also elsewhere on the board
V33: IC14.14 (VCC), IC16.23 (VCCB), IC16.24 (VCCB), IC18.14 (VCC), JP6.1, R27.2; also elsewhere on the board
VBUF: P1.A2 (VBUF); also elsewhere on the board
VCC: IC4.20 (VCC), IC5.20 (VCC), IC13.20 (VCC), IC16.1 (VCCA), IC19.20 (VCC), P1.C2 (VCC), P1.C3 (VCC2), R6.2, R17.1, RN2.1; also elsewhere on the board

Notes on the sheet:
CSA-ULTRACPU-V2.0A-20240328
CSA-ULTRACPU-V2.0B
(C) A. Fachat
3.3V side
5V side
V1.1A: - 3.3V/5V level converter V1.2A: - use 74LVC06 instead of HCT - voltage conversion for GRAPHIC V1.2B: - pullup for GRAPHIC V1.3C: - jumper for 3.3V on Bus V2.0A: - remove 16MHz bus signal/oscillator

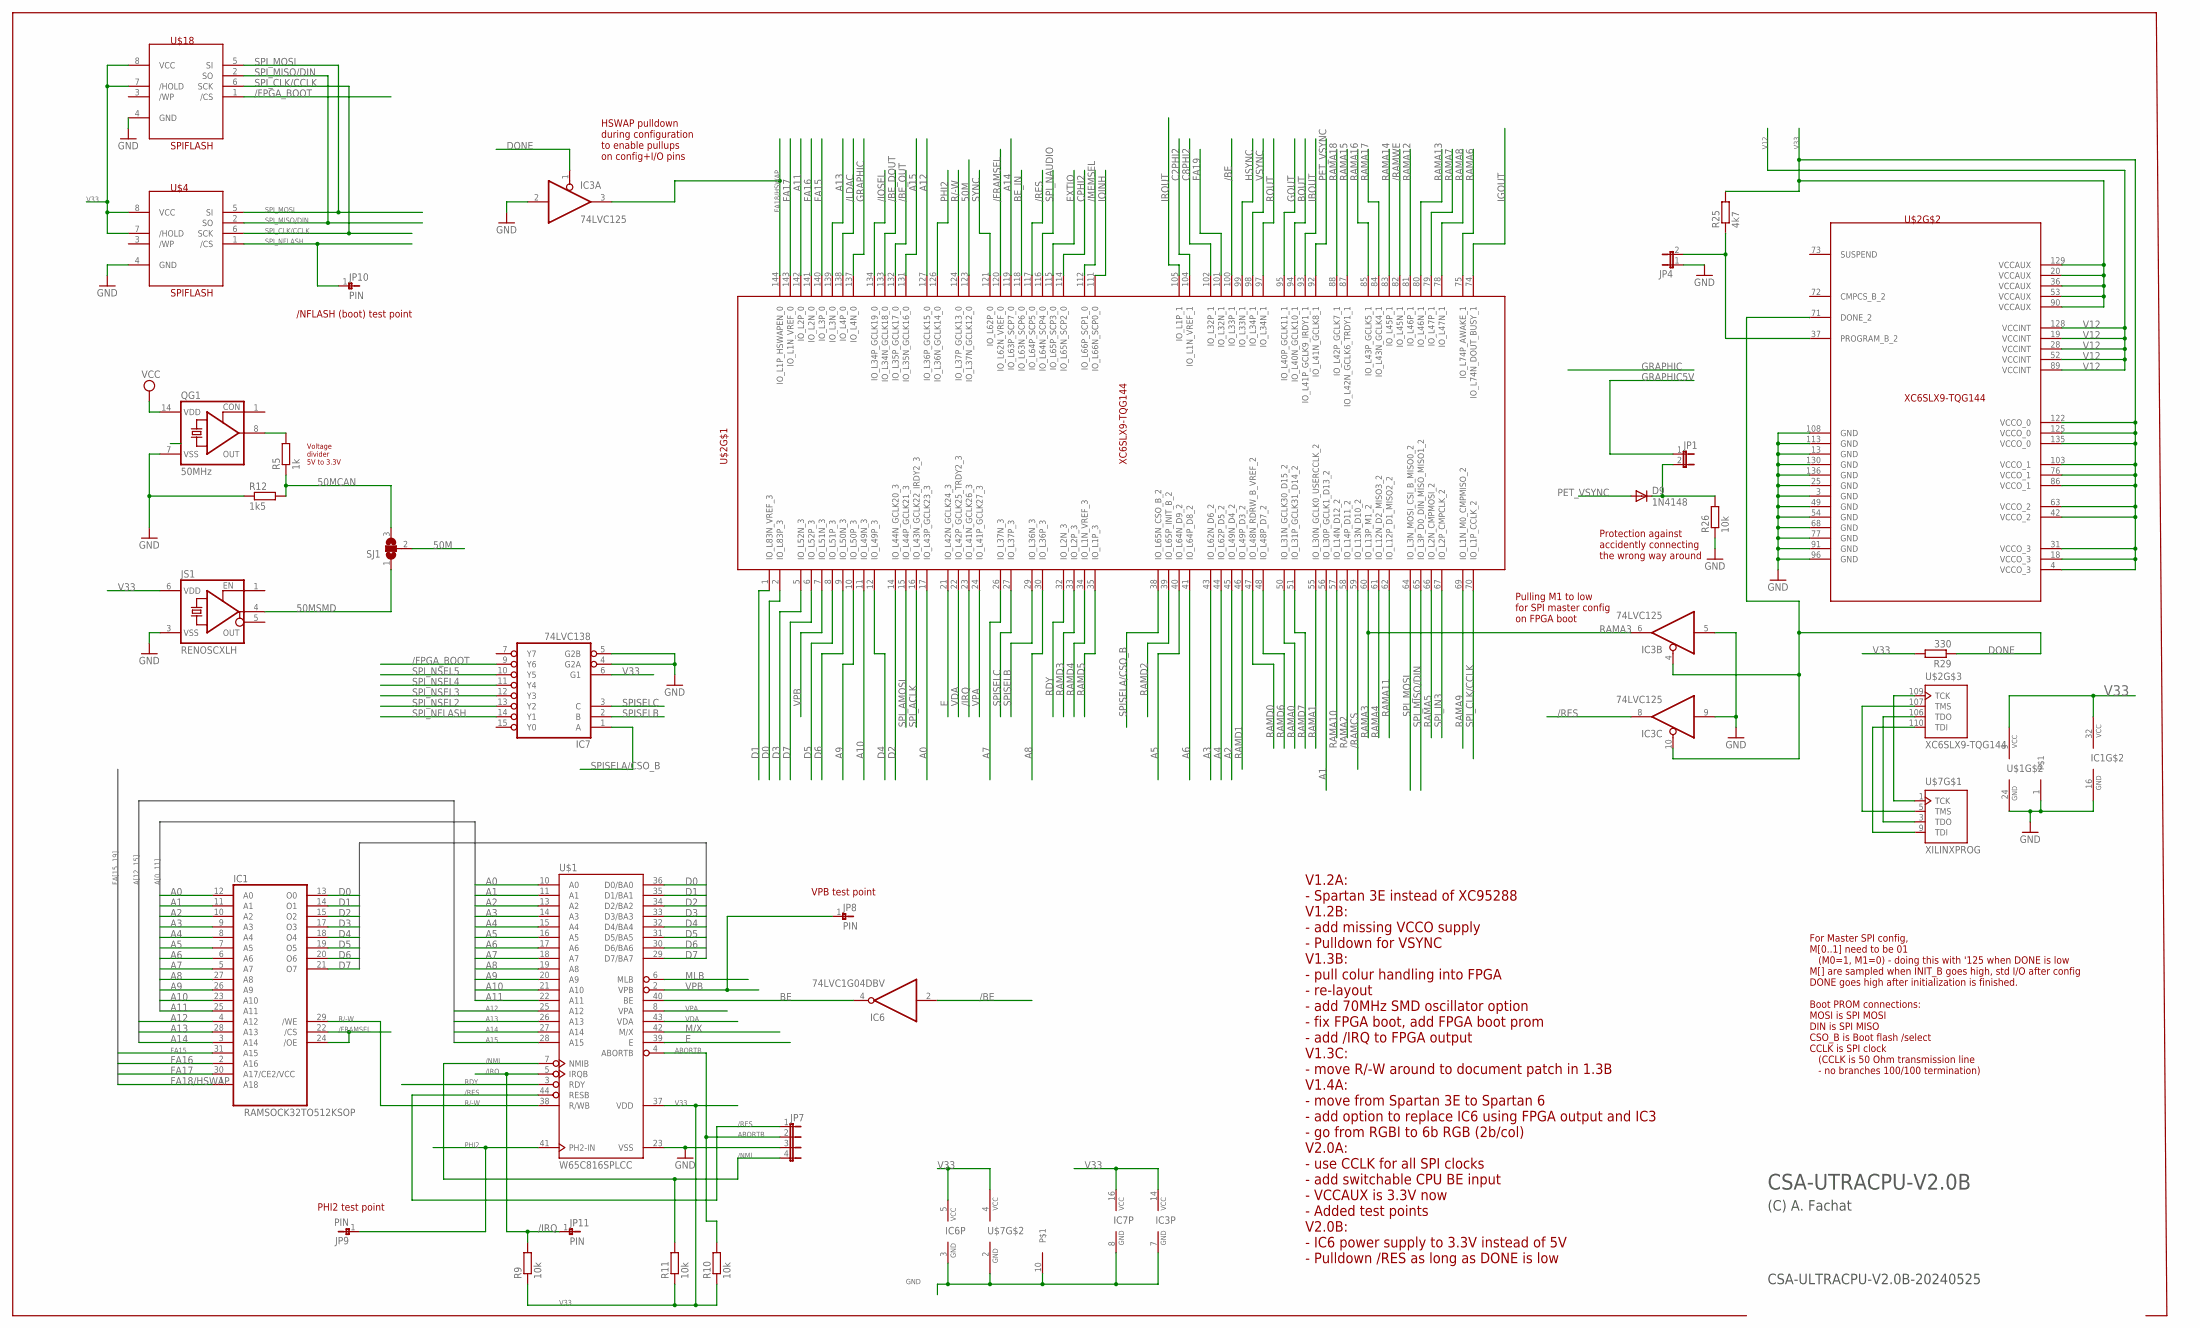
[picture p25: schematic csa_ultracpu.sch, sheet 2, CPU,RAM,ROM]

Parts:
D9: 1N4148; D-5
IC1: RAMSOCK32TO512KSOP; SOP32
IC3: 74LVC125; SO14
IC6: 74LVC1G04DBV; SOT23-5
IC7: 74LVC138; SO16
JP1, JP4: JP1E; JP1
JP7: JP4E; JP4
JP8, JP9, JP10, JP11: PIN
JS1: RENOSCXLH; RENJS6
QG1: 50MHz; SG51
R5: 1k; 0207/2V
R9, R10, R11, R26: 10k; 0207/2V
R12: 1k5; 0207/2V
R25: 4k7; 0207/2V
R29: 330; 0207/2V
SJ1: SJ2W; SJ_2
U$1: W65C816SPLCC; PLCC44
U$2: XC6SLX9-TQG144; TQFP144
U$4, U$18: SPIFLASH; DIL08
U$7: XILINXPROG; FLAT10BOX

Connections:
50M: SJ1.2, U$2.123 (IO_L37N_GCLK12_0)
50MCAN: R5.1, R12.2, SJ1.3
50MSMD: JS1.4 (OUT1), SJ1.1
/BE: IC6.2 (I), U$2.100 (IO_L33P_1)
/BE_DOUT: U$2.133 (IO_L34N_GCLK18_0); also elsewhere on the board
/BE_OUT: U$2.132 (IO_L35P_GCLK17_0); also elsewhere on the board
/FPGA_BOOT: IC7.9 (Y6), U$18.1 (/CS)
/FRAMSEL: IC1.22 (/CS), IC1.24 (/OE), U$2.120 (IO_L62N_VREF_0)
/IOSEL: U$2.134 (IO_L34P_GCLK19_0); also elsewhere on the board
/IRQ: JP11.1, R9.2, U$1.5 (IRQB), U$2.23 (IO_L41N_GCLK26_3); also elsewhere on the board
/LDAC: U$2.138 (IO_L4P_0); also elsewhere on the board
/MEMSEL: U$2.112 (IO_L66P_SCP1_0); also elsewhere on the board
/NMI: JP7.4, R11.2, U$1.7 (NMIB); also elsewhere on the board
/RAMCS: U$2.59 (IO_L13N_D10_2); also elsewhere on the board
/RAMWE: U$2.82 (IO_L45N_1); also elsewhere on the board
/RES: IC3.8 (O), JP7.1, U$1.44 (RESB), U$2.117 (IO_L64P_SCP5_0); also elsewhere on the board
A0: IC1.12 (A0), U$1.10 (A0), U$2.17 (IO_L43P_GCLK23_3); also elsewhere on the board
A1: IC1.11 (A1), U$1.11 (A1), U$2.56 (IO_L30P_GCLK1_D13_2); also elsewhere on the board
A2: IC1.10 (A2), U$1.13 (A2), U$2.45 (IO_L49N_D4_2); also elsewhere on the board
A3: IC1.9 (A3), U$1.14 (A3), U$2.43 (IO_L62N_D6_2); also elsewhere on the board
A4: IC1.8 (A4), U$1.15 (A4), U$2.44 (IO_L62P_D5_2); also elsewhere on the board
A5: IC1.7 (A5), U$1.16 (A5), U$2.40 (IO_L64N_D9_2); also elsewhere on the board
A6: IC1.6 (A6), U$1.17 (A6), U$2.41 (IO_L64P_D8_2); also elsewhere on the board
A7: IC1.5 (A7), U$1.18 (A7), U$2.26 (IO_L37N_3); also elsewhere on the board
A8: IC1.27 (A8), U$1.19 (A8), U$2.30 (IO_L36P_3); also elsewhere on the board
A9: IC1.26 (A9), U$1.20 (A9), U$2.10 (IO_L50P_3); also elsewhere on the board
A10: IC1.23 (A10), U$1.21 (A10), U$2.11 (IO_L49N_3); also elsewhere on the board
A11: IC1.25 (A11), U$1.22 (A11), U$2.142 (IO_L2P_0); also elsewhere on the board
A12: IC1.4 (A12), U$1.25 (A12), U$2.127 (IO_L36P_GCLK15_0); also elsewhere on the board
A13: IC1.28 (A13), U$1.26 (A13), U$2.139 (IO_L3N_0); also elsewhere on the board
A14: IC1.3 (A14), U$1.27 (A14), U$2.119 (IO_L63P_SCP7_0); also elsewhere on the board
A15: U$1.28 (A15), U$2.131 (IO_L35N_GCLK16_0); also elsewhere on the board
ABORTB: JP7.2, R10.2, U$1.4 (ABORTB)
BE: IC6.4 (O), U$1.40 (BE)
BE_IN: U$2.118 (IO_L63N_SCP6_0); also elsewhere on the board
BOUT: U$2.94 (IO_L40N_GCLK10_1); also elsewhere on the board
C2PHI2: U$2.104 (IO_L1N_VREF_1); also elsewhere on the board
C8PHI2: U$2.102 (IO_L32P_1); also elsewhere on the board
CPHI2: U$2.114 (IO_L65N_SCP2_0); also elsewhere on the board
D0: IC1.13 (O0), U$1.36 (D0/BA0), U$2.2 (IO_L83P_3); also elsewhere on the board
D1: IC1.14 (O1), U$1.35 (D1/BA1), U$2.1 (IO_L83N_VREF_3); also elsewhere on the board
D2: IC1.15 (O2), U$1.34 (D2/BA2), U$2.14 (IO_L44N_GCLK20_3); also elsewhere on the board
D3: IC1.17 (O3), U$1.33 (D3/BA3), U$2.5 (IO_L52N_3); also elsewhere on the board
D4: IC1.18 (O4), U$1.32 (D4/BA4), U$2.12 (IO_L49P_3); also elsewhere on the board
D5: IC1.19 (O5), U$1.31 (D5/BA5), U$2.8 (IO_L51P_3); also elsewhere on the board
D6: IC1.20 (O6), U$1.30 (D6/BA6), U$2.9 (IO_L50N_3); also elsewhere on the board
D7: IC1.21 (O7), U$1.29 (D7/BA7), U$2.6 (IO_L52P_3); also elsewhere on the board
DONE: IC3.1 (OE), IC3.4 (OE), IC3.10 (OE), R29.1, U$2.71 (DONE_2)
E: U$1.39 (E), U$2.21 (IO_L42N_GCLK24_3)
EXTIO: U$2.115 (IO_L65P_SCP3_0); also elsewhere on the board
FA15: IC1.31 (A15), U$2.140 (IO_L3P_0)
FA16: IC1.2 (A16), U$2.141 (IO_L2N_0); also elsewhere on the board
FA17: IC1.30 (A17/CE2/VCC), U$2.143 (IO_L1N_VREF_0); also elsewhere on the board
FA18/HSWAP: IC1.1 (A18), IC3.3 (O), U$2.144 (IO_L1P_HSWAPEN_0); also elsewhere on the board
FA19: U$2.101 (IO_L32N_1); also elsewhere on the board
GND: IC1.16 (GND), IC3.2 (I), IC3.5 (I), IC3.7 (GND), IC3.9 (I), IC6.3 (GND), IC7.4 (G2A), IC7.5 (G2B), IC7.8 (GND), JP4.1, JP7.3, JS1.3 (VSS), QG1.7 (VSS), R12.1, R26.1, U$1.1, U$1.23 (VSS), U$1.24 (GND), U$2.3 (GND), U$2.13 (GND), U$2.25 (GND), U$2.49 (GND), U$2.54 (GND), U$2.68 (GND), U$2.77 (GND), U$2.91 (GND), U$2.96 (GND), U$2.108 (GND), U$2.113 (GND), U$2.130 (GND), U$2.136 (GND), U$4.4 (GND), U$7.2 (GND), U$7.10, U$18.4 (GND); also elsewhere on the board
GOUT: U$2.95 (IO_L40P_GCLK11_1); also elsewhere on the board
GRAPHIC: U$2.137 (IO_L4N_0); also elsewhere on the board
GRAPHIC5V: JP1.1; also elsewhere on the board
HSYNC: U$2.99 (IO_L33N_1); also elsewhere on the board
IBOUT: U$2.93 (IO_L41P_GCLK9_IRDY1_1); also elsewhere on the board
IGOUT: U$2.74 (IO_L74N_DOUT_BUSY_1); also elsewhere on the board
IOINH: U$2.111 (IO_L66N_SCP0_0); also elsewhere on the board
IROUT: U$2.105 (IO_L1P_1); also elsewhere on the board
M/X: U$1.42 (M/X)
MLB: U$1.6 (MLB)
unnamed: QG1.8 (OUT), R5.2
unnamed: D9.C, JP1.2, R26.2
PET_VSYNC: D9.A, U$2.92 (IO_L41N_GCLK8_1)
PHI2: JP9.1, U$1.41 (PH2-IN), U$2.126 (IO_L36N_GCLK14_0)
PROG_B: JP4.2, R25.1, U$2.37 (PROGRAM_B_2)
R/-W: IC1.29 (/WE), U$1.38 (R/WB), U$2.124 (IO_L37P_GCLK13_0); also elsewhere on the board
RAMA0: U$2.50 (IO_L31N_GCLK30_D15_2); also elsewhere on the board
RAMA1: U$2.55 (IO_L30N_GCLK0_USERCCLK_2); also elsewhere on the board
RAMA2: U$2.58 (IO_L14P_D11_2); also elsewhere on the board
RAMA3: IC3.6 (O), U$2.60 (IO_L13P_M1_2); also elsewhere on the board
RAMA4: U$2.61 (IO_L12N_D2_MISO3_2); also elsewhere on the board
RAMA5: U$2.66 (IO_L2N_CMPMOSI_2); also elsewhere on the board
RAMA6: U$2.75 (IO_L74P_AWAKE_1); also elsewhere on the board
RAMA7: U$2.79 (IO_L47P_1); also elsewhere on the board
RAMA8: U$2.78 (IO_L47N_1); also elsewhere on the board
RAMA9: U$2.69 (IO_L1N_M0_CMPMISO_2); also elsewhere on the board
RAMA10: U$2.57 (IO_L14N_D12_2); also elsewhere on the board
RAMA11: U$2.62 (IO_L12P_D1_MISO2_2); also elsewhere on the board
RAMA12: U$2.81 (IO_L46P_1); also elsewhere on the board
RAMA13: U$2.80 (IO_L46N_1); also elsewhere on the board
RAMA14: U$2.83 (IO_L45P_1); also elsewhere on the board
RAMA15: U$2.87 (IO_L42N_GCLK6_TRDY1_1); also elsewhere on the board
RAMA16: U$2.85 (IO_L43P_GCLK5_1); also elsewhere on the board
RAMA17: U$2.84 (IO_L43N_GCLK4_1); also elsewhere on the board
RAMA18: U$2.88 (IO_L42P_GCLK7_1); also elsewhere on the board
RAMD0: U$2.47 (IO_L48N_RDRW_B_VREF_2); also elsewhere on the board
RAMD1: U$2.46 (IO_L49P_D3_2); also elsewhere on the board
RAMD2: U$2.39 (IO_L65P_INIT_B_2); also elsewhere on the board
RAMD3: U$2.33 (IO_L2P_3); also elsewhere on the board
RAMD4: U$2.34 (IO_L1N_VREF_3); also elsewhere on the board
RAMD5: U$2.35 (IO_L1P_3); also elsewhere on the board
RAMD6: U$2.48 (IO_L48P_D7_2); also elsewhere on the board
RAMD7: U$2.51 (IO_L31P_GCLK31_D14_2); also elsewhere on the board
RDY: U$1.3 (RDY), U$2.32 (IO_L2N_3); also elsewhere on the board
ROUT: U$2.97 (IO_L34N_1); also elsewhere on the board
SPISELA/CSO_B: IC7.1 (A), U$2.38 (IO_L65N_CSO_B_2)
SPISELB: IC7.2 (B), U$2.29 (IO_L36N_3)
SPISELC: IC7.3 (C), U$2.27 (IO_L37P_3)
SPI_ACLK: U$2.16 (IO_L43N_GCLK22_IRDY2_3); also elsewhere on the board
SPI_AMOSI: U$2.15 (IO_L44P_GCLK21_3); also elsewhere on the board
SPI_CLK/CCLK: U$2.70 (IO_L1P_CCLK_2), U$4.6 (SCK), U$18.6 (SCK); also elsewhere on the board
SPI_IN3: U$2.67 (IO_L2P_CMPCLK_2); also elsewhere on the board
SPI_MISO/DIN: U$2.65 (IO_L3P_D0_DIN_MISO_MISO1_2), U$4.2 (SO), U$18.2 (SO); also elsewhere on the board
SPI_MOSI: U$2.64 (IO_L3N_MOSI_CSI_B_MISO0_2), U$4.5 (SI), U$18.5 (SI); also elsewhere on the board
SPI_NAUDIO: U$2.116 (IO_L64N_SCP4_0); also elsewhere on the board
SPI_NFLASH: IC7.14 (Y1), JP10.1, U$4.1 (/CS)
SPI_NSEL2: IC7.13 (Y2); also elsewhere on the board
SPI_NSEL3: IC7.12 (Y3); also elsewhere on the board
SPI_NSEL4: IC7.11 (Y4); also elsewhere on the board
SPI_NSEL5: IC7.10 (Y5); also elsewhere on the board
SYNC: U$2.121 (IO_L62P_0); also elsewhere on the board
TCK: U$2.109 (TCK), U$7.1 (TCK)
TDI: U$2.110 (TDI), U$7.9 (TDI)
TDO: U$2.106 (TDO), U$7.3 (TDO)
TMS: U$2.107 (TMS), U$7.5 (TMS)
V12: U$2.19 (VCCINT), U$2.28 (VCCINT), U$2.52 (VCCINT), U$2.89 (VCCINT), U$2.128 (VCCINT); also elsewhere on the board
V33: IC1.32 (VCC), IC3.14 (VCC), IC6.5 (VCC), IC7.6 (G1), IC7.16 (VCC), JS1.6 (VDD), R9.1, R10.1, R11.1, R25.2, R29.2, U$1.9 (VCC), U$1.37 (VDD), U$2.4 (VCCO_3), U$2.18 (VCCO_3), U$2.20 (VCCAUX), U$2.31 (VCCO_3), U$2.36 (VCCAUX), U$2.42 (VCCO_2), U$2.53 (VCCAUX), U$2.63 (VCCO_2), U$2.76 (VCCO_1), U$2.86 (VCCO_1), U$2.90 (VCCAUX), U$2.103 (VCCO_1), U$2.122 (VCCO_0), U$2.125 (VCCO_0), U$2.129 (VCCAUX), U$2.135 (VCCO_0), U$4.7 (/HOLD), U$4.8 (VCC), U$7.4 (VCC), U$18.7 (/HOLD), U$18.8 (VCC); also elsewhere on the board
VCC: QG1.14 (VDD); also elsewhere on the board
VDA: U$1.43 (VDA), U$2.22 (IO_L42P_GCLK25_TRDY2_3)
VPA: U$1.8 (VPA), U$2.24 (IO_L41P_GCLK27_3)
VPB: JP8.1, U$1.2 (VPB), U$2.7 (IO_L51N_3)
VSYNC: U$2.98 (IO_L34P_1); also elsewhere on the board

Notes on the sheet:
CSA-ULTRACPU-V2.0B-20240525
CSA-UTRACPU-V2.0B
(C) A. Fachat
V1.2A: - Spartan 3E instead of XC95288 V1.2B: - add missing VCCO supply - Pulldown for VSYNC V1.3B: - pull colur handling into FPGA - re-layout - add 70MHz SMD oscillator option - fix FPGA boot, add FPGA boot prom - add /IRQ to FPGA output V1.3C: - move R/-W around to document patch in 1.3B V1.4A: 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
Voltage divider 5V to 3.3V
Protection against accidently connecting the wrong way around
For Master SPI config, M[0..1] need to be 01 (M0=1, M1=0) - doing this with '125 when DONE is low M[] are sampled when INIT_B goes high, std I/O after config DONE goes high after initialization is finished. Boot PROM connections: MOSI is SPI MOSI DIN is SPI MISO CSO_B is Boot flash /select CCLK is 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
HSWAP pulldown during configuration to enable pullups on config+I/O pins
Pulling M1 to low for SPI master config on FPGA boot
VPB test point
PHI2 test point
/NFLASH (boot) test point

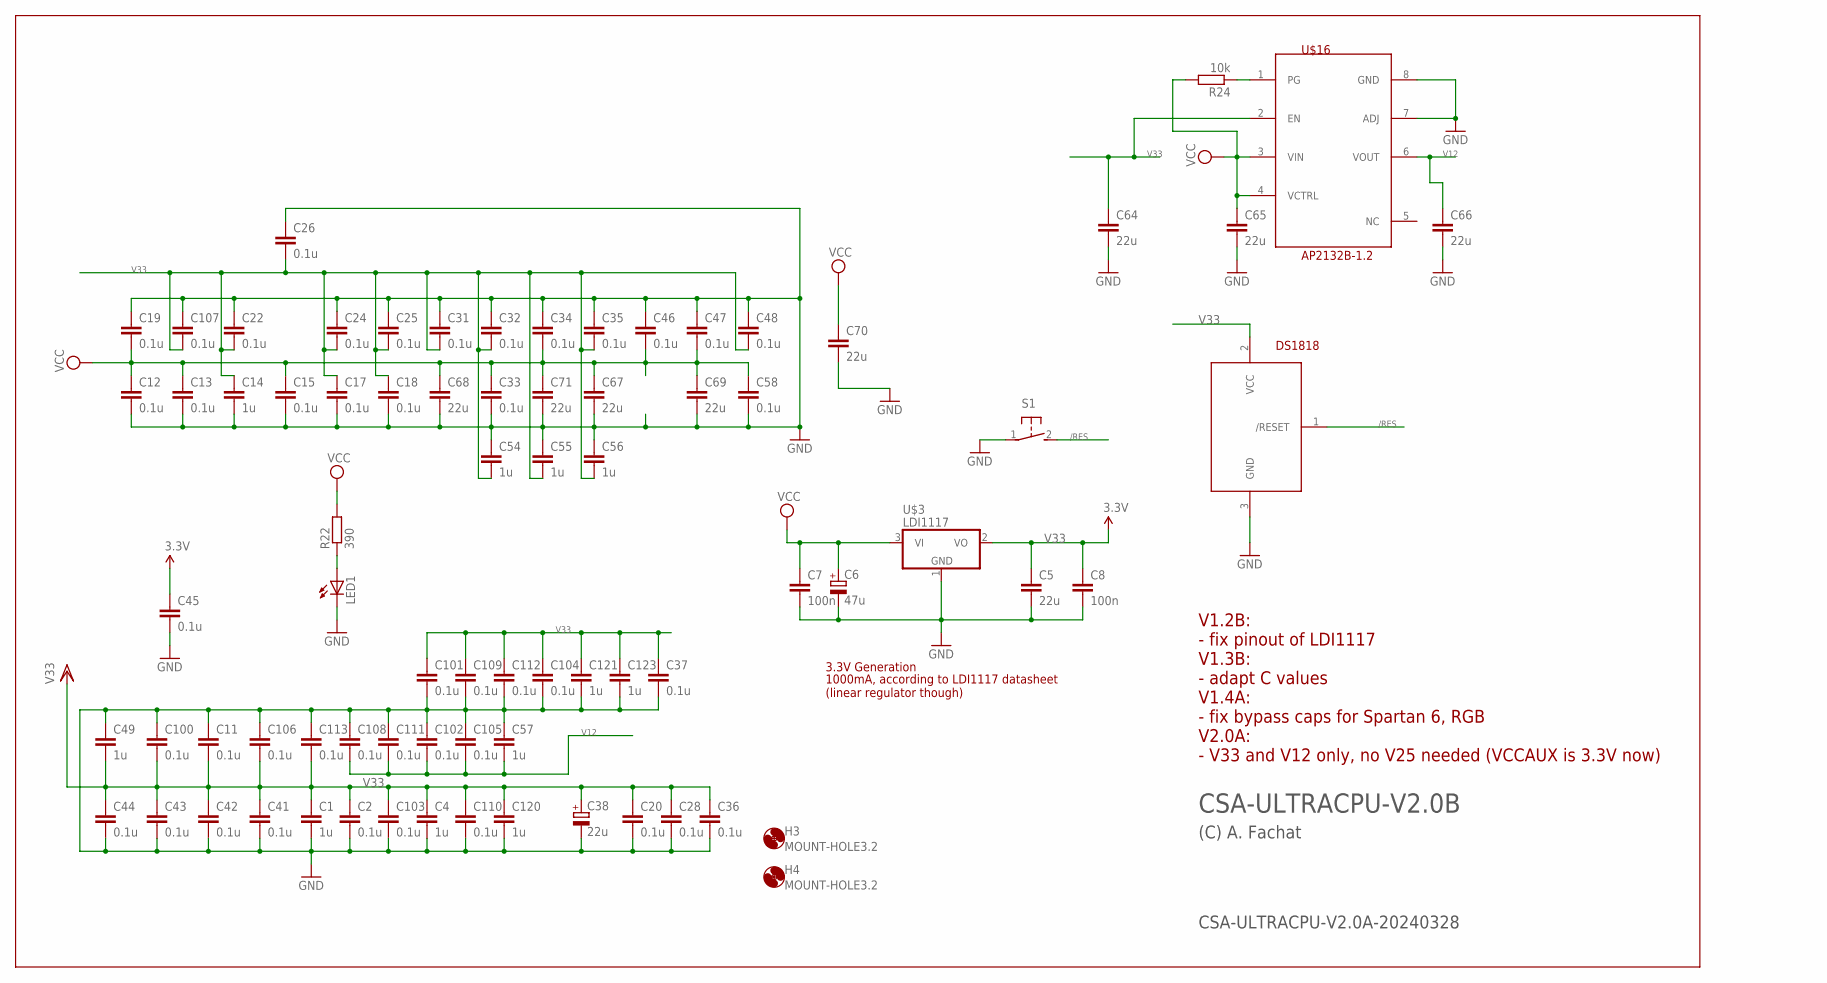
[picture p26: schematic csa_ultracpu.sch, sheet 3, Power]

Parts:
C1, C4, C14, C49, C54, C55, C56, C57, C120, C121, C123: 1u; C0603
C2, C11, C12, C13, C15, C17, C18, C19, C20, C22, C24, C25, C26, C28, C31, C32, C33, C34, C35, C36, C37, C41, C42, C43, C44, C45, C46, C47, C48, C58, C100, C101, C102, C103, C104, C105, C106, C107, C108, C109, C110, C111, C112, C113: 0.1u; C0603
C5, C64, C65, C66, C67, C68, C69, C70, C71: 22u; C0805
C6: 47u; E2,5-6
C7, C8: 100n; C0603
C38: 22u; E2,5-6
DS1818: DS1818; TO92
H3, H4: MOUNT-HOLE3.2; 3,2
LED1: LED3MM
R22: 390; 0207/2V
R24: 10k; 0207/2V
S1: 31-XX; B3F-31XX
U$3: LDI1117; SOT223
U$16: AP2132B-1.2; PSOP-8-FIXED

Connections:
/RES: DS1818.1 (/RESET), S1.2 (S); also elsewhere on the board
GND: C1.2, C2.2, C4.2, C5.2, C6.-, C7.2, C8.2, C11.1, C12.2, C13.2, C14.2, C15.2, C17.2, C18.2, C19.1, C20.2, C22.1, C24.1, C25.1, C26.1, C28.2, C31.1, C32.1, C33.2, C34.1, C35.1, C36.2, C37.2, C38.-, C41.2, C42.2, C43.2, C44.2, C45.2, C46.1, C47.1, C48.1, C49.1, C54.1, C55.1, C56.1, C57.1, C58.2, C64.2, C65.2, C66.2, C67.2, C68.2, C69.2, C70.2, C71.2, C100.1, C101.2, C102.1, C103.2, C104.2, C105.1, C106.1, C107.1, C108.1, C109.2, C110.2, C111.1, C112.2, C113.1, C120.2, C121.2, C123.2, DS1818.3 (GND), LED1.K (C), S1.1, U$3.1 (GND), U$16.7 (ADJ), U$16.8 (GND); also elsewhere on the board
unnamed: R24.1, U$16.1 (PG)
unnamed: LED1.A, R22.1
V12: C57.2, C66.1, C102.2, C105.2, C108.2, C111.2, U$16.6 (VOUT); also elsewhere on the board
V33: C1.1, C2.1, C4.1, C5.1, C8.1, C11.2, C14.1, C17.1, C18.1, C20.1, C22.2, C24.2, C25.2, C26.2, C28.1, C31.2, C32.2, C35.2, C36.1, C37.1, C38.+, C41.1, C42.1, C43.1, C44.1, C45.1, C48.2, C49.2, C54.2, C55.2, C56.2, C64.1, C100.2, C101.1, C103.1, C104.1, C106.2, C107.2, C109.1, C110.1, C112.1, C113.2, C120.1, C121.1, C123.1, DS1818.2 (VCC), U$3.2 (VO), U$16.2 (EN); also elsewhere on the board
VCC: C6.+, C7.1, C12.1, C13.1, C15.1, C19.2, C33.1, C34.2, C46.2, C47.2, C58.1, C65.1, C67.1, C68.1, C69.1, C70.1, C71.1, R22.2, R24.2, U$3.3 (VI), U$16.3 (VIN), U$16.4 (VCTRL); also elsewhere on the board

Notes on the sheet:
CSA-ULTRACPU-V2.0A-20240328
CSA-ULTRACPU-V2.0B
(C) A. Fachat
3.3V Generation
1000mA, according to LDI1117 datasheet (linear regulator though)
DS1818
V1.2B: - fix pinout of LDI1117 V1.3B: - adapt C values V1.4A: - fix bypass caps for Spartan 6, RGB V2.0A: - V33 and V12 only, no V25 needed (VCCAUX is 3.3V now)


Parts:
D1, D2, D3, D4, D7, D10: 1N4148DO35-7; DO35-7
IC2: 74HCT245DW; SO20W
R7, R8: 68; 0204V
R13, R14, R15: 470; 0204V
R18, R19, R20: 1k; 0204V
U$5, U$6, U$8, U$10, U$11: PESD5V0L1BA; SOD323
X2: D-SUB15-HDR15RA; HDR15RA

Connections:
BLUE: D4.A, IC2.16 (B3)
BOUT: IC2.4 (A3); also elsewhere on the board
GND: IC2.10 (GND), IC2.19 (G), U$5.1 (2), U$6.1 (2), U$8.1 (2), U$10.1 (2), U$11.1 (2), X2.5, X2.6, X2.7, X2.8; also elsewhere on the board
GOUT: IC2.3 (A2); also elsewhere on the board
GREEN: D3.A, IC2.17 (B2)
HORIZONTAL: IC2.14 (B5), R8.1
HSYNC: IC2.6 (A5); also elsewhere on the board
IBLUE: D7.A, IC2.15 (B4)
IBOUT: IC2.5 (A4); also elsewhere on the board
IGOUT: IC2.8 (A7); also elsewhere on the board
IGREEN: D1.A, IC2.12 (B7)
IRED: D10.A, IC2.11 (B8)
IROUT: IC2.9 (A8); also elsewhere on the board
unnamed: D1.C, R19.1
unnamed: D7.C, R18.1
unnamed: R15.2, R20.2, U$8.2 (1), X2.1
unnamed: R14.2, R19.2, U$10.2 (1), X2.2
unnamed: R13.2, R18.2, U$11.2 (1), X2.3
unnamed: D10.C, R20.1
unnamed: R8.2, U$6.2 (1), X2.13
unnamed: R7.2, U$5.2 (1), X2.14
unnamed: D2.C, R15.1
unnamed: D3.C, R14.1
unnamed: D4.C, R13.1
RED: D2.A, IC2.18 (B1)
ROUT: IC2.2 (A1); also elsewhere on the board
VCC: IC2.1 (DIR), IC2.20 (VCC); also elsewhere on the board
VERTICAL: IC2.13 (B6), R7.1
VSYNC: IC2.7 (A6); also elsewhere on the board

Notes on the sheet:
CSA-ULTRACPU-V1.4A-20240206
CSA-ULTRACPU-V2.0B
(C) A. Fachat
V1.0B: - Added "Brown Fix" V1.1A: - 3.3/5V level converter - VGA ESD protection diodes V1.4A: - go from RGBI to 6bit RGB (2b/col) (replacing IC6 "brownfix" in the process
3.3V side
5V side

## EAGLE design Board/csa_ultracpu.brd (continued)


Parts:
C9: 1.0u Cer; C0603
C16, C21, C27: 0.1u; C0603
C29, C30, C39, C40: 18p; C0603
D5, D6, D8: 1N4148; D-5
IC8: MAX3421E; TQFP32-5MM
JP2, JP3: JP1E; JP1
Q2: 32kHz; TC26H
Q3: 12MHz; HC49/S
R1, R2, R4: 33; 0204/7
U$9: ETHOLIENC
U$12: SD-CARD-GRAVI; GRAVITECH-SDCARD
U$13: MCP79510; MSOP10
U$14, U$15: PESD5V0L1BA; SOD323
USB1: USB-A-H

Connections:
12MHZ: C40.1, IC8.24 (X1), Q3.2
/IRQ: D5.A, D6.A; also elsewhere on the board
/RES: D8.C, IC8.12 (/RES); also elsewhere on the board
/USBINT: D5.C, IC8.18 (INT)
DETECT: R4.1, U$12.CD
FOO: U$12.3V3 (V33)
GND: C9.2, C16.2, C21.2, C27.2, C29.2, C30.2, C39.2, C40.2, IC8.3 (GND), IC8.19 (GND), JP2.2, U$9.2_4 (GND), U$12.GND, U$13.5 (VSS), U$14.1 (2), U$15.1 (2), USB1.GND, USB1.GND@1 (GND), USB1.GND@2 (GND); also elsewhere on the board
unnamed: IC8.20 (D-), R1.1
unnamed: IC8.21 (D+), R2.1
unnamed: C29.1, Q2.2, U$13.1 (X1)
unnamed: D6.C, U$9.1_5 (INT)
unnamed: R2.2, U$14.2 (1), USB1.D+
unnamed: R1.2, U$15.2 (1), USB1.D-
unnamed: IC8.26 (GPIN0), R4.2
unnamed: C30.1, Q2.1, U$13.2 (X2)
unnamed: D8.A, U$9.2_3 (RST)
unnamed: C39.1, IC8.25 (X0), Q3.1
SPI_CLK/CCLK: IC8.13 (SCLK), U$9.1_1 (SCK), U$12.SCK, U$13.8 (SCK); also elsewhere on the board
SPI_IN3: U$12.DO; also elsewhere on the board
SPI_MISO/DIN: IC8.15 (MISO), U$9.1_3 (MISO), U$13.7 (SO); also elsewhere on the board
SPI_MOSI: IC8.16 (MOSI), U$9.1_2 (MOSI), U$12.DI, U$13.6 (SI); also elsewhere on the board
SPI_NSEL2: IC8.14 (/SS); also elsewhere on the board
SPI_NSEL3: U$12.CS; also elsewhere on the board
SPI_NSEL4: U$9.2_2 (CS); also elsewhere on the board
SPI_NSEL5: U$13.4 (/CS); also elsewhere on the board
V33: C9.1, C21.1, C27.1, IC8.2 (VL), IC8.23 (VCC), U$9.2_5 (V33), U$13.10 (VCC); also elsewhere on the board
VBAT: JP2.1, JP3.1, U$13.3 (VBAT)
VBUF: JP3.2; also elsewhere on the board
VCC: C16.1, U$12.VIN, USB1.VBUS; also elsewhere on the board

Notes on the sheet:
Watch orientation on board!
Note: MAX3421 TQFP-5MM
Non-commercial use only
package layout by SparkFun
CSA-ULTRACPU-V1.1A-20220820
CSA-ULTRACPU-V2.0B
(C) A. Fachat
Connect Coin Cell on JP2
JP3 to use VBUF from CSA BUS
V1.1A: - added USB ESD protection diodes


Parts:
C3, C10: 1u; C050-025X075
IC10: RAMSOCK32TO512KSOP; SOP32
JP5: JP2E; JP2
R28, R31: 100; 0204V
R30, R32: 680; 0204V
SN1: MCP48X2; SOIC8
X1: SJ1-3513N; 1503_09

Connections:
/LDAC: SN1.5 (/LDAC); also elsewhere on the board
/RAMCS: IC10.22 (/CS), IC10.24 (/OE); also elsewhere on the board
/RAMWE: IC10.29 (/WE); also elsewhere on the board
GND: IC10.16 (GND), JP5.2, R30.1, R32.1, SN1.7 (GND), X1.1; also elsewhere on the board
unnamed: R28.1, SN1.6 (VOUTB)
unnamed: C3.2, R30.2, X1.2
unnamed: R31.1, SN1.8 (VOUTA)
unnamed: C10.1, JP5.1, R31.2
unnamed: C10.2, R32.2, X1.3
unnamed: C3.1, JP5.3, R28.2
RAMA0: IC10.12 (A0); also elsewhere on the board
RAMA1: IC10.11 (A1); also elsewhere on the board
RAMA2: IC10.10 (A2); also elsewhere on the board
RAMA3: IC10.9 (A3); also elsewhere on the board
RAMA4: IC10.8 (A4); also elsewhere on the board
RAMA5: IC10.7 (A5); also elsewhere on the board
RAMA6: IC10.6 (A6); also elsewhere on the board
RAMA7: IC10.5 (A7); also elsewhere on the board
RAMA8: IC10.27 (A8); also elsewhere on the board
RAMA9: IC10.26 (A9); also elsewhere on the board
RAMA10: IC10.23 (A10); also elsewhere on the board
RAMA11: IC10.25 (A11); also elsewhere on the board
RAMA12: IC10.4 (A12); also elsewhere on the board
RAMA13: IC10.28 (A13); also elsewhere on the board
RAMA14: IC10.3 (A14); also elsewhere on the board
RAMA15: IC10.31 (A15); also elsewhere on the board
RAMA16: IC10.2 (A16); also elsewhere on the board
RAMA17: IC10.30 (A17/CE2/VCC); also elsewhere on the board
RAMA18: IC10.1 (A18); also elsewhere on the board
RAMD0: IC10.13 (O0); also elsewhere on the board
RAMD1: IC10.14 (O1); also elsewhere on the board
RAMD2: IC10.15 (O2); also elsewhere on the board
RAMD3: IC10.17 (O3); also elsewhere on the board
RAMD4: IC10.18 (O4); also elsewhere on the board
RAMD5: IC10.19 (O5); also elsewhere on the board
RAMD6: IC10.20 (O6); also elsewhere on the board
RAMD7: IC10.21 (O7); also elsewhere on the board
SPI_ACLK: SN1.3 (SCK); also elsewhere on the board
SPI_AMOSI: SN1.4 (SDI); also elsewhere on the board
SPI_NAUDIO: SN1.2 (/CS); also elsewhere on the board
V33: IC10.32 (VCC), SN1.1 (VCC); also elsewhere on the board

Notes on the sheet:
CSA-ULTRACPU-V1.3C-20231105
CSA-ULTRACPU-V2.0B
(C) A. Fachat
V1.1A: - 3.3V IC families V1.3A: - pull color logic into FPGA V1.3B: - add audio output via MCP4802 V1.3C - stereo jack to get out both channels



Board: 4 copper layers, 160.0 x 100.1 mm, 175 parts (28 on the bottom side), 219 nets.

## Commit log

2022-04-23 Trying to fix a strange non-reset on power-up behaviour
2023-09-23 more work on ground up timing rework
2023-09-26 started working on raster interrupt - but current test hw has no irq output...
2023-09-27 compare regs with VDC from https://www.c64-wiki.de/wiki/VDC, add TODOs
2023-10-15 switch timing to q50m in ipl
2023-10-16 pin constraints to LVTTL
2023-10-18 simplify top; add system jitter attribute on qclk
2023-11-03 basic dma engine to send out data via dac
2023-11-04 DMA engine for DAC working
2023-11-05 make DAC DMA len full VRAM size
2023-11-06 dac dma interrupt
2023-11-06 work on DAC DMA IRQ and restart
2023-11-11 implemented - not tested yet - sprite/border/raster/sprite interrupts
2023-11-12 fix missing sprite-border interrupt
2023-12-21 revert to VDRIVE interrupt on boot (upet compat)
2024-01-31 update board to 1.3C
    [csa_ultracpu.brd, csa_ultracpu.csv, csa_ultracpu.sch]
2024-03-29 SPI changes
2024-04-25 IPL waits a time before using spi_clk as the FPGA seems to switch if off way after initial config is done...
2024-06-17 update board to 2.0b from internal repo
    [csa_ultracpu.brd, csa_ultracpu.csv, csa_ultracpu.sch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]
2024-12-13 more work on r2.1a
    [A%2fV_Out.kicad_sch, Audio%2fVideo.kicad_sch, BUS_I%2fO.kicad_sch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]
2024-12-15 more work on r2.1a - only bom xls is missing/outdated
    [CPU,RAM,ROM.kicad_sch, Power.kicad_sch, USB.kicad_sch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]
2024-12-25 add Flash ROM type prints on PCB
    [csa_ultracpu.kicad_pcb]
2024-12-26 first try on BOM
    [Power.kicad_sch, bom.csv, cbm_ultipet-2.1a-bom.xlsx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]
2024-12-26 ultracpu 2.1a
    [csa_ultracpu.kicad_pcb]
2024-12-28 work on BOM
    [bom.csv, cbm_ultipet-2.1a-bom.xlsx, csa_ultracpu-2.1a-bom.xlsx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]
2024-12-31 fix bom
    [csa_ultracpu-2.1a-bom.xlsx]
2026-06-02 start r2.2a, moving from VGA to HDMI
    [A%2fV_Out.kicad_sch, Audio%2fVideo.kicad_sch, BUS_I%2fO.kicad_sch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]
2026-07-19 work on hdmi
    [A%2fV_Out.kicad_sch, Audio%2fVideo.kicad_sch, BUS_I%2fO.kicad_sch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]
2026-08-05 start working on 3.0 with larger FPGA
    [A%2fV_Out.kicad_sch, Audio%2fVideo.kicad_sch, BUS_I%2fO.kicad_sch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]
2026-09-01 layout work
    [A%2fV_Out.kicad_sch, Audio%2fVideo.kicad_sch, BUS_I%2fO.kicad_sch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]
2026-09-03 replace Spartan6 xc6slx25t with cheaper xc6slx65, start re-layout
    [csa_ultracpu.kicad_pcb, fpga_io.kicad_sch, fpga_support.kicad_sch]
2026-09-04 more layout work
    [csa_ultracpu.kicad_pcb, fpga_io.kicad_sch, fpga_support.kicad_sch]
2026-09-06 more layout work, first candidate
    [CPU,RAM,ROM.kicad_sch, csa_ultracpu.kicad_pcb, fpga_io.kicad_sch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]
2026-09-06 layout done
    [A%2fV_Out.kicad_sch, Audio%2fVideo.kicad_sch, BUS_I%2fO.kicad_sch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]
2026-09-07 fix a few vias under bga
    [csa_ultracpu.kicad_pcb]
2026-09-07 test release
    [BOM-csa_ultracpu.csv, CPU,RAM,ROM.kicad_sch, Power.kicad_sch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]
2026-09-07 as submitted
    [BOM-csa_ultracpu.csv, USB.kicad_sch, csa_ultracpu.kicad_pcb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]
2026-09-09 fix diode footprint in bom
    [BUS_I%2fO.kicad_sch, csa_ultracpu.kicad_pcb]

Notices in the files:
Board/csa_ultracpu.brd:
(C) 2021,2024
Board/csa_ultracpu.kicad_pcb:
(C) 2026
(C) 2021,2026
